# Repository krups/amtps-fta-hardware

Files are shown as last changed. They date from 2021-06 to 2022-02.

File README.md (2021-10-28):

# amtps-fta
Design files for the additive manufacturing thermal of thermal protection systems (AMTPS) flight test article (FTA)

See [documentation/amtps-fta-harware-manual.pdf](documentation/amtps-fta-harware-manual.pdf)

For an overview of the work, see the presentation here [documentation/presentation.pdf](documentation/presentation.pdf)

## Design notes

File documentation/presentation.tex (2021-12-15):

\documentclass[UKenglish]{beamer}

\usetheme{UiB}

\usepackage[utf8]{inputenx} % For æ, ø, å
\usepackage{csquotes}       % Quotation marks
\usepackage{microtype}      % Improved typography
\usepackage{amssymb}        % Mathematical symbols
\usepackage{mathtools}      % Mathematical symbols
\usepackage[absolute, overlay]{textpos} % Arbitrary placement
\setlength{\TPHorizModule}{\paperwidth} % Textpos units
\setlength{\TPVertModule}{\paperheight} % Textpos units
\usepackage{tikz}
\usepackage{pgf}
\usepackage{subcaption}
\usetikzlibrary{overlay-beamer-styles}  % Overlay effects for TikZ
\usepackage[ruled,vlined]{algorithm2e}
\captionsetup[figure]{labelformat=empty}% redefines the caption setup of the figures environment in the beamer class.

\author{Matt Ruffner}
\title{AMPTS FTA Avionics Design}
%\subtitle{Parzen Windowing}

\newcommand{\ddrev}{E}

\begin{document}

\section{Overview}
% Use
%
%     \begin{frame}[allowframebreaks]{Title}
%
% if the TOC does not fit one frame.
\begin{frame}{Table of contents}
    \tableofcontents[currentsection]
\end{frame}

%%%%%%%%%%%%%%%%%%%%%%%%%%%%%%%%%%%%%%%%%%%%%
%%%%%%%%%%%%%%%%%%%%%%%%%%%%%%%%%%%%%%%%%%%%%
%%%%%%%%%%%%%%%%%%%%%%%%%%%%%%%%%%%%%%%%%%%%%
\section{Requirements}
\label{sec:requirements}
\hidelogo
\begin{frame}[allowframebreaks]{Requirements}

	Based on revision (\ddrev) of the flight test requirements document.
	
	\begin{enumerate}
		\item Instrumentation and telemetry
		\begin{enumerate}
			\item Shall support betwen 8 and 20 thermocouples of varying type
			\item Shall support up to 6 absolute pressure sensors
			\item Shall support at least 1 intertial measurement unit (IMU)
			\item Should support 1 heat flux sensor
			\item Shall contain a GPS for recovery operations, accurate to with 100m
			\item Capsule shall contain an internal barometric pressure sensor 
			\item Telemetry data shall be collected at a minumum of 10Hz
			\item Telemetry data shall be stored to onboard nonvolatile memory that will survive landing
			\item Location telemetry shall be transmitted through a vehicle-to-ground system (e.g. Iridium satellite, Xbee)
			\item Recovery location should be broadcasted at least once every 5 minutes post-flight
		\end{enumerate}
		\item Activation and flight sequencing
		\begin{enumerate}
			\item Shall be powered through the duration of the flight
			\item Shall support continuous operation between -20 deg C and 80 deg C
			\item Shall support pre-launch activation on the ground; should support low power mode prior to deployment
			\item Shall detect and/or sense when deployment has occurred via interfacing with the launch vehicle
			\item Shall transmit in-flight telemetry with position information
			\item In-flight telemetry should contain capsule velocity 
			\item Shall trigger parachute deployment at a specified time
		\end{enumerate}
		\item Physical properties
		\item Avionics hardware shall weigh under or around 0.5kg
		\item Shall cost under \$3,000
	\end{enumerate}
\end{frame}

%%%%%%%%%%%%%%%%%%%%%%%%%%%%%%%%%%%%%%%%%%%%%
%%%%%%%%%%%%%%%%%%%%%%%%%%%%%%%%%%%%%%%%%%%%%
%%%%%%%%%%%%%%%%%%%%%%%%%%%%%%%%%%%%%%%%%%%%%
\section{Overview}
\begin{frame}{Overview}
	
	\begin{figure}
		\centering
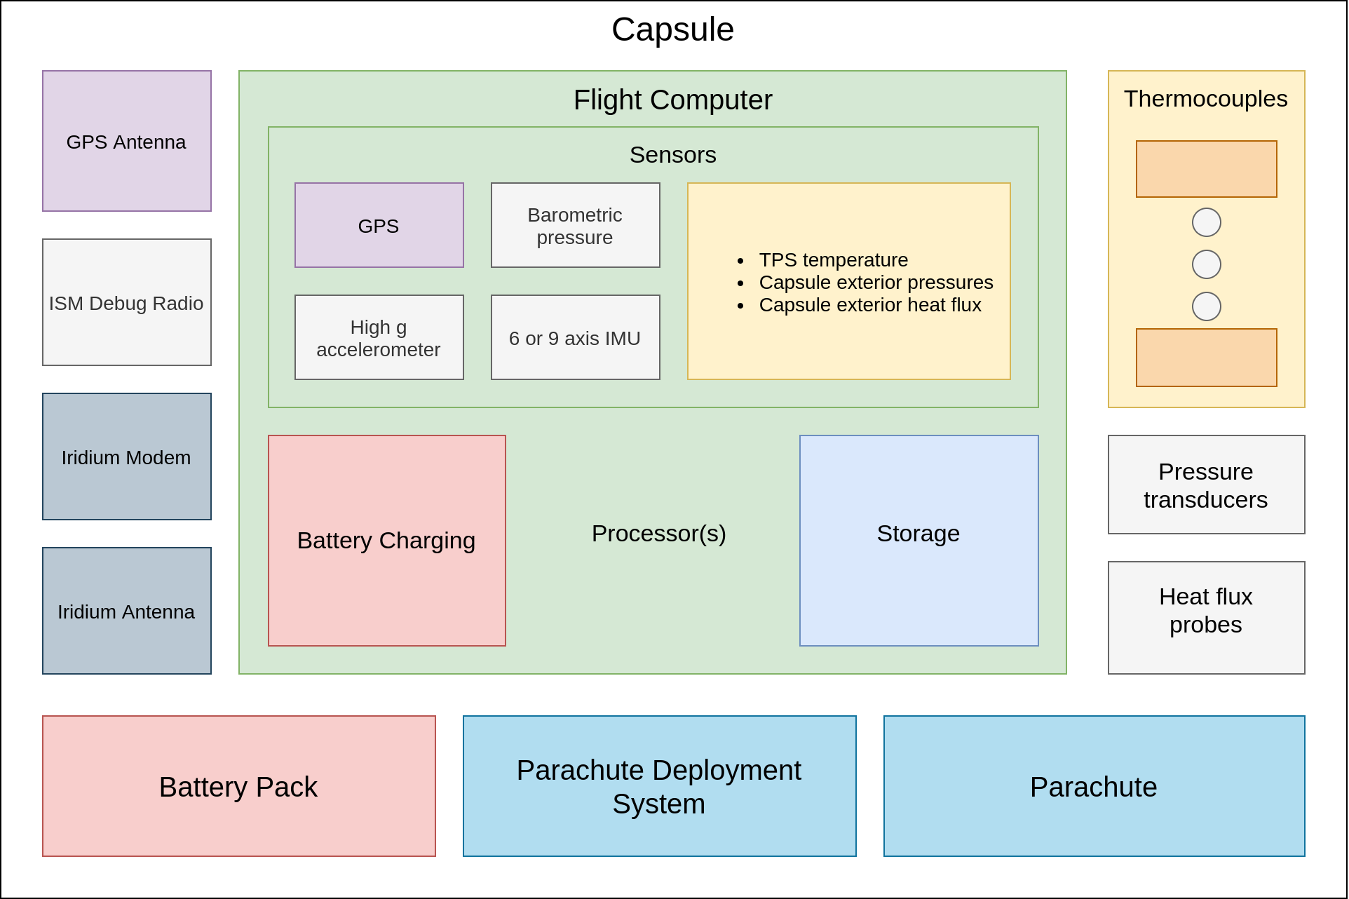
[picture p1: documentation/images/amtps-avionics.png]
		
		%\caption{Capsule component overview, showing the various functional blocks.}
		%\label{fig:capsule-overview}
	\end{figure}

\end{frame}

%%%%%%%%%%%%%%%%%%%%%%%%%%%%%%%%%%%%%%%%%%%%%
%%%%%%%%%%%%%%%%%%%%%%%%%%%%%%%%%%%%%%%%%%%%%
%%%%%%%%%%%%%%%%%%%%%%%%%%%%%%%%%%%%%%%%%%%%%
\section{Temperature and Pressure Measurement}
\begin{frame}{Temperature and Pressure Measurement)}
	
	\begin{figure}[h!]
		\centering
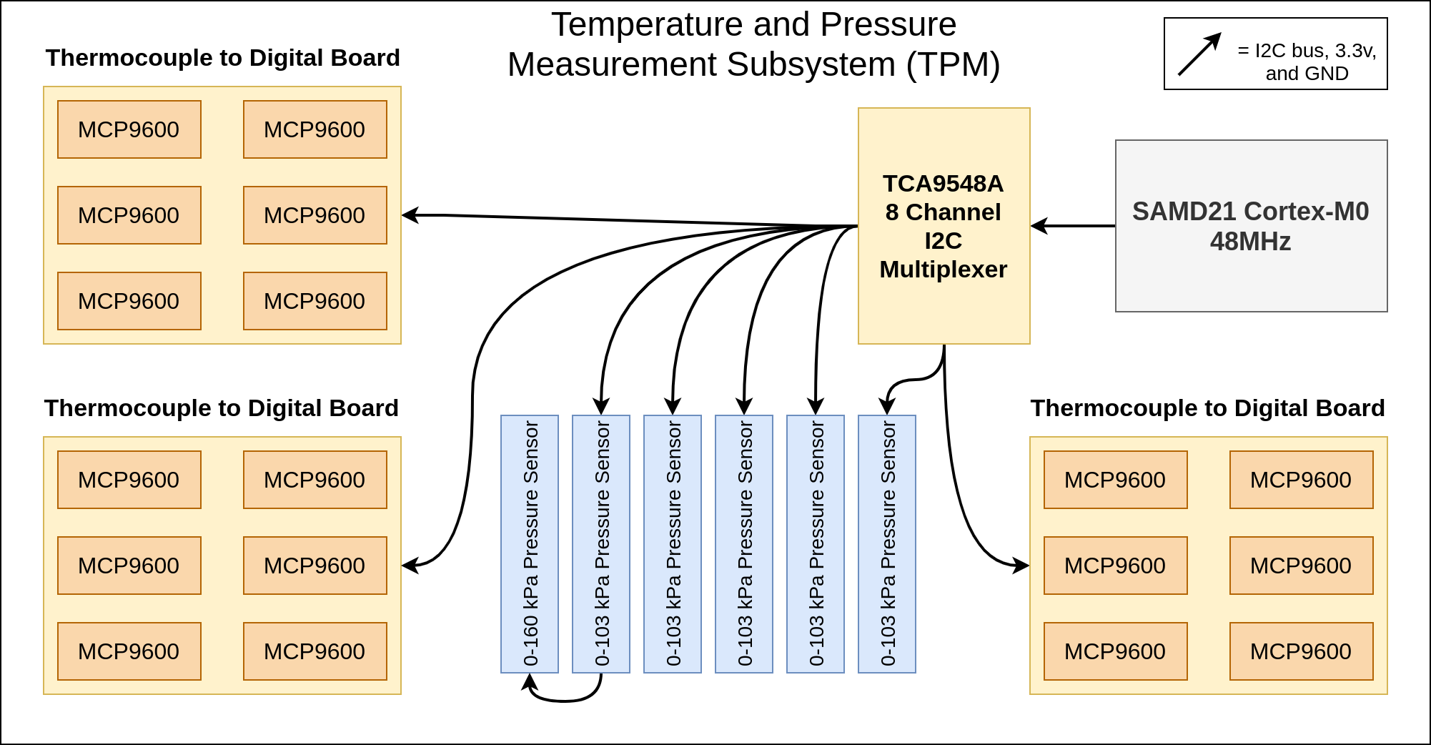
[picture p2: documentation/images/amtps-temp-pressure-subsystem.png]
		
		%\caption{Functional decomposition of the TPMS.}
		%\label{fig:tpms-overview}
	\end{figure}
	
\end{frame}

%%%%%%%%%%%%%%%%%%%%%%%%%%%%%%%%%%%%%%%%%%%%%
%%%%%%%%%%%%%%%%%%%%%%%%%%%%%%%%%%%%%%%%%%%%%
%%%%%%%%%%%%%%%%%%%%%%%%%%%%%%%%%%%%%%%%%%%%%
\section{Command and Data Handling}
\begin{frame}{Command and Data Handling}
	
	\begin{figure}[h!]
		\centering
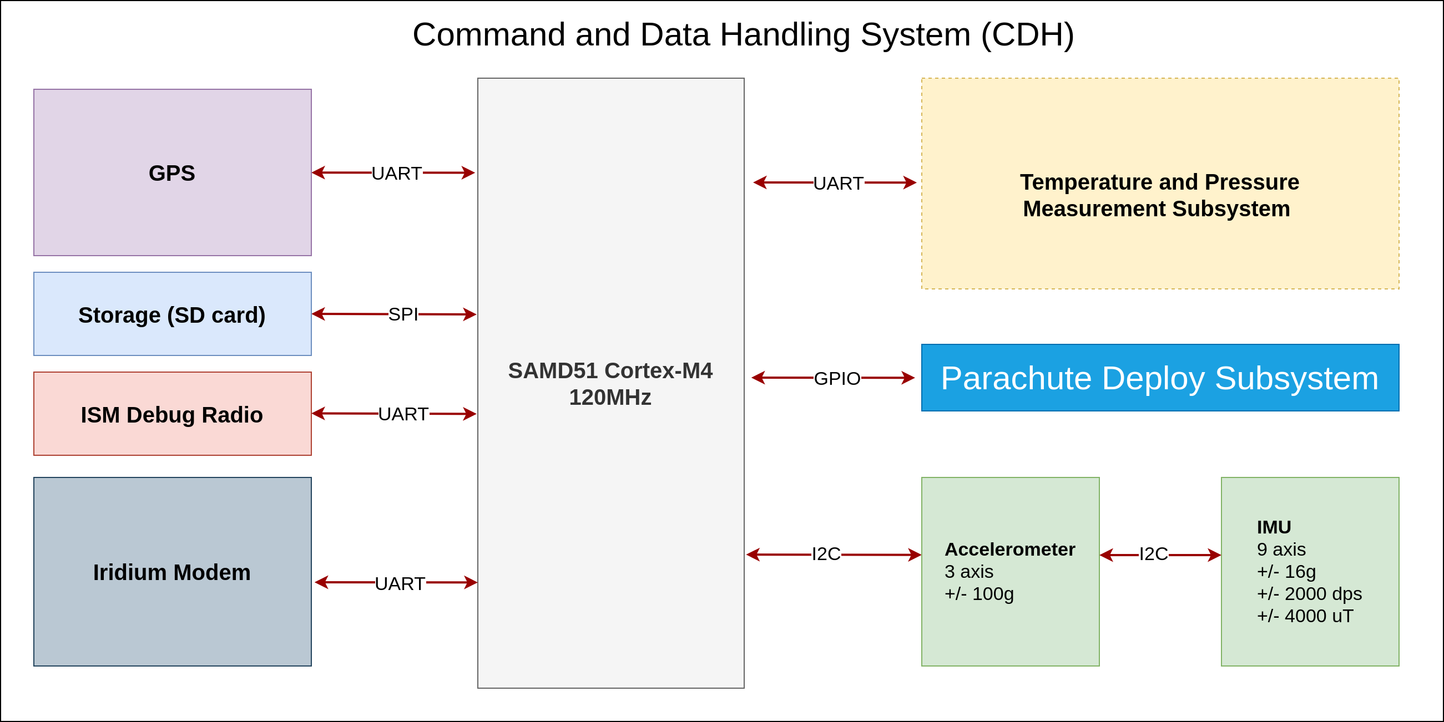
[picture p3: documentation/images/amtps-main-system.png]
		
		%\caption{Main functional components of the capsule and the communication buses between them.}
		%\label{fig:main-overview}
	\end{figure}
	
\end{frame}

%%%%%%%%%%%%%%%%%%%%%%%%%%%%%%%%%%%%%%%%%%%%%
%%%%%%%%%%%%%%%%%%%%%%%%%%%%%%%%%%%%%%%%%%%%%
%%%%%%%%%%%%%%%%%%%%%%%%%%%%%%%%%%%%%%%%%%%%%
\section{Parachute Control}
\begin{frame}{Parachute Control}

	\begin{figure}[h!]
		\centering
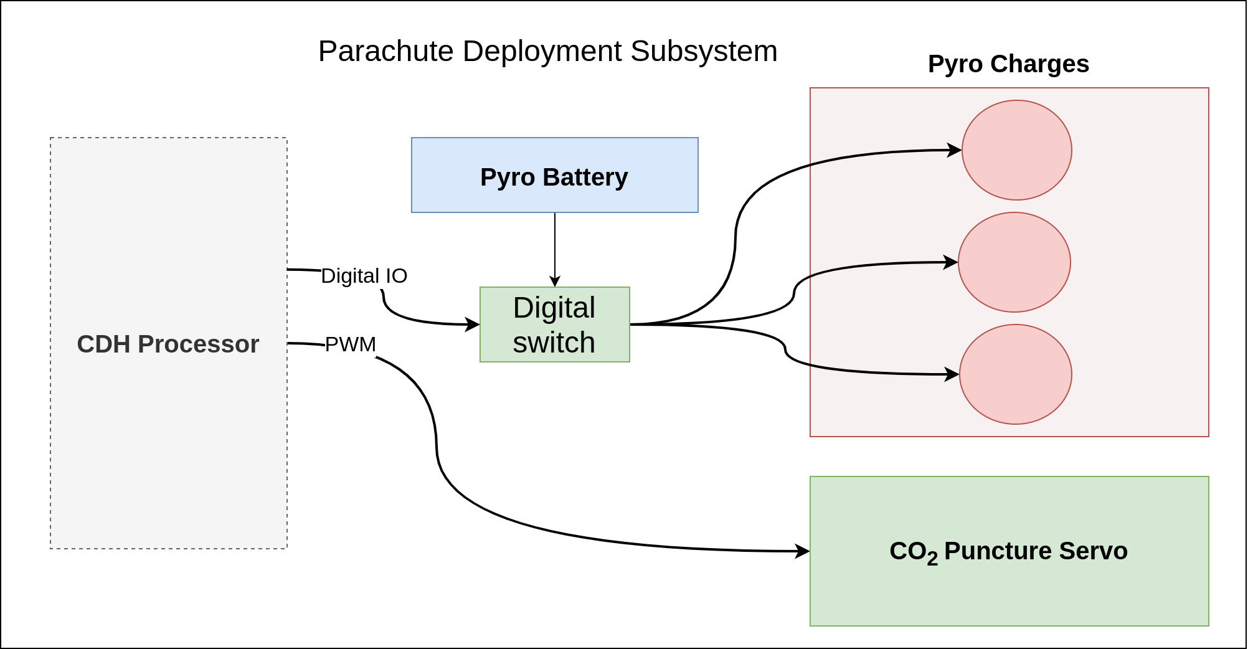
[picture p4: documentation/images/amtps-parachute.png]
		
		%\caption{Main functional components of the capsule and the communication buses between them.}
		%\label{fig:main-overview}
	\end{figure}
	
\end{frame}

%%%%%%%%%%%%%%%%%%%%%%%%%%%%%%%%%%%%%%%%%%%%%
%%%%%%%%%%%%%%%%%%%%%%%%%%%%%%%%%%%%%%%%%%%%%
%%%%%%%%%%%%%%%%%%%%%%%%%%%%%%%%%%%%%%%%%%%%%
\section{Prototype Hardware}
\begin{frame}[allowframebreaks]{Prototype Hardware}
	
	\begin{itemize}
		\item TC to digital expansion
	\end{itemize}
	\begin{figure}[h!]
		\begin{subfigure}{0.4\textwidth}
		\centering
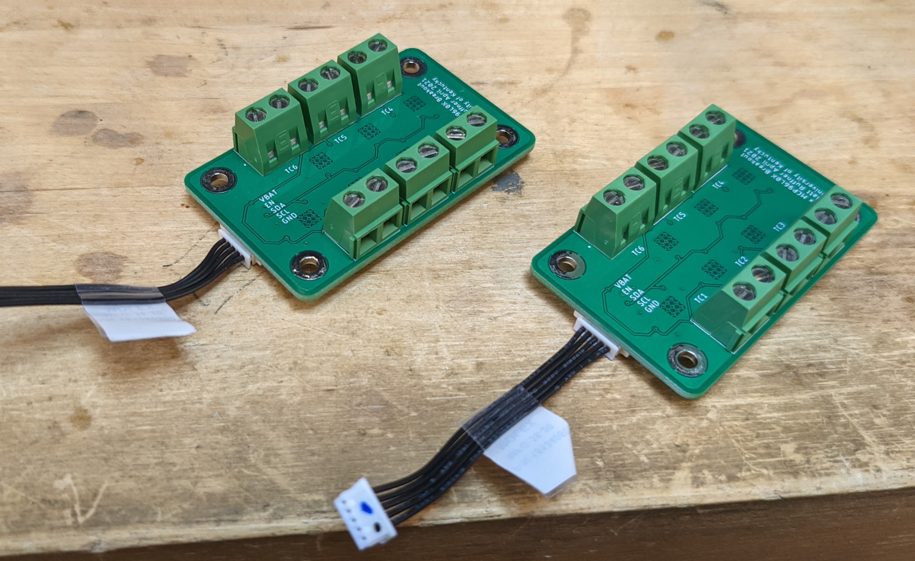
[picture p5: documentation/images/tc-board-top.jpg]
		
		\caption{Six channel MCP9600 breakout (top).}
		%\label{fig:tpms-overview}
		\end{subfigure}
		\qquad
		\begin{subfigure}{0.4\textwidth}
			\centering
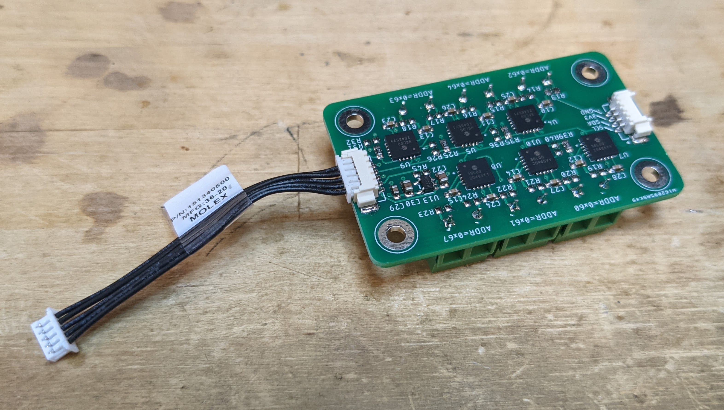
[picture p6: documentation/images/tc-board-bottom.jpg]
			
			\caption{Six channel MCP9600 breakout (bottom).}
			%\label{fig:tpms-overview}
		\end{subfigure}
		%\label{fig:tpms-overview}
	\end{figure}
	
	\begin{itemize}
		\item Semtech SX1276-based 915 MHz ISM band LoRa modem for capsule-to-ground telemetry
		\item 1S2P LiPo for power
		\item Physical switch at capsule/vehicle interface for activation.
	\end{itemize}
	
	\begin{figure}[h!]
		\centering
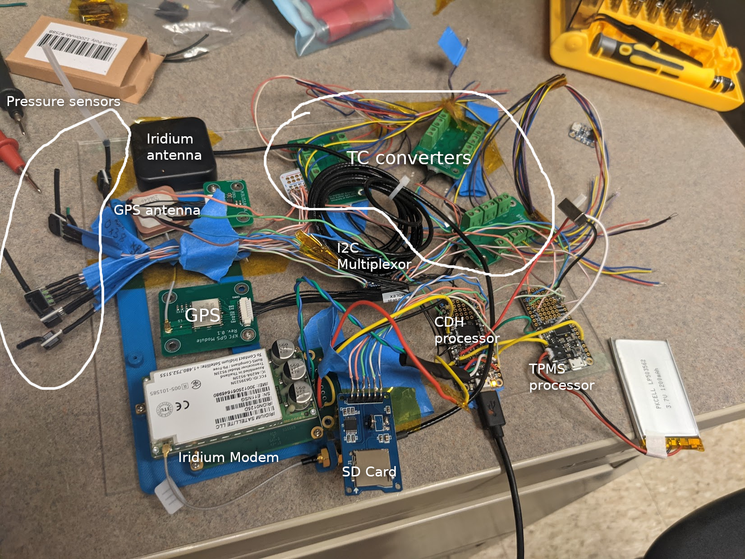
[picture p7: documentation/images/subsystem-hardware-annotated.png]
		
		\caption{Full system.}
		%\label{fig:tpms-overview}
	\end{figure}

\end{frame}

\section{Final Design Considerations}
\begin{frame}[allowframebreaks]{Final Design Considerations}
	
	\begin{itemize}
		\item \textbf{Supply chain constraints} - bare SAMD21/51 processors are hard to find on Digikey/Mouser etc. but pre-made development boards from Adafruit are still available.
	\end{itemize}	

	\begin{figure}[h!]
		\begin{subfigure}{0.4\textwidth}
			\centering
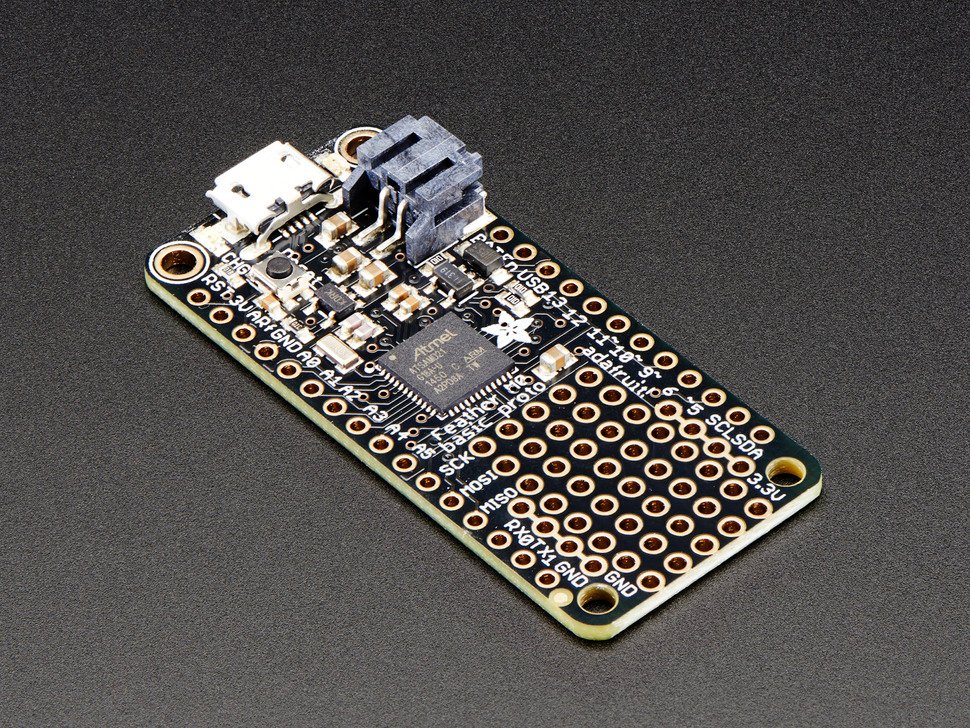
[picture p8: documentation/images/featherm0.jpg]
			
			\caption{Adafruit SAMD21 48MHz Cortex-M0 carrier \tiny{\url{https://www.adafruit.com/product/2772}}}
		\end{subfigure}
		\qquad
		\begin{subfigure}{0.4\textwidth}
			\centering
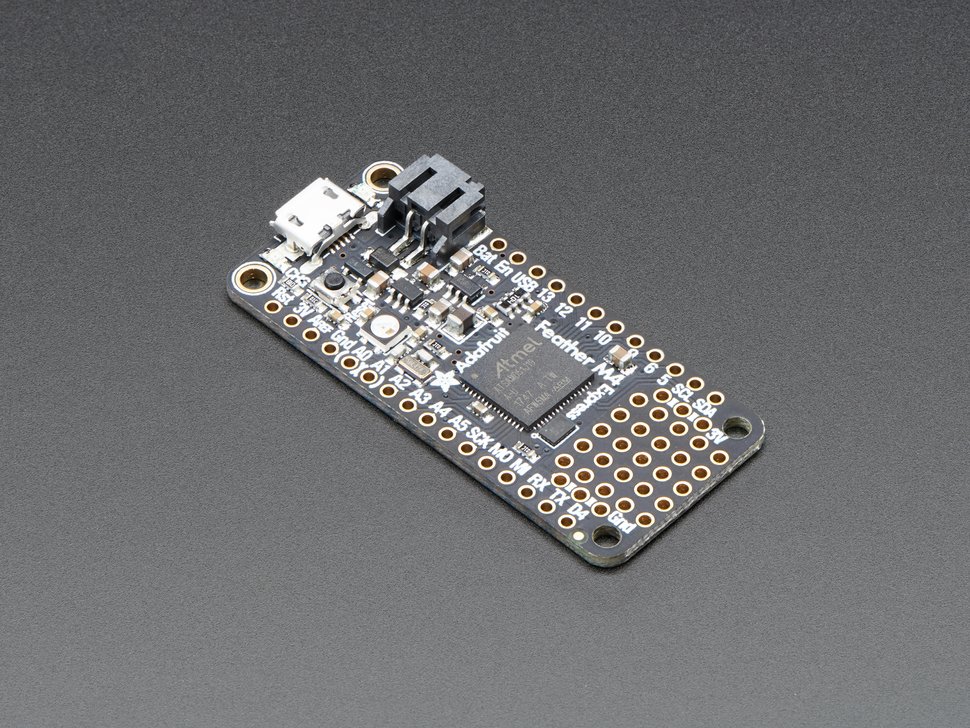
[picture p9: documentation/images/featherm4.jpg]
			
			\caption{Adafruit SAMD51 120MHz Cortex-M4 carrier \tiny{\url{https://www.adafruit.com/product/3857}}}
		\end{subfigure}
		%\label{fig:tpms-overview}
	\end{figure}

	\begin{itemize}
		\item \textbf{Plenty of processor overhead} - recording 12 channels of IMU and accelerometer data to an SD card at 100Hz requires strict timing and interrupt handling
		\item Current planned revision is to separate IMU and high-g accelerometer interfacing to its own Cortex-M0 processor.
	\end{itemize}

	\begin{figure}
		\centering
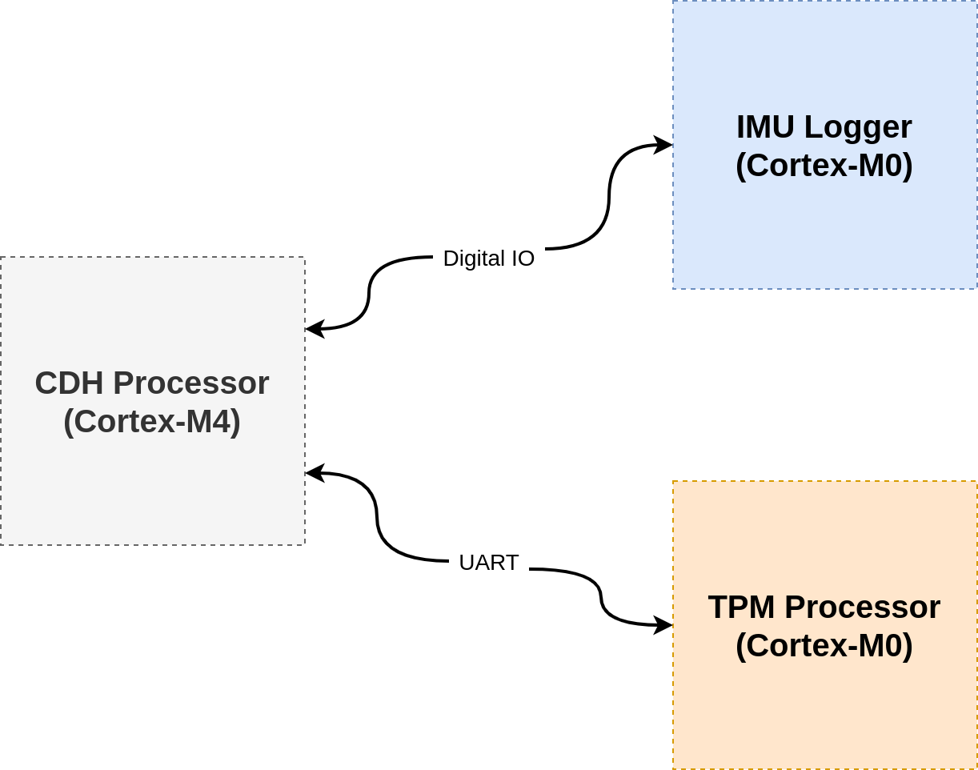
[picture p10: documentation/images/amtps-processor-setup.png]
		
		\caption{Processor separation of responsibilities.}		
	\end{figure}

\end{frame}

\section{Software Design}
\begin{frame}{Software Overview}
	
	\begin{itemize}
		\item Adafruit Feather line of boards is Arduino compatible
		\item SAMD21/51 series of processors has easily reconfigurable SERCOMs to support multiple hardware serial ports 
		\item FreeRTOS tasks, queues, and semaphores allow for simple and reliable transfer of data and atomic hardware access
		\item Open source libraries available for all sensors
		\item All hardware design files and firmware, as well as ground assist tools for plotting recorded data are version controlled on private Github repositories:
		\begin{itemize}
			\item \url{https://github.com/krups/amtps-fta-hardware}
			\item \url{https://github.com/krups/amtps-fta-software}
		\end{itemize}	
	\end{itemize}
	
\end{frame}

\section{PCB Designs}
\begin{frame}[allowframebreaks]{Rev 2 board designs}
	
	\begin{figure}[h!]
		\centering
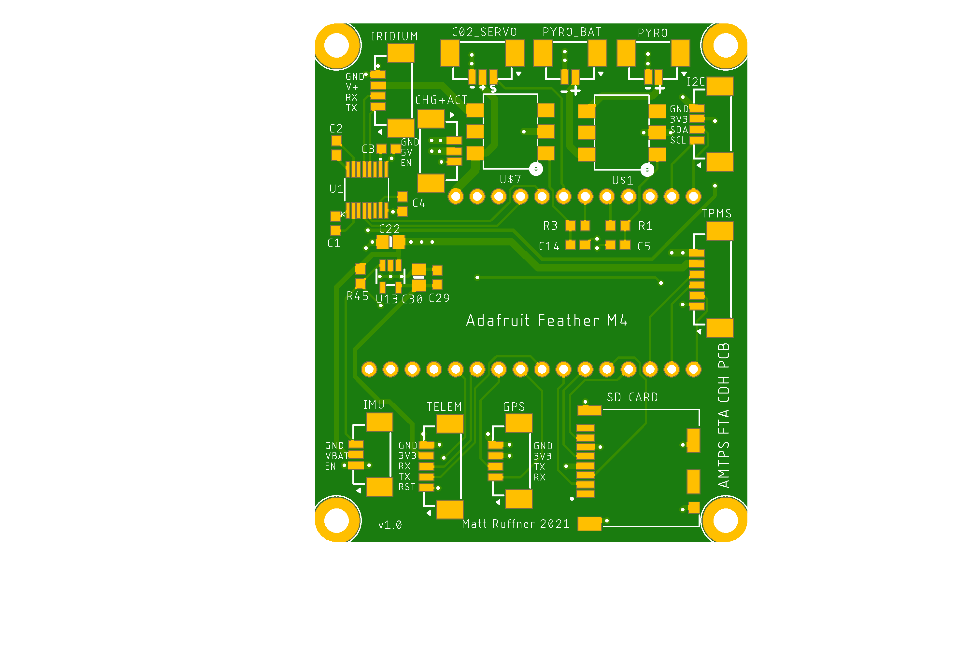
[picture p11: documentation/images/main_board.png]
		
		\caption{CDH processor carrier PCB.}
		%\label{fig:tpms-overview}
	\end{figure}

	\begin{figure}[h!]
		\centering
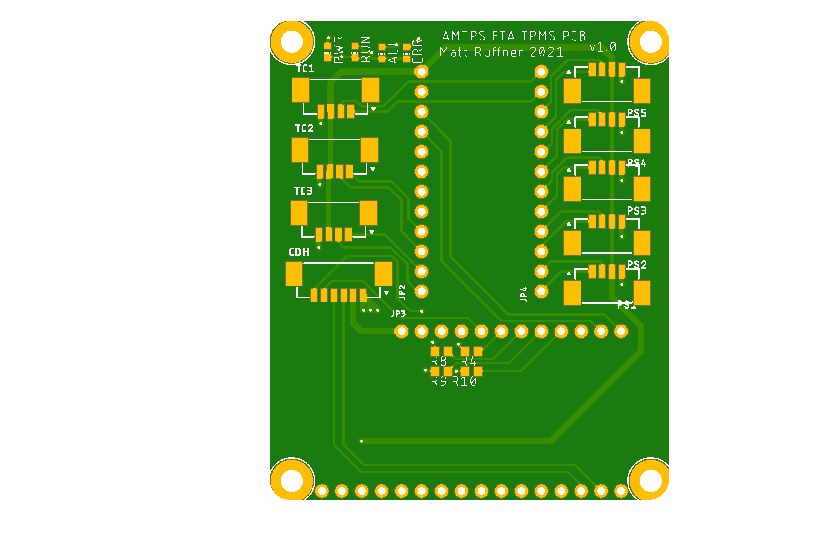
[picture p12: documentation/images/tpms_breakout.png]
		
		\caption{TMP processor carrier PCB.}
		%\label{fig:tpms-overview}
	\end{figure}

	\begin{figure}[h!]
		\centering
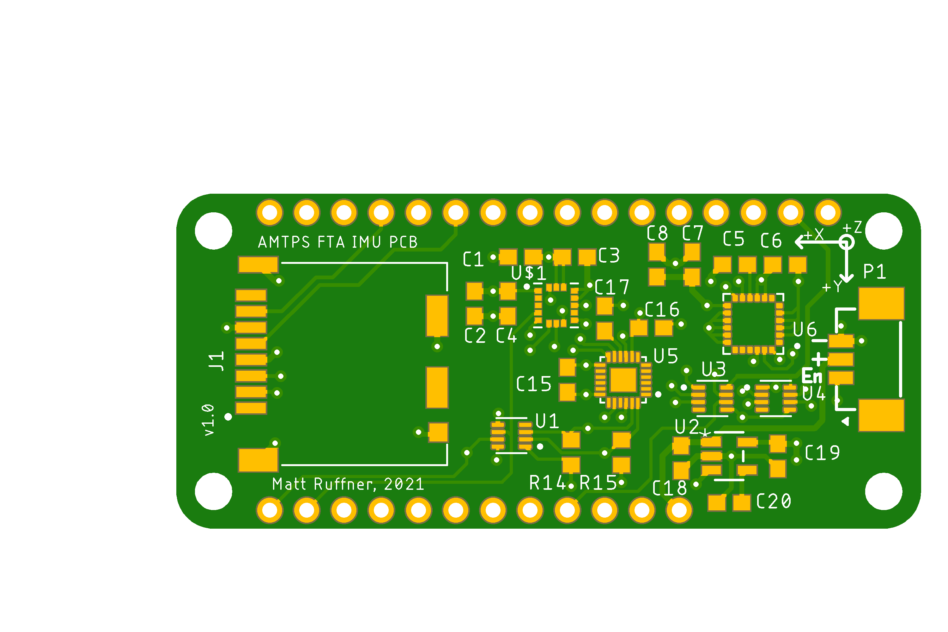
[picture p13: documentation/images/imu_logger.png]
		
		\caption{IMU logger processor carrier PCB.}
		%\label{fig:tpms-overview}
	\end{figure}

\end{frame}

\section{Schematics}

\begin{frame}[allowframebreaks]{Feather M0/M4 Schematics}
\begin{figure}[H]
	\centering
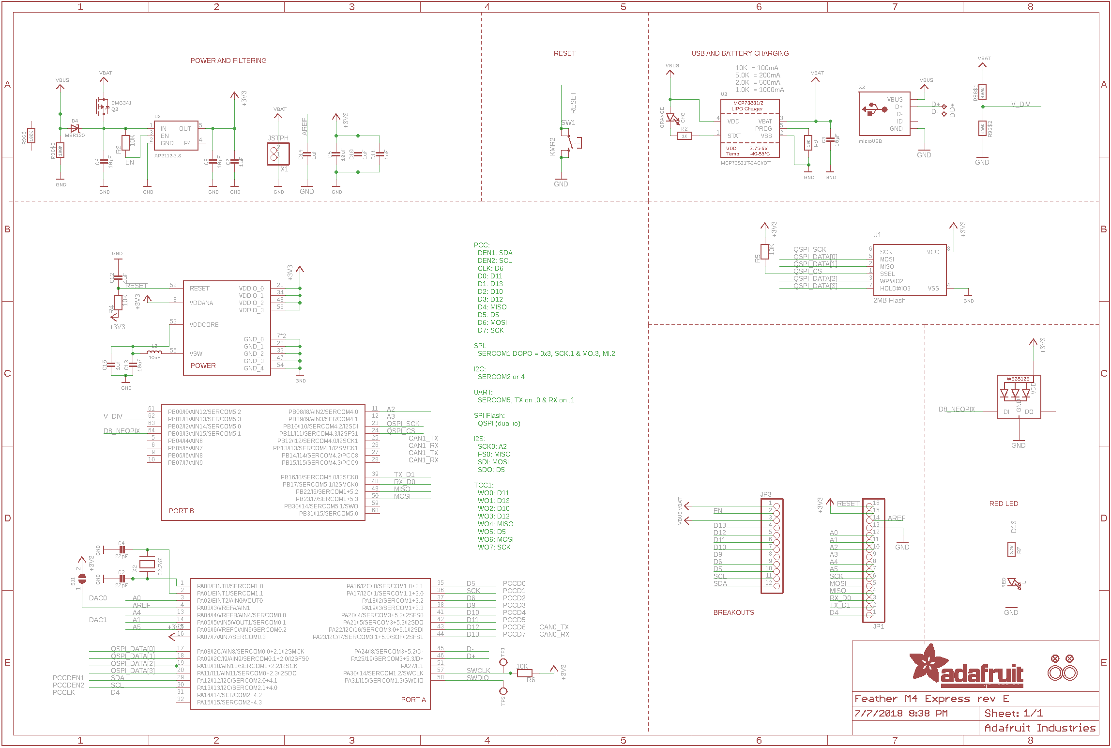
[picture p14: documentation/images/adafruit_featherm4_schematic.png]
	
	%\caption{Feather M4 Express schematic, used in the main CDH board.}
	\label{fig:schematic-featherm4}
\end{figure}
\begin{figure}[H]
	\centering
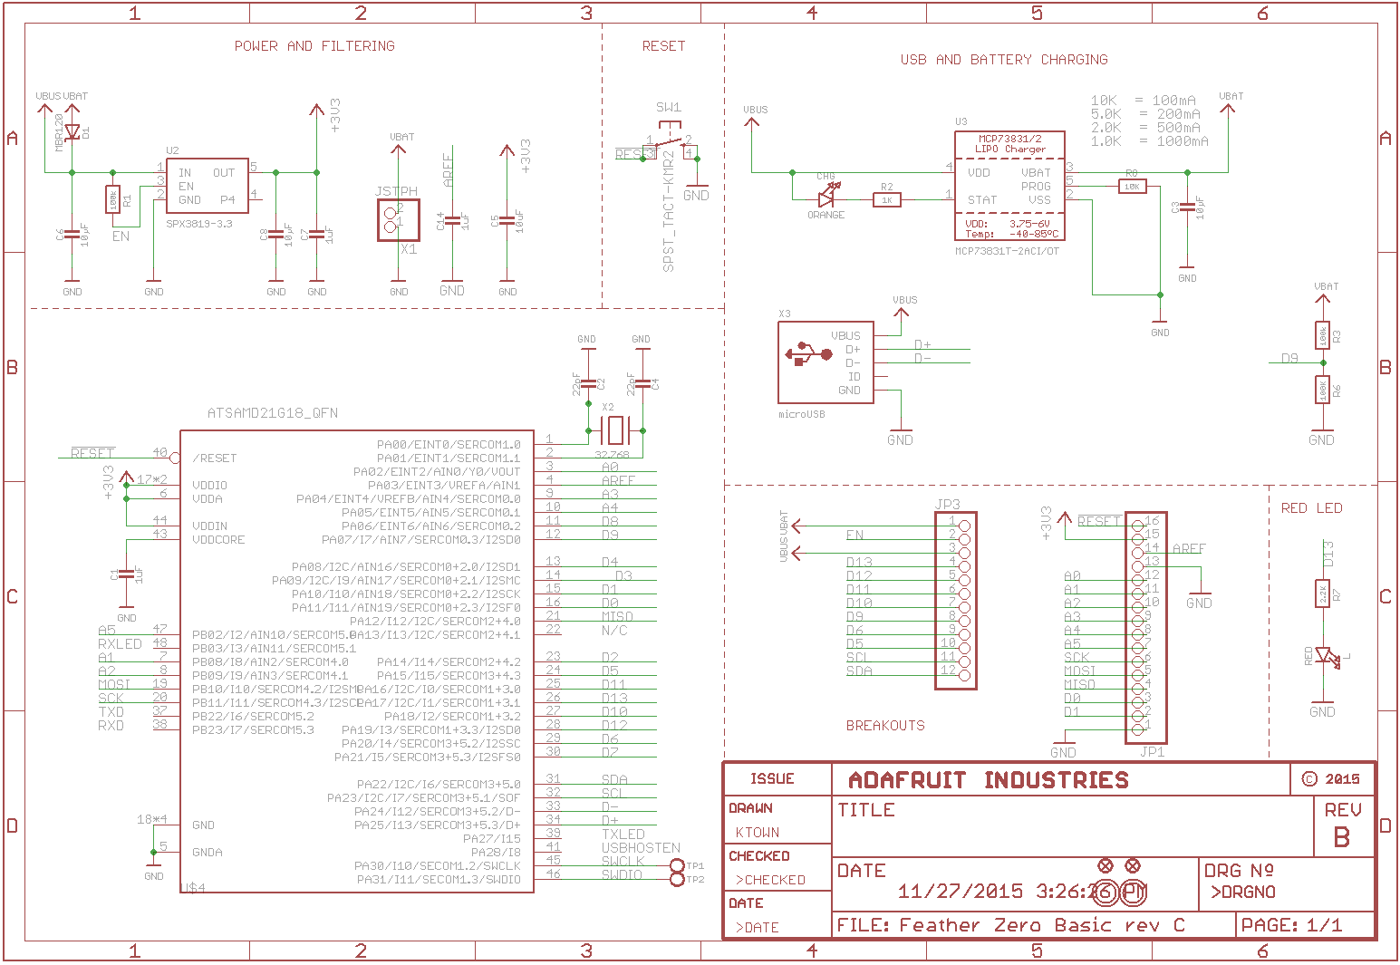
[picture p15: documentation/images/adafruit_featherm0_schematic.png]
	
	%\caption{Feather M0 schematic, used in the IMU logger and TPM boards.}
	\label{fig:schematic-featherm0}
\end{figure}
\end{frame}

\begin{frame}[allowframebreaks]{TC to Digital Schematics}
%Figures \ref{fig:schematic-tc-breakout-p1} and \ref{fig:schematic-tc-breakout-p2} show the schematics of the 6 channel TC to digital converter breakout board.
\begin{figure}[H]
	\centering
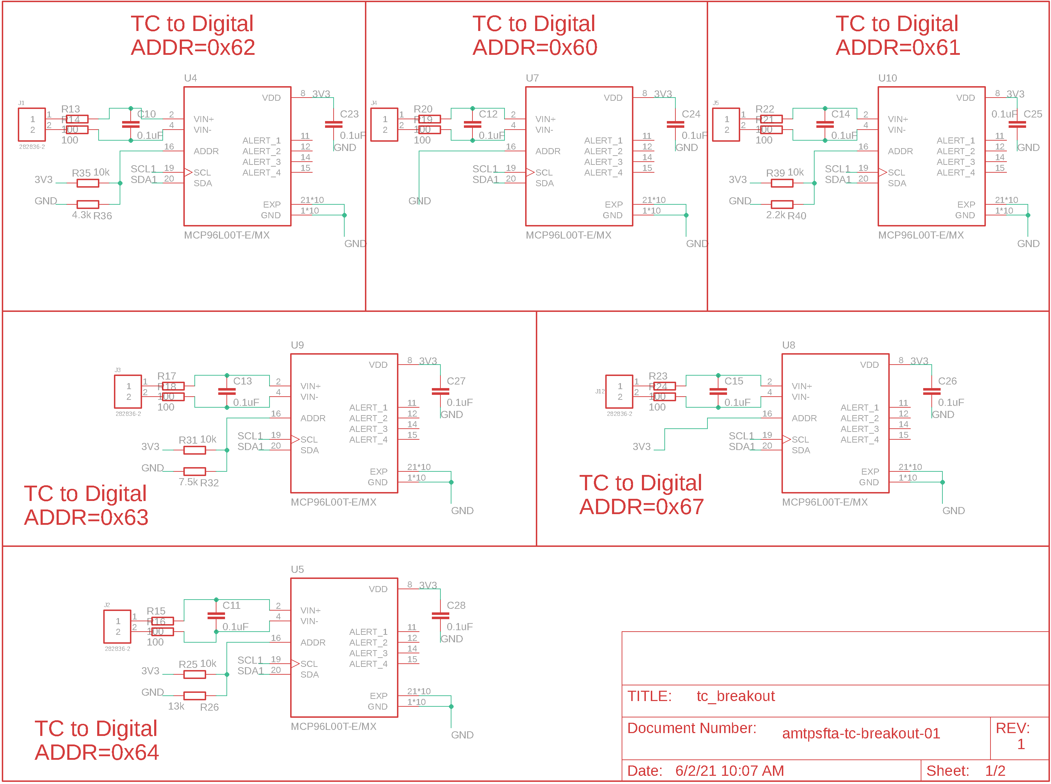
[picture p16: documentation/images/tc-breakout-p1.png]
	
	%\caption{TC to digital schematics, page 1/2}
	\label{fig:schematic-tc-breakout-p1}
\end{figure}

\begin{figure}[H]
	\centering
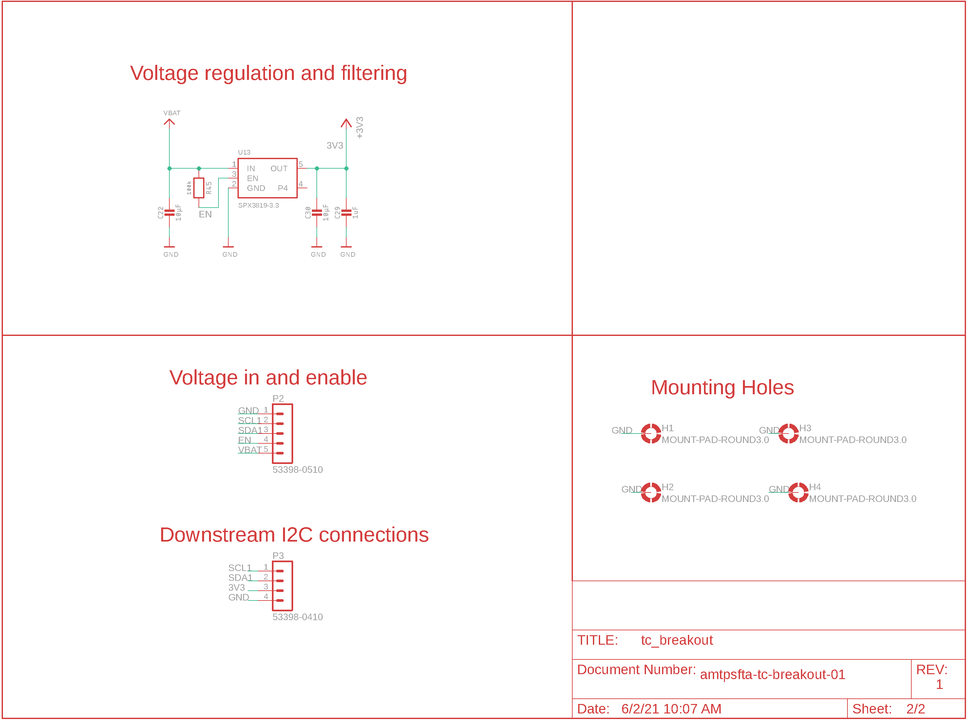
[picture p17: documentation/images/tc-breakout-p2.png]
	
	%\caption{TC to digital schematics, page 2/2}
	\label{fig:schematic-tc-breakout-p2}
\end{figure}
\end{frame}

\begin{frame}[allowframebreaks]{Main CDH Schematics}
%Figures \ref{fig:schematic-cdh-p1} and \ref{fig:schematic-cdh-p2} show the schematics of the main CDH PCB.
\begin{figure}[H]
	\centering
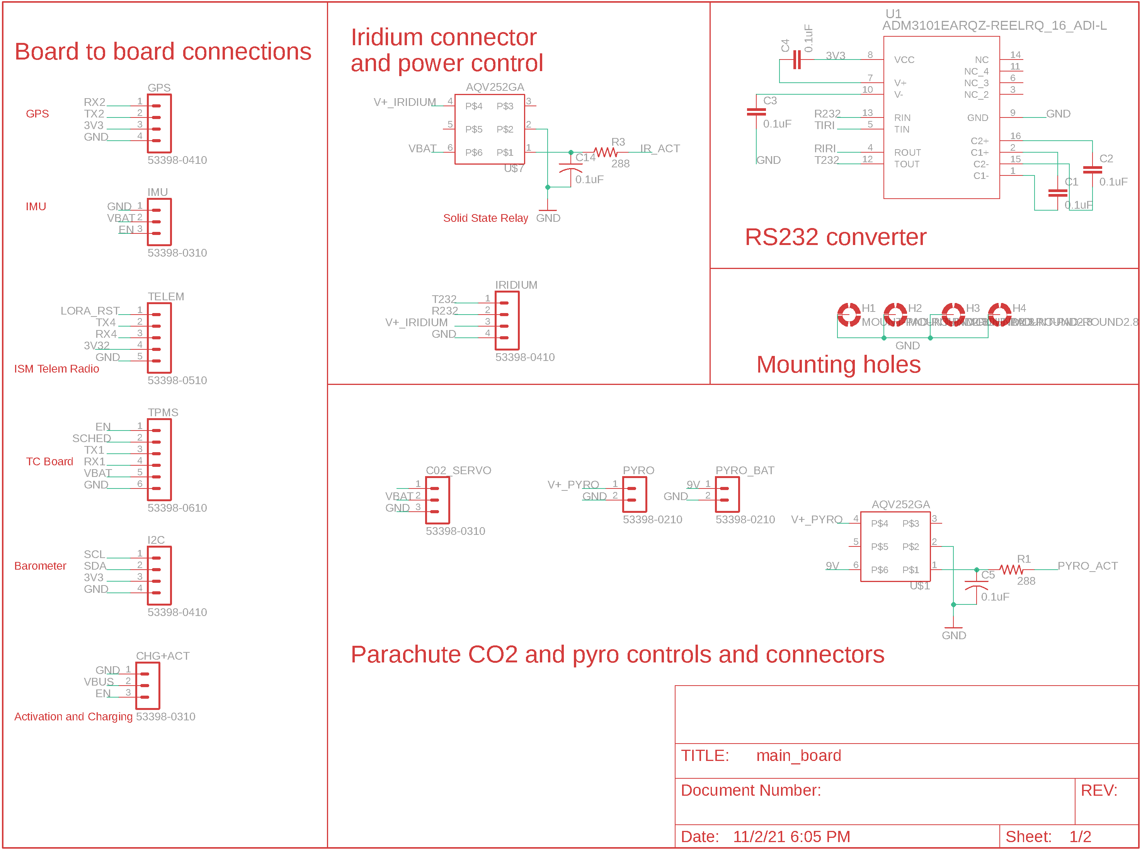
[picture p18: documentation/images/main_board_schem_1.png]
	
	%\caption{Main CDH schematics, page 1/2}
	\label{fig:schematic-cdh-p1}
\end{figure}
\begin{figure}[H]
	\centering
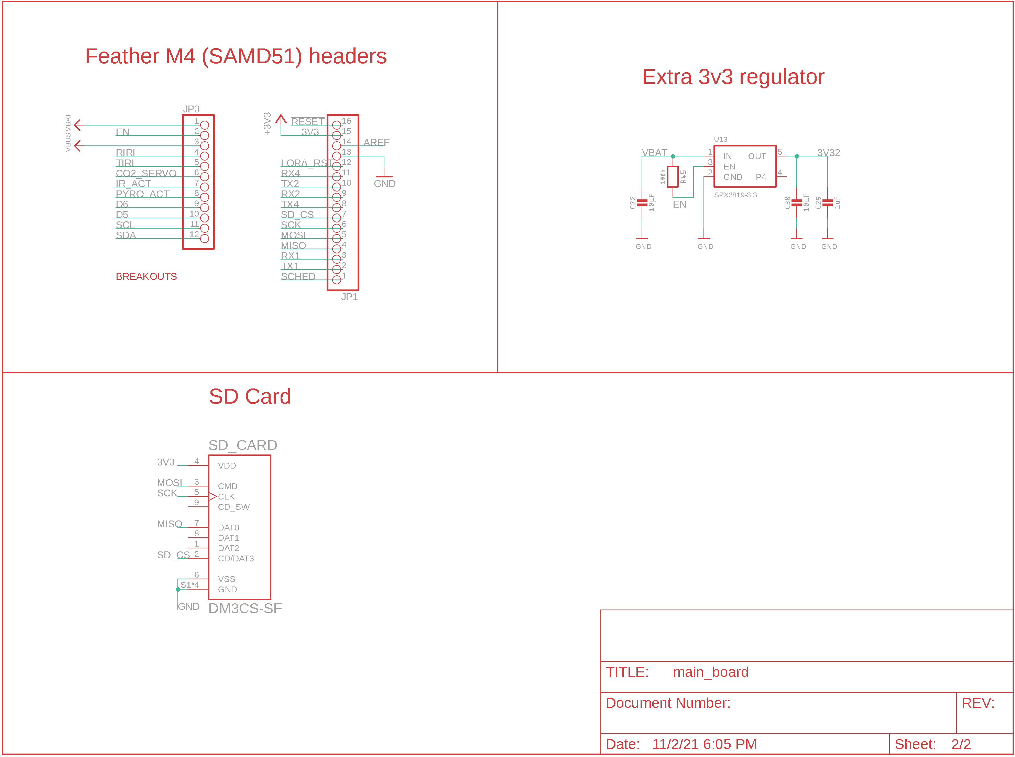
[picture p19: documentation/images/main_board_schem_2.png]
	
	%\caption{Main CDH schematics, page 2/2}
	\label{fig:schematic-cdh-p2}
\end{figure}
\end{frame}

\begin{frame}[allowframebreaks]{TPM Schematics}
%Figures \ref{fig:schematic-tpm-p1} and \ref{fig:schematic-tpm-p2} show the schematics of the TPM subsystem PCB.
\begin{figure}[H]
	\centering
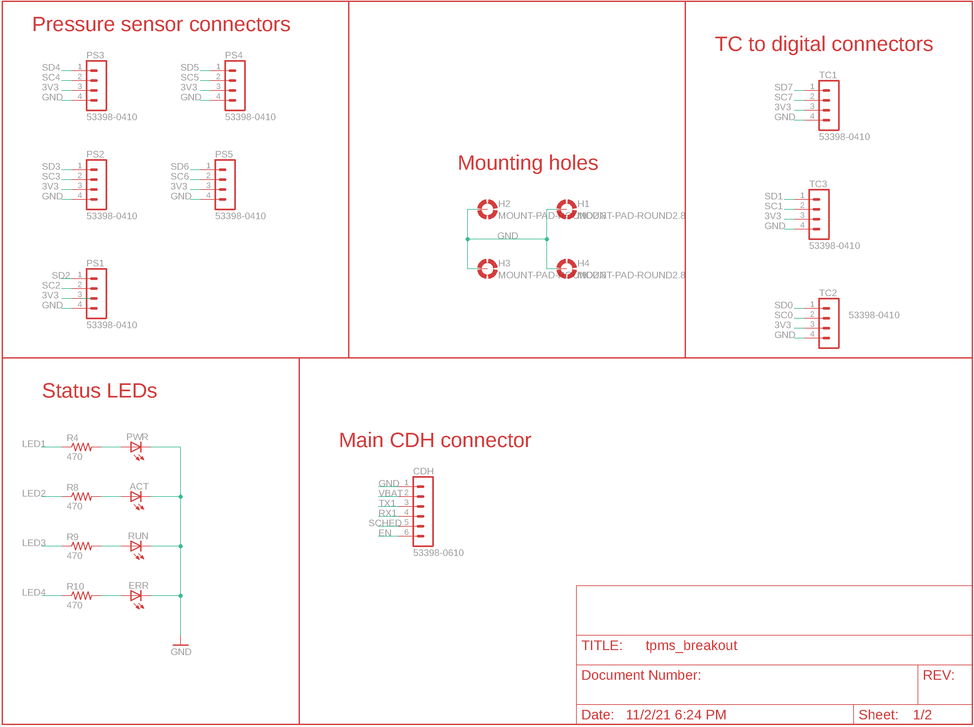
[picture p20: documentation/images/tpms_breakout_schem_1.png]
	
	%\caption{TPM schematics, page 1/2}
	\label{fig:schematic-tpm-p1}
\end{figure}
\begin{figure}[H]
	\centering
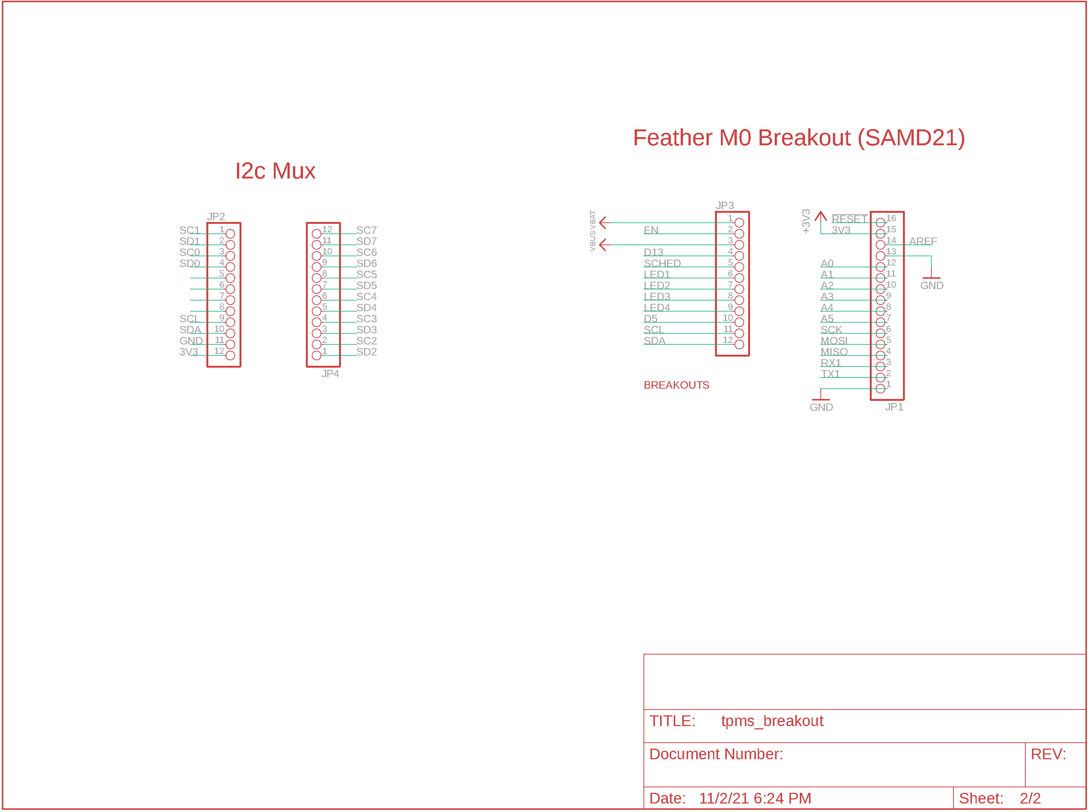
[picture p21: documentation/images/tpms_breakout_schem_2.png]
	
	%\caption{TPM schematics, page 2/2}
	\label{fig:schematic-tpm-p2}
\end{figure}
\end{frame}

\begin{frame}[allowframebreaks]{IMU Logger Schematics}
%Figures \ref{fig:schematic-imu-p1}, \ref{fig:schematic-imu-p2}, and \ref{fig:schematic-imu-p3} show the schematics of the IMU logger PCB.
\begin{figure}[H]
	\centering
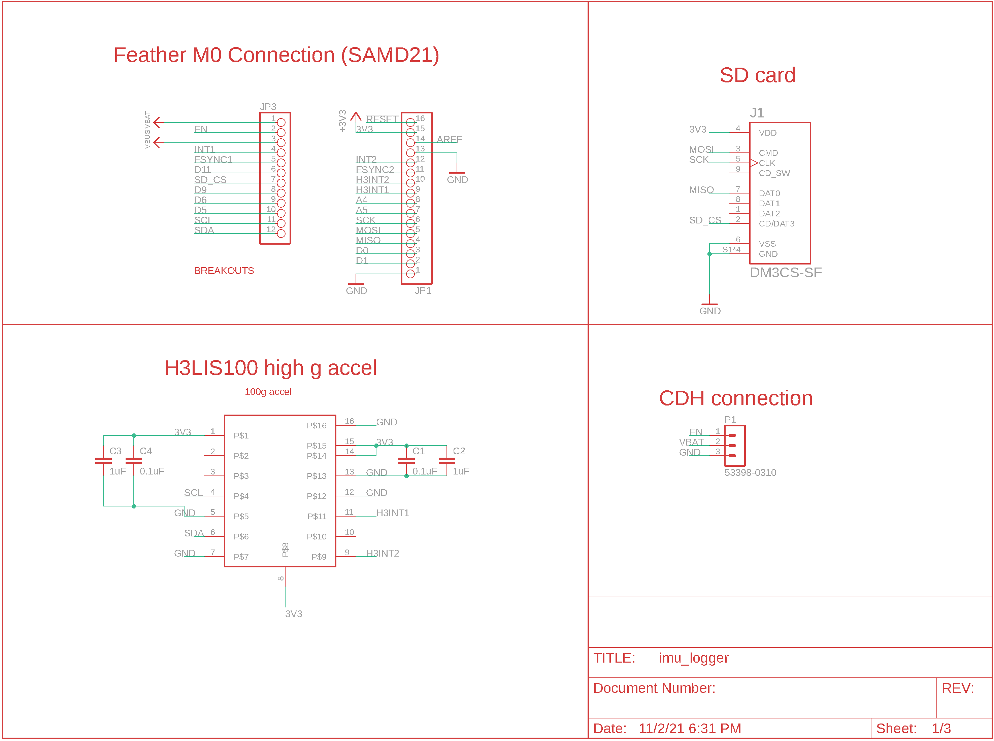
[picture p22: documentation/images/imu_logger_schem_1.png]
	
	%\caption{IMU logger schematics, page 1/3}
	\label{fig:schematic-imu-p1}
\end{figure}
\begin{figure}[H]
	\centering
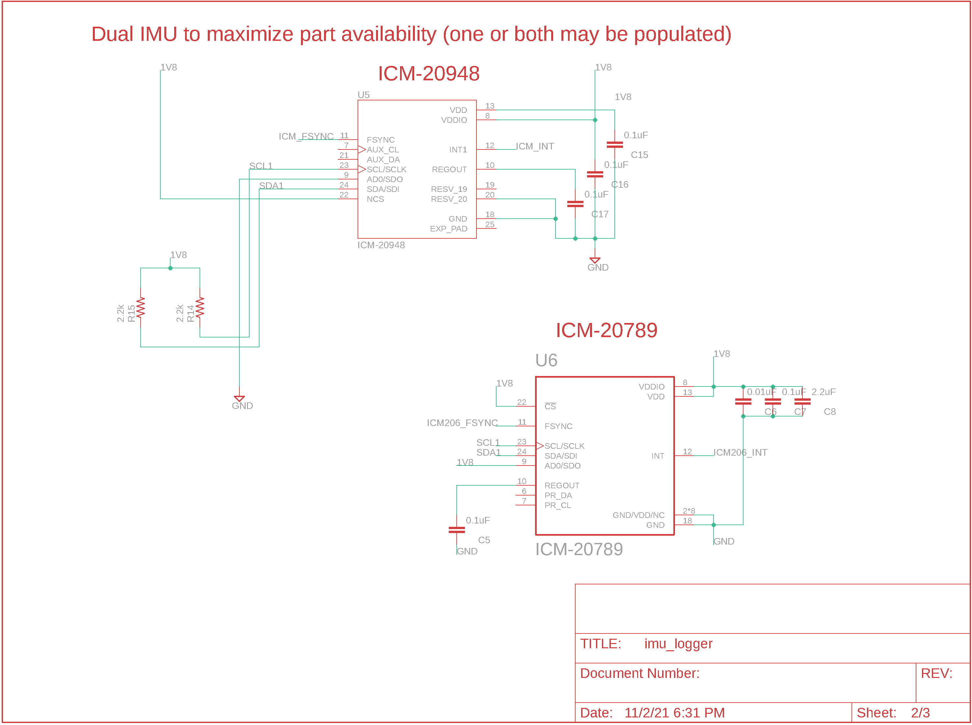
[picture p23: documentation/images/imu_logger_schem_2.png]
	
	%\caption{IMU logger schematics, page 2/3}
	\label{fig:schematic-imu-p2}
\end{figure}
\begin{figure}[H]
	\centering
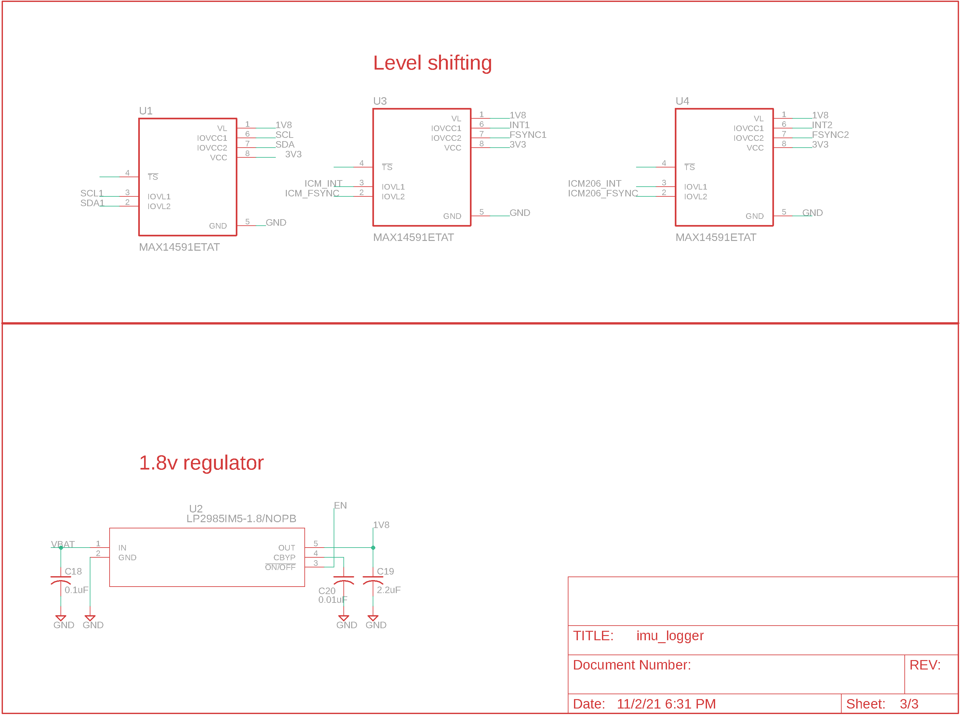
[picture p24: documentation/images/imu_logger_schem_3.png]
	
	%\caption{Page 3/3}
	\label{fig:schematic-imu-p3}
\end{figure}
\end{frame}

\end{document}

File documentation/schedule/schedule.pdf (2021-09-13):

Task | June | July | August | September | October | November | December

Outline mission profile and develop software for activation, data acquisition, mission timing, and parachute deployment

Assemble and test sensor evaluation boards and validate data acquisition hardware setup

Evaluate Iridium as a vehicle-to-ground telemetry system and verify there is no interference with GPS reciever

Determine most effective power distribution and charging system considering all system componets and durability requirements

Redesign temperature and pressure measurement subsystem to be more compact and easier for integration

Experiment with syntactic foam encasement of avionics

Experiment with durable storage and ways of transferring once avionics are encased in syntactic foam

Discussions about electrical interface with launch vehicle

Order revised boards, power electronics, and any needed components

Assemble revised hardware and build the full set of capsule hardware for mission simulation testing

Subsystem testing and test hardware integration

Test hardware complete, ready to build flight hardware + buffer

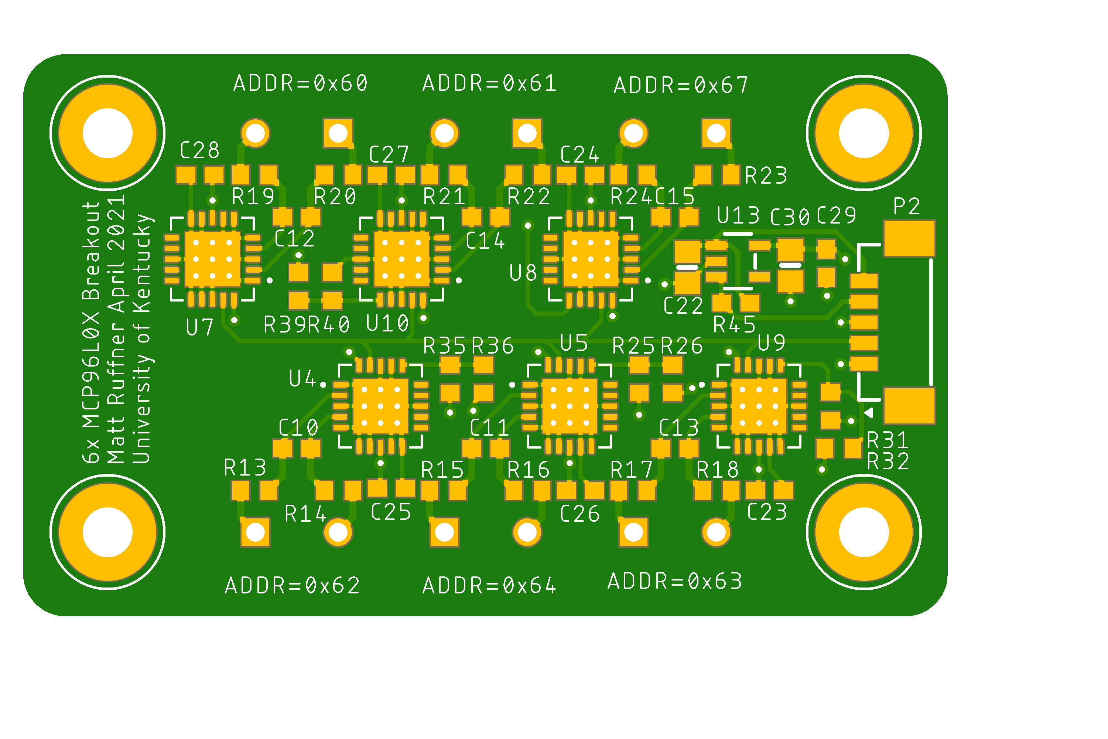
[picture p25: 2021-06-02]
pcb/tc_breakout/images/tc_breakout_top.png

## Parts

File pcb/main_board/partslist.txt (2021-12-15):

Partlist

Exported from main_board.sch at 12/15/21 12:45 AM

EAGLE Version 9.6.2 Copyright (c) 1988-2020 Autodesk, Inc.

Assembly variant: 

Part      Value                    Device                    Package                      Library             Sheet

C02_SERVO 53398-0310               53398-0310                53398-0310                   con-molex-picoblade 1
C5        0.1uF                    C-USC0603                 C0603                        adafruit            1
C6        0.1uF                    C-EUC0603                 C0603                        rcl                 1
C7        0.1uF                    C-EUC0603                 C0603                        rcl                 1
C8        0.1uF                    C-EUC0603                 C0603                        rcl                 1
C9        0.1uF                    C-EUC0603                 C0603                        rcl                 1
C14       0.1uF                    C-USC0603                 C0603                        adafruit            1
C22       10µF                     CAP_CERAMIC0805-NOOUTLINE 0805-NO                      microbuilder        2
C29       1uF                      CAP_CERAMIC0603_NO        0603-NO                      microbuilder        2
C30       10µF                     CAP_CERAMIC0805-NOOUTLINE 0805-NO                      microbuilder        2
CHG+ACT   53398-0310               53398-0310                53398-0310                   con-molex-picoblade 1
GPS       53398-0410               53398-0410                53398-0410                   con-molex-picoblade 1
H1        MOUNT-PAD-ROUND2.8       MOUNT-PAD-ROUND2.8        2,8-PAD                      holes               1
H2        MOUNT-PAD-ROUND2.8       MOUNT-PAD-ROUND2.8        2,8-PAD                      holes               1
H3        MOUNT-PAD-ROUND2.8       MOUNT-PAD-ROUND2.8        2,8-PAD                      holes               1
H4        MOUNT-PAD-ROUND2.8       MOUNT-PAD-ROUND2.8        2,8-PAD                      holes               1
I2C       53398-0410               53398-0410                53398-0410                   con-molex-picoblade 1
IMU       53398-0310               53398-0310                53398-0310                   con-molex-picoblade 1
IRIDIUM   53398-0410               53398-0410                53398-0410                   con-molex-picoblade 1
J1        MEM2067-02-180-00-A_REVB MEM2067-02-180-00-A_REVB  GCT_MEM2067-02-180-00-A_REVB MEM20267            2
JMP1      0R-JUMPA                 0R-JUMPA                  A0R-JMP                      jump-0r-smd         1
JP1                                HEADER-1X16ROUND          1X16_ROUND                   microbuilder        2
JP3                                HEADER-1X12               1X12_ROUND                   microbuilder        2
PYRO      53398-0210               53398-0210                53398-0210                   con-molex-picoblade 1
PYRO_BAT  53398-0210               53398-0210                53398-0210                   con-molex-picoblade 1
R1        288                      R-US_R0603                R0603                        adafruit            1
R2        288                      R-US_R0603                R0603                        adafruit            1
R3        288                      R-US_R0603                R0603                        adafruit            1
R4        288                      R-US_R0603                R0603                        adafruit            1
R45       100k                     RESISTOR_0603_NOOUT       0603-NO                      microbuilder        2
SJ1                                SJ                        SJ                           jumper              1
TELEM     53398-0510               53398-0510                53398-0510                   con-molex-picoblade 1
TPMS      53398-0610               53398-0610                53398-0610                   con-molex-picoblade 1
U$1       AQV252GA                 AQV252GA                  DIP6                         TI_radio            1
U$2       UM3232EEAE               UM3232EEAE                RQ_16_ADI                    ADM310              1
U$7       AQV252GA                 AQV252GA                  DIP6                         TI_radio            1
U2        SSM6J414TU               SSM6J414TU                UF6_TOS                      ssm6j414tu          1
U3        SSM6J414TU               SSM6J414TU                UF6_TOS                      ssm6j414tu          1
U13       SPX3819-3.3              VREG_SOT23-5              SOT23-5                      microbuilder        2

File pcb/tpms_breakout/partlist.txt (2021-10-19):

Partlist

Exported from tpms_breakout.sch at 10/19/21 1:53 PM

EAGLE Version 9.6.2 Copyright (c) 1988-2020 Autodesk, Inc.

Assembly variant: 

Part     Value              Device             Package      Library             Sheet

ACT                         LEDCHIP-LED0603    CHIP-LED0603 adafruit            1
CDH      53398-0610         53398-0610         53398-0610   con-molex-picoblade 1
ERR                         LEDCHIP-LED0603    CHIP-LED0603 adafruit            1
H1       MOUNT-PAD-ROUND2.8 MOUNT-PAD-ROUND2.8 2,8-PAD      holes               1
H2       MOUNT-PAD-ROUND2.8 MOUNT-PAD-ROUND2.8 2,8-PAD      holes               1
H3       MOUNT-PAD-ROUND2.8 MOUNT-PAD-ROUND2.8 2,8-PAD      holes               1
H4       MOUNT-PAD-ROUND2.8 MOUNT-PAD-ROUND2.8 2,8-PAD      holes               1
JP1                         HEADER-1X16ROUND   1X16_ROUND   microbuilder        2
JP2                         HEADER-1X12        1X12_ROUND   microbuilder        2
JP3                         HEADER-1X12        1X12_ROUND   microbuilder        2
JP4                         HEADER-1X12        1X12_ROUND   microbuilder        2
PS1      53398-0410         53398-0410         53398-0410   con-molex-picoblade 1
PS2      53398-0410         53398-0410         53398-0410   con-molex-picoblade 1
PS3      53398-0410         53398-0410         53398-0410   con-molex-picoblade 1
PS4      53398-0410         53398-0410         53398-0410   con-molex-picoblade 1
PS5      53398-0410         53398-0410         53398-0410   con-molex-picoblade 1
PWR                         LEDCHIP-LED0603    CHIP-LED0603 adafruit            1
R4       470                R-US_R0603         R0603        rcl                 1
R8       470                R-US_R0603         R0603        rcl                 1
R9       470                R-US_R0603         R0603        rcl                 1
R10      470                R-US_R0603         R0603        rcl                 1
RUN                         LEDCHIP-LED0603    CHIP-LED0603 adafruit            1
TC1      53398-0410         53398-0410         53398-0410   con-molex-picoblade 1
TC2      53398-0410         53398-0410         53398-0410   con-molex-picoblade 1
TC3      53398-0410         53398-0410         53398-0410   con-molex-picoblade 1

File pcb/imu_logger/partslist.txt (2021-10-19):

Partlist

Exported from imu_logger.sch at 10/19/21 1:54 PM

EAGLE Version 9.6.2 Copyright (c) 1988-2020 Autodesk, Inc.

Assembly variant: 

Part     Value              Device             Package                Library             Sheet

C1       0.1uF              C-EUC0603          C0603                  rcl                 1
C2       1uF                C-EUC0603          C0603                  rcl                 1
C3       1uF                C-EUC0603          C0603                  rcl                 1
C4       0.1uF              C-EUC0603          C0603                  rcl                 1
C5       0.1uF              C-EUC0603          C0603                  rcl                 2
C6       0.01uF             C-EUC0603          C0603                  rcl                 2
C7       0.1uF              C-EUC0603          C0603                  rcl                 2
C8       2.2uF              C-EUC0603          C0603                  rcl                 2
C15      0.1uF              C-EUC0603          C0603                  rcl                 2
C16      0.1uF              C-EUC0603          C0603                  rcl                 2
C17      0.1uF              C-EUC0603          C0603                  rcl                 2
C18      0.1uF              C-USC0603          C0603                  rcl                 3
C19      2.2uF              C-USC0603          C0603                  rcl                 3
C20      0.01uF             C-USC0603          C0603                  rcl                 3
J1       DM3CS-SF           DM3CS-SF           HRS_DM3CS-SF           DM3CS-SF            1
JP1                         HEADER-1X16ROUND   1X16_ROUND             microbuilder        1
JP3                         HEADER-1X12        1X12_ROUND             microbuilder        1
P1       53398-0310         53398-0310         53398-0310             con-molex-picoblade 1
R14      2.2k               R-US_R0603         R0603                  rcl                 2
R15      2.2k               R-US_R0603         R0603                  rcl                 2
U$1      H3LIS100DL         H3LIS100DL         XDCR_LIS3DHTR          LIS3DHTR            1
U1       MAX14591ETAT       MAX14591ETAT       SON50P200X200X80-8N    MAX14591ETAT        3
U2       LP2985IM5-1.8/NOPB LP2985IM5-1.8/NOPB MF05A                  gsynth              3
U3       MAX14591ETAT       MAX14591ETAT       SON50P200X200X80-8N    MAX14591ETAT        3
U4       MAX14591ETAT       MAX14591ETAT       SON50P200X200X80-8N    MAX14591ETAT        3
U5       ICM-20948          ICM-20948          QFN40P300X300X105-25N  ICM-20948           2
U6       ICM-20789          ICM-20789          PQFN50P400X400X146-24N ICM-20789           2

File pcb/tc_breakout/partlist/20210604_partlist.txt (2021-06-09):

Partlist

Exported from tc_breakout.sch at 6/4/21 11:25 AM

EAGLE Version 9.6.2 Copyright (c) 1988-2020 Autodesk, Inc.

Assembly variant: 

Part     Value              Device                    Package                              Library             Sheet

 C10      0.1uF              C-EUC0603                 C0603                                rcl                 1
 C11      0.1uF              C-EUC0603                 C0603                                rcl                 1
 C12      0.1uF              C-EUC0603                 C0603                                rcl                 1
 C13      0.1uF              C-EUC0603                 C0603                                rcl                 1
 C14      0.1uF              C-EUC0603                 C0603                                rcl                 1
 C15      0.1uF              C-EUC0603                 C0603                                rcl                 1
 C22      10µF               CAP_CERAMIC0805-NOOUTLINE 0805-NO                              microbuilder        2
 C23      0.1uF              C-EUC0603                 C0603                                rcl                 1
 C24      0.1uF              C-EUC0603                 C0603                                rcl                 1
 C25      0.1uF              C-EUC0603                 C0603                                rcl                 1
 C26      0.1uF              C-EUC0603                 C0603                                rcl                 1
 C27      0.1uF              C-EUC0603                 C0603                                rcl                 1
 C28      0.1uF              C-EUC0603                 C0603                                rcl                 1
C29      1uF                CAP_CERAMIC0603_NO        0603-NO                              microbuilder        2
C30      10µF               CAP_CERAMIC0805-NOOUTLINE 0805-NO                              microbuilder        2
H1       MOUNT-PAD-ROUND3.0 MOUNT-PAD-ROUND3.0        3,0-PAD                              holes               2
H2       MOUNT-PAD-ROUND3.0 MOUNT-PAD-ROUND3.0        3,0-PAD                              holes               2
H3       MOUNT-PAD-ROUND3.0 MOUNT-PAD-ROUND3.0        3,0-PAD                              holes               2
H4       MOUNT-PAD-ROUND3.0 MOUNT-PAD-ROUND3.0        3,0-PAD                              holes               2
J1       282836-2           282836-2                  CONN_282836-2                        282836-2            1
J2       282836-2           282836-2                  CONN_282836-2                        282836-2            1
J3       282836-2           282836-2                  CONN_282836-2                        282836-2            1
J4       282836-2           282836-2                  CONN_282836-2                        282836-2            1
J5       282836-2           282836-2                  CONN_282836-2                        282836-2            1
J12      282836-2           282836-2                  CONN_282836-2                        282836-2            1
P2       53398-0510         53398-0510                53398-0510                           con-molex-picoblade 2
P3       53398-0410         53398-0410                53398-0410                           con-molex-picoblade 2
  R13      100                R-EU_R0603                R0603                                rcl                 1
  R14      100                R-EU_R0603                R0603                                rcl                 1
  R15      100                R-EU_R0603                R0603                                rcl                 1
  R16      100                R-EU_R0603                R0603                                rcl                 1
 R17      100                R-EU_R0603                R0603                                rcl                 1
 R18      100                R-EU_R0603                R0603                                rcl                 1
 R19      100                R-EU_R0603                R0603                                rcl                 1
 R20      100                R-EU_R0603                R0603                                rcl                 1
 R21      100                R-EU_R0603                R0603                                rcl                 1
 R22      100                R-EU_R0603                R0603                                rcl                 1
 R23      100                R-EU_R0603                R0603                                rcl                 1
 R24      100                R-EU_R0603                R0603                                rcl                 1
  R25      10k                R-EU_R0603                R0603                                rcl                 1
  R26      13k                R-EU_R0603                R0603                                rcl                 1
  R31      10k                R-EU_R0603                R0603                                rcl                 1
  R32      7.5k               R-EU_R0603                R0603                                rcl                 1
  R35      10k                R-EU_R0603                R0603                                rcl                 1
  R36      4.3k               R-EU_R0603                R0603                                rcl                 1
  R39      10k                R-EU_R0603                R0603                                rcl                 1
  R40      2.2k               R-EU_R0603                R0603                                rcl                 1
  R45      100k               RESISTOR_0603_NOOUT       0603-NO                              microbuilder        2
U4       MCP96L00T-E/MX     MCP96L00T-E/MX            QFN65P500X500X100-21N_MCP96L00T-E/MX MCP96L00T-E_MX      1
U5       MCP96L00T-E/MX     MCP96L00T-E/MX            QFN65P500X500X100-21N_MCP96L00T-E/MX MCP96L00T-E_MX      1
U7       MCP96L00T-E/MX     MCP96L00T-E/MX            QFN65P500X500X100-21N_MCP96L00T-E/MX MCP96L00T-E_MX      1
U8       MCP96L00T-E/MX     MCP96L00T-E/MX            QFN65P500X500X100-21N_MCP96L00T-E/MX MCP96L00T-E_MX      1
U9       MCP96L00T-E/MX     MCP96L00T-E/MX            QFN65P500X500X100-21N_MCP96L00T-E/MX MCP96L00T-E_MX      1
U10      MCP96L00T-E/MX     MCP96L00T-E/MX            QFN65P500X500X100-21N_MCP96L00T-E/MX MCP96L00T-E_MX      1
U13      SPX3819-3.3        VREG_SOT23-5              SOT23-5                              microbuilder        2

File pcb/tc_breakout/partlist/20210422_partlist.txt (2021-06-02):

Partlist

Exported from tc_breakout.brd at 4/22/21 8:15 AM

EAGLE Version 9.6.2 Copyright (c) 1988-2020 Autodesk, Inc.

Assembly variant: 

Part     Value              Package                              Library             Position (mil)        Orientation

C10      0.1uF              C0603                                rcl                 (650 400)             R0
C11      0.1uF              C0603                                rcl                 (1100 400)            R0
C12      0.1uF              C0603                                rcl                 (650 950)             R180
C13      0.1uF              C0603                                rcl                 (1550 400)            R0
C14      0.1uF              C0603                                rcl                 (1100 950)            R180
C15      0.1uF              C0603                                rcl                 (1550 950)            R180
C22      10µF               0805-NO                              microbuilder        (1580 830)            R270
C23      0.1uF              C0603                                rcl                 (1775 300)            R0
C24      0.1uF              C0603                                rcl                 (1325 1050)           R180
C25      0.1uF              C0603                                rcl                 (875 305)             R0
C26      0.1uF              C0603                                rcl                 (1325 300)            R0
C27      0.1uF              C0603                                rcl                 (875 1050)            R180
C28      0.1uF              C0603                                rcl                 (420 1050)            R180
C29      1uF                0603-NO                              microbuilder        (1910 840)            R270
C30      10µF               0805-NO                              microbuilder        (1825 835)            R270
H1       MOUNT-PAD-ROUND3.0 3,0-PAD                              holes               (200 200)             R0
H2       MOUNT-PAD-ROUND3.0 3,0-PAD                              holes               (2000 200)            R0
H3       MOUNT-PAD-ROUND3.0 3,0-PAD                              holes               (200 1150)            R0
H4       MOUNT-PAD-ROUND3.0 3,0-PAD                              holes               (2000 1150)           R0
J1       282836-2           CONN_282836-2                        282836-2            (650 200)             MR180
J2       282836-2           CONN_282836-2                        282836-2            (1100 200)            MR180
J3       282836-2           CONN_282836-2                        282836-2            (1550 200)            MR180
J4       282836-2           CONN_282836-2                        282836-2            (650 1150)            MR0
J5       282836-2           CONN_282836-2                        282836-2            (1100 1150)           MR0
J12      282836-2           CONN_282836-2                        282836-2            (1550 1150)           MR0
P2       53398-0510         53398-0510                           con-molex-picoblade (2000 700)            R270
R13      100                R0603                                rcl                 (550 300)             R0
R14      100                R0603                                rcl                 (750 300)             R180
R15      100                R0603                                rcl                 (1000 300)            R0
R16      100                R0603                                rcl                 (1200 300)            R180
R17      100                R0603                                rcl                 (1450 300)            R0
R18      100                R0603                                rcl                 (1650 300)            R180
R19      100                R0603                                rcl                 (550 1050)            R0
R20      100                R0603                                rcl                 (750 1050)            R180
R21      100                R0603                                rcl                 (1000 1050)           R0
R22      100                R0603                                rcl                 (1200 1050)           R180
R23      100                R0603                                rcl                 (1650 1050)           R180
R24      100                R0603                                rcl                 (1450 1050)           R0
R25      10k                R0603                                rcl                 (1465 565)            R90
R26      7.87k              R0603                                rcl                 (1545 565)            R90
R31      10k                R0603                                rcl                 (1920 500)            R90
R32      4.3k               R0603                                rcl                 (1940 400)            R0
R35      10k                R0603                                rcl                 (1015 565)            R90
R36      4.3k               R0603                                rcl                 (1095 565)            R90
R39      10k                R0603                                rcl                 (655 785)             R270
R40      2.2k               R0603                                rcl                 (735 785)             R270
R45      100k               0603-NO                              microbuilder        (1695 745)            R180
U4       MCP96L00T-E/MX     QFN65P500X500X100-21N_MCP96L00T-E/MX MCP96L00T-E_MX      (850 500)             R0
U5       MCP96L00T-E/MX     QFN65P500X500X100-21N_MCP96L00T-E/MX MCP96L00T-E_MX      (1300 500)            R0
U7       MCP96L00T-E/MX     QFN65P500X500X100-21N_MCP96L00T-E/MX MCP96L00T-E_MX      (450 850)             R180
U8       MCP96L00T-E/MX     QFN65P500X500X100-21N_MCP96L00T-E/MX MCP96L00T-E_MX      (1350 850)            R180
U9       MCP96L00T-E/MX     QFN65P500X500X100-21N_MCP96L00T-E/MX MCP96L00T-E_MX      (1750 500)            R0
U10      MCP96L00T-E/MX     QFN65P500X500X100-21N_MCP96L00T-E/MX MCP96L00T-E_MX      (900 850)             R180
U13      SPX3819-3.3        SOT23-5                              microbuilder        (1700 845)            R270

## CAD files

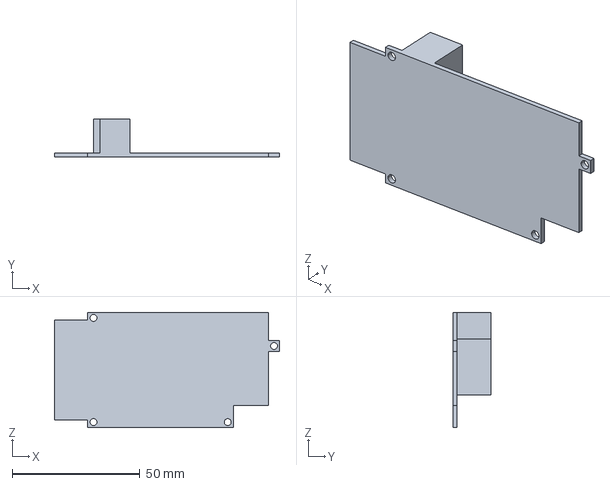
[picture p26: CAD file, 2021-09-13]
pcb/board_models/iridium_modem.stp
87.9 x 14.8 x 45.0 mm

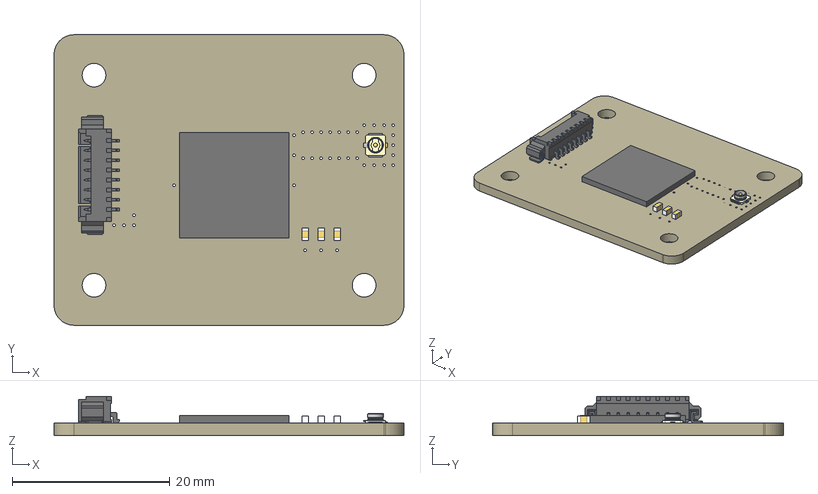
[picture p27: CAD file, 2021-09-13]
pcb/board_models/gps_board v3.step
44.4 x 36.9 x 4.97 mm
3,0-PAD x 4
RXM-GPS-FM
C0603 x 3
CONN_R-SMT-1(10)
Board

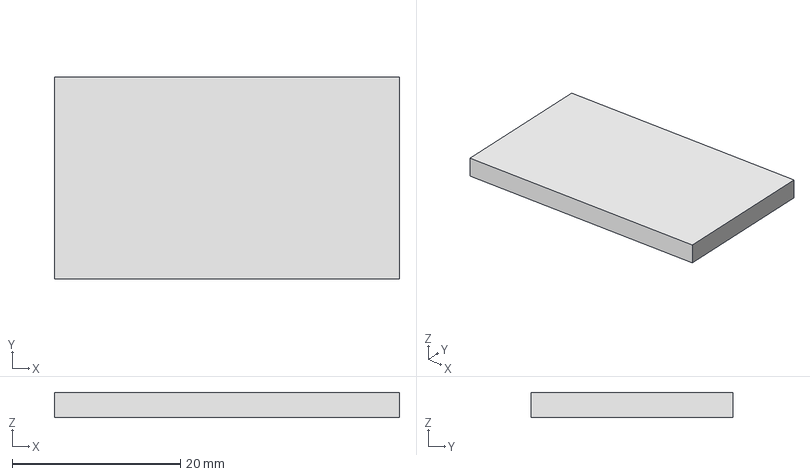
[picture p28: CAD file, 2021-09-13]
pcb/board_models/SD adapter.stp
41.0 x 24.0 x 3.00 mm

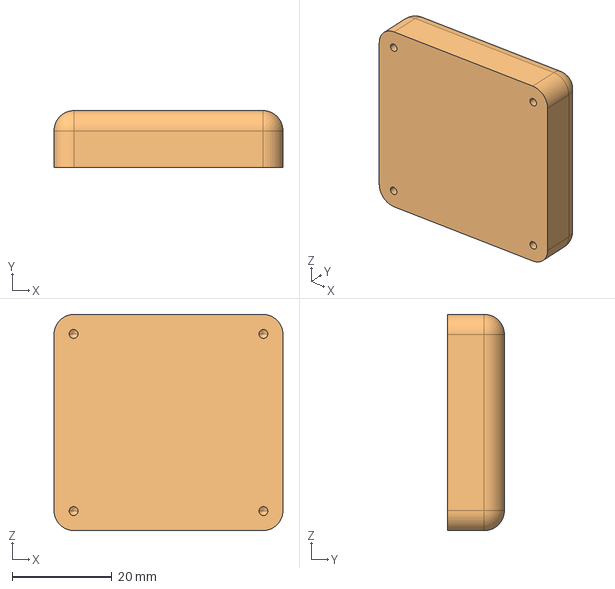
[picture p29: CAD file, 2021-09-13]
pcb/board_models/iridium_antenna.stp
46.0 x 11.4 x 43.4 mm

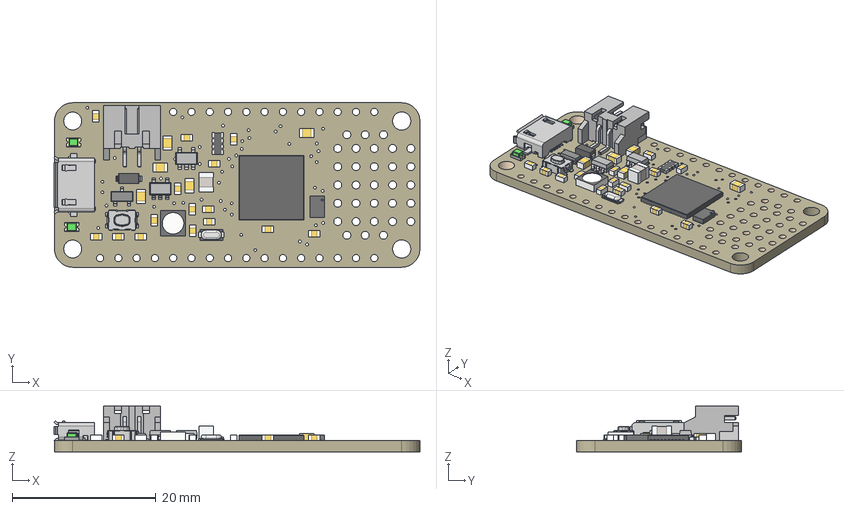
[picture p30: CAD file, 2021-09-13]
pcb/board_models/Processor 2.step
50.9 x 22.9 x 6.37 mm
Board
10uF x 5
1uF x 15
ORANGE x 2
KMR2
microUSB
MCP73831T-2ACI/OT x 2
JSTPH
WS2812B3535
2MB Flash
MBR120
DMG341
100K
ATSAMD51J
10uH

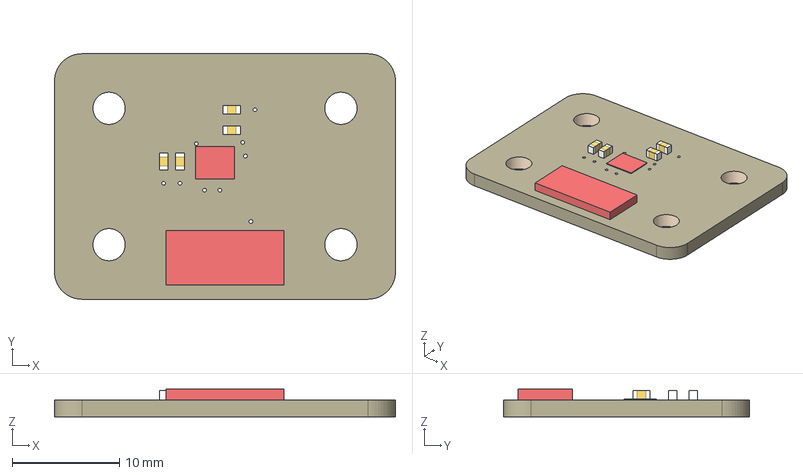
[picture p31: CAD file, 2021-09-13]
pcb/board_models/lis100 v1.step
31.8 x 22.9 x 2.57 mm
Board
H3LIS100DL
MOUNT-PAD-ROUND3.0 x 4
1uF x 4

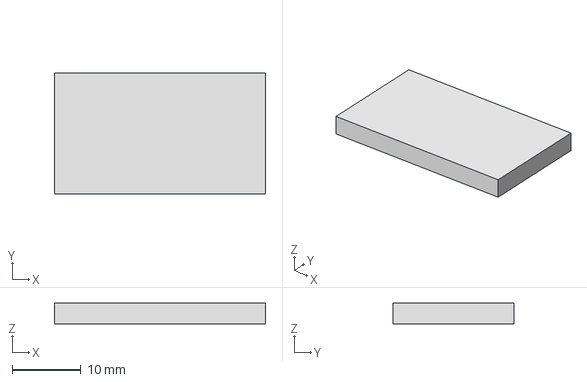
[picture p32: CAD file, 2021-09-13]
pcb/board_models/i2c multiplexor.stp
30.6 x 17.6 x 3.00 mm

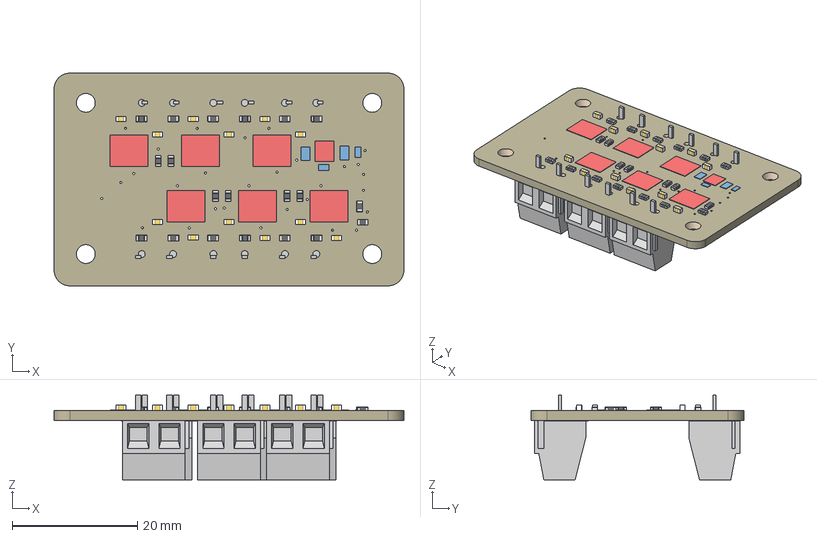
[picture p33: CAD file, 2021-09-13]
pcb/board_models/tc_breakout v2.step
55.9 x 34.0 x 13.5 mm
Board
0.1uF x 12
10µF x 2
100k x 2
2.2k x 20
MCP96L00T-E/MX x 6
SPX3819-3.3
MOUNT-PAD-ROUND3.0 x 4

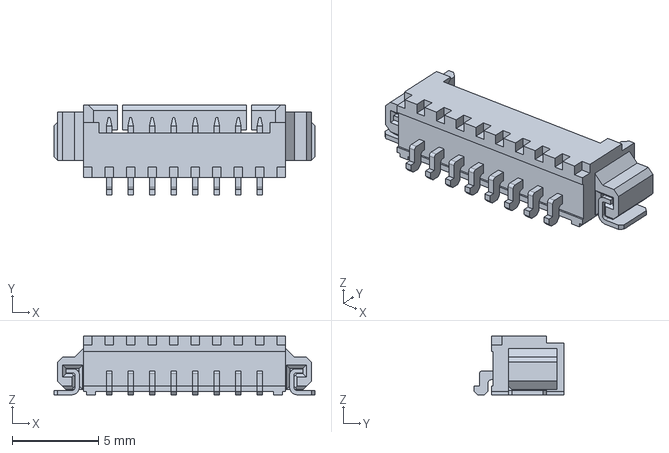
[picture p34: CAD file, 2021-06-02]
pcb/component_cad/532610871.stp
15.2 x 5.20 x 3.40 mm

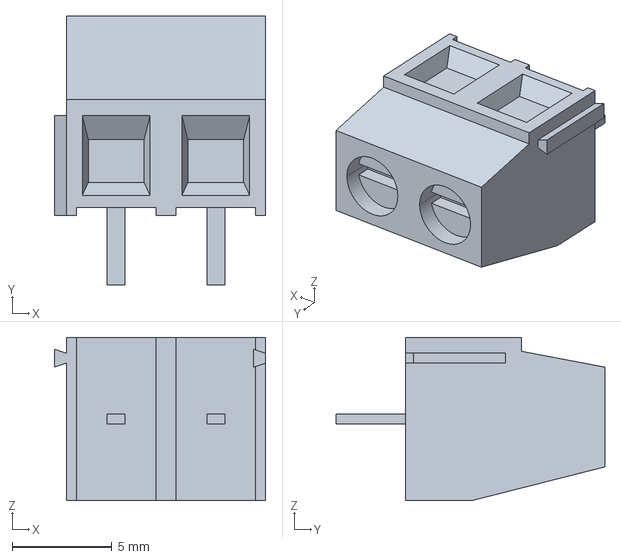
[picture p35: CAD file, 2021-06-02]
pcb/component_cad/282836-2.stp
10.6 x 13.5 x 8.20 mm

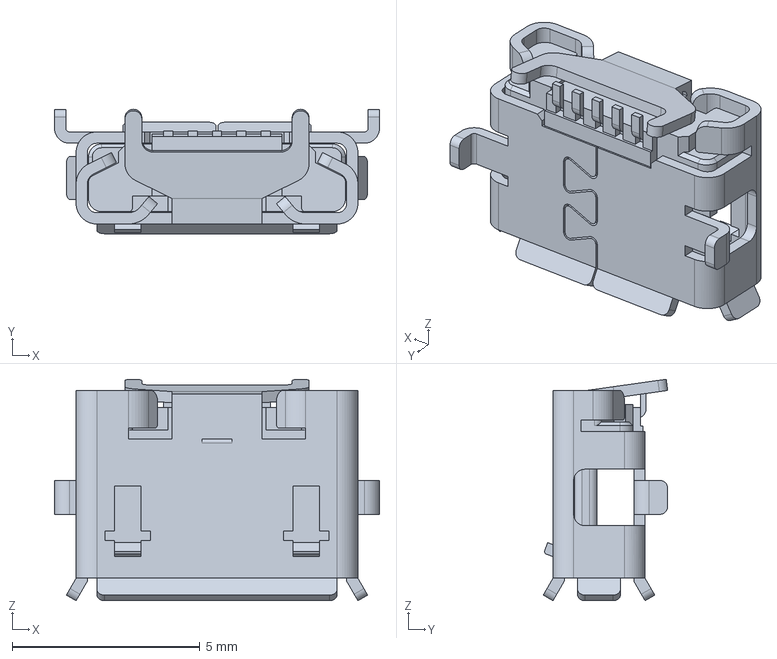
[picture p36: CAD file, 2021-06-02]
pcb/component_cad/475890001.stp
8.65 x 3.31 x 5.89 mm

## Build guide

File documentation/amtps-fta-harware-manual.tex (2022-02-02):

\documentclass{article}
\usepackage[utf8]{inputenc}

\title{AMPTS FTA Avionics Design}
\author{Matt Ruffner}
\date{\today\\v1.3}

\usepackage{url}
\usepackage{array}
\usepackage{float}
\usepackage{natbib}
\usepackage{titlesec}
\usepackage{capt-of}
\usepackage{graphicx}
\usepackage{listings}
\usepackage{fullpage}
\usepackage{hyperref}
\usepackage{geometry}
\usepackage{pdflscape}
\hypersetup{
    colorlinks=true,
    linkcolor=blue,
    filecolor=magenta,      
    urlcolor=cyan,
}

\newcolumntype{L}{>{\centering\arraybackslash}m{2cm}}

\newcommand{\ddrev}{E}

\begin{document}

\maketitle
\begin{center}
	%\includegraphics[width=4cm]{images/ukcoe.png}
	%\includegraphics[width=4cm]{images/upaero-logo.png}
	%\includegraphics[width=2cm]{images/nasa-logo.png}
	%\includegraphics[width=4cm]{images/ornl.pdf}	
\end{center}
\tableofcontents \newpage
\listoffigures 
\listoftables \newpage

%%%%%%%%%%%%%%%%%%%%%%%%%%%%%%%%%%%%%%%%%%%%%%%%%%%%%%%%%%%%%%%%%%%%%%%%%%%%%%%%%%%%%%%%%
%%%%%%%%%%%%%%%%%%%%%%%%%%%%%%%%%%%%%%%%%%%%%%%%%%%%%%%%%%%%%%%%%%%%%%%%%%%%%%%%%%%%%%%%%
%%%%%%%%%%%%%%%%%%%%%%%%%%%%%%%%%%%%%%%%%%%%%%%%%%%%%%%%%%%%%%%%%%%%%%%%%%%%%%%%%%%%%%%%%
%%%%%%%%%%%%%%%%%%%%%%%%%%%%%%%%%%%%%%%%%%%%%%%%%%%%%%%%%%%%%%%%%%%%%%%%%%%%%%%%%%%%%%%%%
\section{Introduction}
This document outlines the initial design of electrical hardware that will support the flight test article (FTA) being developed for the NASA Flight Opportunities \textit{Additive Manufacturing of Thermal Protection Systems} (AMTPS) project. This project is a collaboration between several NASA facilities including JSC and Langley as well as other research institutions namely the University of Kentucky and Oak Ridge National Laboratories. Figure \ref{fig:capsule-overview} shows a general overview of the various components that are  expected to be a part of the flight test article (referred to as 'the capsule') based on current requirements.

Capsule hardware must be capable of robust data acquisition in order to characterize the thermal, pressure, and overall heating environment of supersonic reentry. In addition to collecting multiple data channels, the hardware must be capable of transmitting its location as it touches back down to Earth. The multichannel data acquisition system must also save flight data for further analysis after it touches back down. Timing the deployment of a parachute before touchdown is also a requirement of the hardware in order to lessen the force of impact.

This document is organized as follows: Section \ref{sec:requirements} discusses needed capabilities in the form of technical and logistical requirements set by the NASA project design document (rev. \ddrev ). Section \ref{sec:ss-design} displays the electronic hardware designs for subsystems of the capsule. This includes data acquisition, logging, and vehicle-to-ground communication for recovery operations. Secion \ref{sec:software} discusses software functionality and test plans, while Section \ref{sec:testplans} discusses testing for the rest of the hardware and capsule as a whole. Section \ref{sec:logistics} contains in-work project considerations as well as an approximate schedule. Appendix \ref{appa} contains schematics for PCBs that have been prototyped.  

\begin{figure}[h!]
	\centering
	
	\caption{Capsule component overview, showing the various functional blocks.}
	\label{fig:capsule-overview}
\end{figure}

%%%%%%%%%%%%%%%%%%%%%%%%%%%%%%%%%%%%%%%%%%%%%%%%%%%%%%%%%%%%%%%%%%%%%%%%%%%%%
%%%%%%%%%%%%%%%%%%%%%%%%%%%%%%%%%%%%%%%%%%%%%%%%%%%%%%%%%%%%%%%%%%%%%%%%%%%%%
%%%%%%%%%%%%%%%%%%%%%%%%%%%%%%%%  APPENDIX
%%%%%%%%%%%%%%%%%%%%%%%%%%%%%%%%%%%%%%%%%%%%%%%%%%%%%%%%%%%%%%%%%%%%%%%%%%%%%
%%%%%%%%%%%%%%%%%%%%%%%%%%%%%%%%%%%%%%%%%%%%%%%%%%%%%%%%%%%%%%%%%%%%%%%%%%%%%
\section{Requirements}
\label{sec:requirements}
Based off of the most recent revision (\ddrev) of the flight test requirements document.

\begin{enumerate}
\item Instrumentation and telemetry
  \begin{enumerate}
	  \item Shall support betwen 8 and 20 thermocouples of varying type
	  \item Shall support up to 6 absolute pressure sensors
	  \item Shall support at least 1 intertial measurement unit (IMU)
	  \item Should support 1 heat flux sensor
	  \item Shall contain a GPS for recovery operations, accurate to with 100m
	  \item Capsule shall contain an internal barometric pressure sensor 
	  \item Telemetry data shall be collected at a minumum of 10Hz
	  \item Telemetry data shall be stored to onboard nonvolatile memory that will survive landing
	  \item Location telemetry shall be transmitted through a vehicle-to-ground system (e.g. Iridium satellite, Xbee)
	  \item Recovery location should be broadcasted at least once every 5 minutes post-flight
  \end{enumerate}
\item Activation and flight sequencing
  \begin{enumerate}
	  \item Shall be powered through the duration of the flight
	  \item Shall support continuous operation between -20 deg C and 80 deg C
	  \item Shall support pre-launch activation on the ground; should support low power mode prior to deployment
	  \item Shall detect and/or sense when deployment has occurred via interfacing with the launch vehicle
	  \item Shall transmit in-flight telemetry with position information
	  \item In-flight telemetry should contain capsule velocity 
	  \item Shall trigger parachute deployment at a specified time
  \end{enumerate}
\item Physical properties
\item Avionics hardware shall weigh under or around 0.5kg
\item Shall cost under \$3,000
\end{enumerate}

%%%%%%%%%%%%%%%%%%%%%%%%%%%%%%%%%%%%%%%%%%%%%%%%%%%%%%%%%%%%%%%%%%%%%%%%%%%%%
%%%%%%%%%%%%%%%%%%%%%%%%%%%%%%%%%%%%%%%%%%%%%%%%%%%%%%%%%%%%%%%%%%%%%%%%%%%%%
%%%%%%%%%%%%%%%%%%%%%%%%%%%%%%%%  DESIGN
%%%%%%%%%%%%%%%%%%%%%%%%%%%%%%%%%%%%%%%%%%%%%%%%%%%%%%%%%%%%%%%%%%%%%%%%%%%%%
%%%%%%%%%%%%%%%%%%%%%%%%%%%%%%%%%%%%%%%%%%%%%%%%%%%%%%%%%%%%%%%%%%%%%%%%%%%%%
\section{Subsystem Design}
\label{sec:ss-design}

\subsection{Main command and data handling}

Using off the shelf processors for convenience, and also to avoid bottlenecks in prototyping due to unpredictable chip shortages. Currently, two development boards from Adafruit are being used to prototyping and are listed below in Table \ref{tab:processors}\footnote{TPM: Temperature and Pressure Measurement}\footnote{CDH: Command and Data Handling}. The diagram in Figure \ref{fig:main-overview} provides a general overview of the organization of electronic hardware within the capsule. 

\begin{figure}[h!]
	\centering
	
	\caption{Main functional components of the capsule and the communication buses between them.}
	\label{fig:main-overview}
\end{figure}

\begin{table}[h!]	
	\caption{List of processors used and their capabilities.}
	\begin{tabular}{l | c c m{5cm}}
		Part & Description & Role & Product Link \\
		\hline
		(2) Feather M0 Basic Proto & Cortex-M0 @ 48 MHz & TPM and IMU processor & \url{https://www.adafruit.com/product/2772}\\
		Feather M4 Express & Cortex-M4 @ 120Mhz & CDH Processor & \url{https://www.adafruit.com/product/3857} 
	\end{tabular}
	\label{tab:processors}
\end{table}

Shown in Fig. \ref{fig:cdh-prototype} is the assembled prototype of the main board.
\begin{figure}[h!]
	\centering
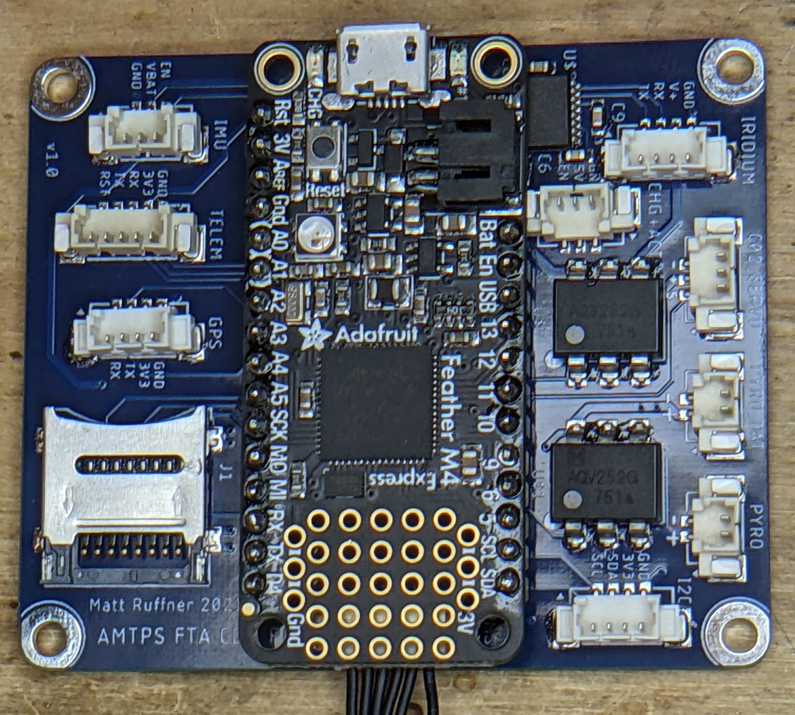
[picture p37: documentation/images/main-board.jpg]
	
	\caption{Assembled CDH main board.}
	\label{fig:cdh-prototype}
\end{figure}

%%%%%%%%%%%%%%%%%%%%%%%%%%%%%%%%%%%%%%%%%%%%%%%%%%%%%%%%%%%%%%%%%%%%%%%%%%%%%
%%%%%%%%%%%%%%%%%%%%%%%%%%%%%%%%%%%%%%%%%%%%%%%%%%%%%%%%%%%%%%%%%%%%%%%%%%%%%
\subsection{Temperature and Pressure Measurement}
The temperature and pressure measurement (TPM) Subsystem (TPMS) supports collection of several datapoints needed for recreating the heating environment of reentry. The diagram in Figure \ref{fig:tpms-overview} shows an overview of the temperature and pressure monitoring subsystem. Images of the TC to digital breakout and TPMS interface boards are shown in Figs. \ref{fig:tpms-proto} and \ref{fig:tc-board-bottom}.

In order to support the large number of TCs required in the capsule, a breakout board supporting 6 of the MCP9600T-E/MX series TC to digital converter was designed. This TC converter chip was selected due to its support for a wide variety of TC types (K, J, T, N, S, E, B and R)\footnote{\url{https://www.digikey.com/en/products/detail/microchip-technology/MCP96L00T-E-MX/9606988}}, as well as its chainable I$^2$C interface, allowing more sensing elements to connected with less wiring (similar SPI based conversion chips have a chip select line per chip that would restrict the number of pins available for other capsule functionality).

For pressure meausrement, Honeywell sensing solutions temperature compensated absolute digital pressure sensors were selected and are shown in Table \ref{tab:pressure-sensors}. These single port absolute pressure sensors are available with a variety of sensitivities, allowing a different sensor to be exchanged later on in the design process if it is determined that the current predicted pressure environment is no longer accurate.

\begin{table}[h!]
	\caption{List of pressure sensors and their capabilities}
	\begin{tabular}{c | c m{9cm}}
		Part & Measurement Range & Product Link \\
		\hline
		SSCSRNN015PA3A3 & 0-103.42 kPa & \url{https://www.digikey.com/en/products/detail/honeywell-sensing-and-productivity-solutions/SSCSRNN015PA3A3/2416212}\\
		SSCSRNN1-6BA7A3 & 0-160 kPa & \url{https://www.digikey.com/en/products/detail/honeywell-sensing-and-productivity-solutions/SSCSRNN1-6BA7A3/2416214} 
	\end{tabular}
\label{tab:pressure-sensors}
\end{table}

\begin{figure}[H]
	\centering
	
	\caption{Functional decomposition of the TPMS.}
	\label{fig:tpms-overview}
\end{figure}

Shown in Fig. \ref{fig:tpms-proto} is the assembled prototype of the TPMS breakout board that interfaces to the CDH board and the TC breakouts.
\begin{figure}[H]
	\centering
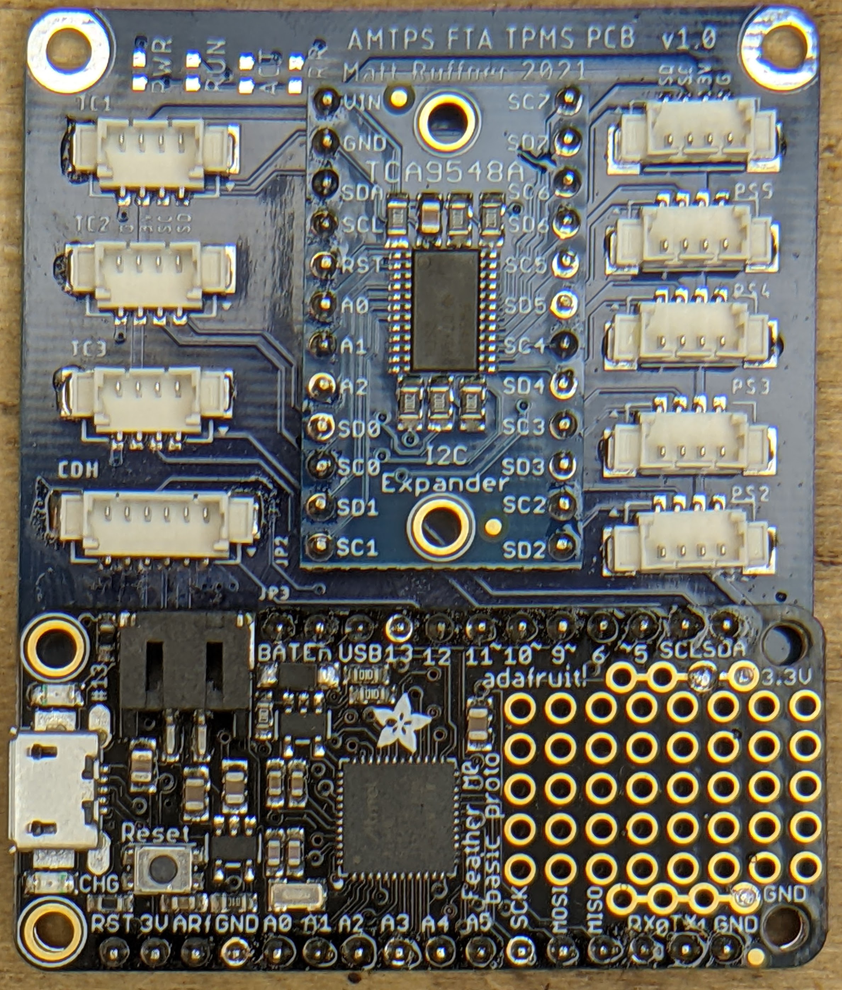
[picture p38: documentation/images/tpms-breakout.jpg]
	
	\caption{Assembled TPMS breakout board.}
	\label{fig:tpms-proto}
\end{figure}

Shown in Fig. \ref{fig:tc-board-bottom} is the TC to digital breakout board, two of which will be used for a total of 12 TC channels.
\begin{figure}[H]
	\centering
	
	\caption{Bottom of V1 Evaluation board for MCP9600 TC to digital converter}
	\label{fig:tc-board-bottom}
\end{figure}

\subsection{Inertial Measurement}
A breakout board for the H3LIS100DL~\footnote{\url{https://www.digikey.com/en/products/detail/stmicroelectronics/H3LIS100DL/7313278}} +/- 100g accelerometer has been designed to help in the evaluation of this IC as an effective way to measure acceleration loads on the capsule. In addition to a +/- 100g 3-axis accelerometer, a lower dynamic range 9 axis acceleromter+gyroscope chip will also be included (ICM-20949).

\begin{figure}[H]
	\centering
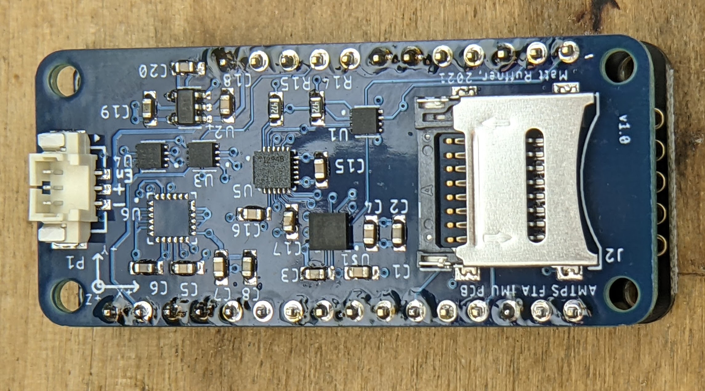
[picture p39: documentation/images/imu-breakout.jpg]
	
	\caption{Assembled IMU logger with ICM-20948 9-axis IMU and H3LIS100 3-axis 100g accelerometer.}
	\label{fig:imu-breakout}
\end{figure}

%%%%%%%%%%%%%%%%%%%%%%%%%%%%%%%%%%%%%%%%%%%%%%%%%%%%%%%%%%%%%%%%%%%%%%%%%%%%%
%%%%%%%%%%%%%%%%%%%%%%%%%%%%%%%%%%%%%%%%%%%%%%%%%%%%%%%%%%%%%%%%%%%%%%%%%%%%%
\subsection{Telemetry}

Iridium modem to send GPS coordinates for recovery operations. University of Kentucky has purchased an Iridium modem for use in this project and has an account providing message credits. Additional vehicle-to-ground telemetry would be reassuring as the Iridium network can be unreliable for short periods of time. It is unclear whether this would be achievable with a COTS radio link (such as XBee or LORA) that would not require FCC certification. This requires coordination with launch site for tracking with a directional antenna and other hardware setup. The appeal of the Iridium is we get an email with the GPS coordinates of the capsule and we can tell the recovery crew the location of the capsule from anywhere. 

%%%%%%%%%%%%%%%%%%%%%%%%%%%%%%%%%%%%%%%%%%%%%%%%%%%%%%%%%%%%%%%%%%%%%%%%%%%%%
%%%%%%%%%%%%%%%%%%%%%%%%%%%%%%%%%%%%%%%%%%%%%%%%%%%%%%%%%%%%%%%%%%%%%%%%%%%%%
\subsection{Parachute Deployment}
There will be a main and drogue chute. Initial drogue chute deployment will be propelled by a CO$_2$ cartridge puncture system which has a servo actuated trigger. Servo control signal pins are allotted on the main CDH processor and configured in software to trigger when necessary. Release of the drogue chute will be facilitated by pyrotechnic cutters which will be triggered sometime after drogue chute deployment.

The software to trigger the drogue based on barometric pressure is functional. There is a necessary calibration step where, once at white sands, the pressure at ground level would be programmed into the capsule via the wireless debug interface.

Current plans to decide correct deployment time are to use capsule internal barometric pressure, possibly in combination with one of the external pressure sensors.

%%%%%%%%%%%%%%%%%%%%%%%%%%%%%%%%%%%%%%%%%%%%%%%%%%%%%%%%%%%%%%%%%%%%%%%%%%%%%
%%%%%%%%%%%%%%%%%%%%%%%%%%%%%%%%%%%%%%%%%%%%%%%%%%%%%%%%%%%%%%%%%%%%%%%%%%%%%
\subsection{Storage}
On board non-volatile storage is required to log in-flight telemetry data for post processing. Due to the high vibrational loads expected during launch, an SD card might be unreliable (spring loaded contacts could separate from card). The limited availability of solid state flash has made this option infeasible. Instead, files can be retrieved from the IMU and main CDH board via serial connection to the computer. This way, the SD card can be permanently affixed to the board, and access to files can be achieved by connecting a cable to the avionics after recovery.

\subsection{Javad GPS}
Currently we are testing with a GPS that has COCOM limits in place. A Javad GPS module is being acquired which will have these limits removed and be able to provide GPS tracking data at high altitudes and velocities. The interface to the Javad card is the same as that of the testing GPS (power supply and two serial UART interface). For this reason, work to integrate this newer Javad card is expected to be minimal since mounting positions for it have already been designed into the capsule CAD.

%%%%%%%%%%%%%%%%%%%%%%%%%%%%%%%%%%%%%%%%%%%%%%%%%%%%%%%%%%%%%%%%%%%%%%%%%%%%%
%%%%%%%%%%%%%%%%%%%%%%%%%%%%%%%%%%%%%%%%%%%%%%%%%%%%%%%%%%%%%%%%%%%%%%%%%%%%%
\subsection{Power}
To power the capsule avionics, a lithium polymer battery will be used. Since the flight will be very short (~10 minutes), a single 3000mAh LiPo cell is estimated to be sufficient. There is room to adjust this as the current consumption tests progress. A battery protection IC will be used for added safety from shorts and battery over-depletion.

%%%%%%%%%%%%%%%%%%%%%%%%%%%%%%%%%%%%%%%%%%%%%%%%%%%%%%%%%%%%%%%%%%%%%%%%%%%%%
%%%%%%%%%%%%%%%%%%%%%%%%%%%%%%%%%%%%%%%%%%%%%%%%%%%%%%%%%%%%%%%%%%%%%%%%%%%%%
\subsection{Durability}
Syntactic foam may be used. Consisting of glass microballoons with epoxy resin, it can encase electronics to protect from very high acceleration loads during ascent. Currently working with NASA JSC to get glass microballoons to UK for testing. 

%%%%%%%%%%%%%%%%%%%%%%%%%%%%%%%%%%%%%%%%%%%%%%%%%%%%%%%%%%%%%%%%%%%%%%%%%%%%%
%%%%%%%%%%%%%%%%%%%%%%%%%%%%%%%%%%%%%%%%%%%%%%%%%%%%%%%%%%%%%%%%%%%%%%%%%%%%%
\section{Software}
\label{sec:software}

Capsule operation sequence is planned as follows:

\subsection{Functionality}

\begin{enumerate}
	\item Low power state prior to launch (activation pins with nosecone)
	\item Activate main operation loop upon separation from launch vehicle
	\item Begin logging all telemetry to internal storage and periodically transmitting Iridium packets with position and velocity information for recovery operations
	\item At a specified capsule internal barometric pressure, trigger the CO$_2$ release servo to release the drogue and main parachute.
\end{enumerate}

Currently, verified functionalities include logging of accelerometer, pressure, thermocouple, and GPS data to internal storage (GPS has been verified with a testing GPS unit which uses a similar wiring connection and output data format).

The software to test sending of Iridium modem packets is 90\% done and wont be able to be fully tested until the Javad GPS unit is integrated, since the Iridium packets are intended to have GPS coordinates and capsule velocity. IMU logging has also been verified, with both the +/-100g 3 axis sensor and +/-16g and +/-2000 deg/s gyroscope reading back good data from the recovery serial interface.

A separate document on software design is probably in order...

\subsection{Versioning}

Software for the capsule is under version control at \url{http://github.com/krups/amtps-fta-software}. Hardware design files and the source to this document are under version control at \url{http://github.com/krups/amtps-fta-hardware}. These are a private repository; if anyone would like access, please send an email to matthew.ruffner@uky.edu with their Github username and they will be considered for access.

Additionally, there will be checks in place to make sure the correct, flight-ready version of the code gets programmed onto the CDH, TMPS and IMU processor boards.

\subsection{Testing}
As the prototype build progresses and the software matures, functionality testing will be preformed to ensure all sensors are being logged as needed and that critical software triggers, such as using the barometer for parachute deployment, are functional.

Other tests planned include software data acquisition tests to verify IMU, high g accelerometer and TC measurements are consistently acquired and logged.

Thermocouple polarity and numbering will be verified by channel by heating to a fixed temperature with a known TC type and checking against logged measurement.

Pressure sensor configuration will be tested by varying the pressure on each pressure sensor and verifying the logged pressure reading corresponds to the changed sensor.

See Appendix \ref{appendix-testing} for a test matrix.

%%%%%%%%%%%%%%%%%%%%%%%%%%%%%%%%%%%%%%%%%%%%%%%%%%%%%%%%%%%%%%%%%%%%%%%%%%%%%
%%%%%%%%%%%%%%%%%%%%%%%%%%%%%%%%%%%%%%%%%%%%%%%%%%%%%%%%%%%%%%%%%%%%%%%%%%%%%
\section{Testing Plans}
\label{sec:testplans}

Test hardware has been assembled and is currently being used for software development. CAD models of capsule avionics have been integrated into the capsule mechanical CAD (with the exception of wiring) to verify physical fit. A mounting plate for all of the PCBs is under design and construction.

\subsection{Recovery}
Using a truck going at speed, a parachute test is planned, which will verify that the CO$_2$ cartridge release is functional and that the pyro charges are capable of releasing the drogue chute when needed. The results from this initial test will be used to calibrate the parachute ejecting routing timing to ensure drogue deployment at proper altitude and that the drogue is cut away after the correct amount of time.

The wireless interface to the capsule will be used in combination with a small groundstation to control the capsule and trigger the cartridge release (simulating a barometric pressure threshold crossing).

\subsection{Battery Life}
Battery life tests will make sure current draw with no circuits active is zero, and also verify the functionality of the activation switches in starting the system up. Additionally, current consumption when operating a standard mission (GPS on, Iridium transmitting, all sensors recording) will be measured in order to get an idea of how long the capsule will stay powered on after separation. 

%%%%%%%%%%%%%%%%%%%%%%%%%%%%%%%%%%%%%%%%%%%%%%%%%%%%%%%%%%%%%%%%%%%%%%%%%%%%%
%%%%%%%%%%%%%%%%%%%%%%%%%%%%%%%%%%%%%%%%%%%%%%%%%%%%%%%%%%%%%%%%%%%%%%%%%%%%%
\section{Project Logistics}
\label{sec:logistics}

\subsection{Cost}
According the the most recent revision of the project outline, NASA has alotted \$3,000 towards the avionics design. Currently the University of Kentucky has not used any of these funds in the prototyping of capsule hardware.

\subsection{Schedule}
Figure \ref{fig:schedule} shows an approximate schedule for assembly and evaluation of test hardware moving into 2022, past the PDR in February. Please see Appendix \ref{app-schedule} for the Gantt chart.

The following list provides a system level breakdown of the items in the Gannt chart

%%%%%%%%%%%%%%%%%%%%%%%%%%%%%%%%%%%%%%%%%%%%%%%%%%%%%%%%%%%%%%%%%%%%%%%%%%%%%
%%%%%%%%%%%%%%%%%%%%%%%%%%%%%%%%%%%%%%%%%%%%%%%%%%%%%%%%%%%%%%%%%%%%%%%%%%%%%
%%%%%%%%%%%%%%%%%%%%%%%%%%%%%%%%  APPENDIX
%%%%%%%%%%%%%%%%%%%%%%%%%%%%%%%%%%%%%%%%%%%%%%%%%%%%%%%%%%%%%%%%%%%%%%%%%%%%%
%%%%%%%%%%%%%%%%%%%%%%%%%%%%%%%%%%%%%%%%%%%%%%%%%%%%%%%%%%%%%%%%%%%%%%%%%%%%%
\appendix

\section{Schematics}
\label{appa}

\subsection{Pre-made processor breakout boards}
For the TPM board, CDH board, and IMU logger board, existing processor breakouts will be used due to shortages of bare chips.
\begin{figure}[H]
	\centering
	
	\caption{Feather M4 Express schematic, used in the main CDH board.}
	\label{fig:schematic-featherm4}
\end{figure}
\begin{figure}[H]
	\centering
	
	\caption{Feather M0 schematic, used in the IMU logger and TPM boards.}
	\label{fig:schematic-featherm0}
\end{figure}

\newpage
\subsection{TC to Digital Schematics}
Figures \ref{fig:schematic-tc-breakout-p1} and \ref{fig:schematic-tc-breakout-p2} show the schematics of the 6 channel TC to digital converter breakout board.
\begin{figure}[H]
	\centering
	
	\caption{TC to digital schematics, page 1/2}
	\label{fig:schematic-tc-breakout-p1}
\end{figure}

\begin{figure}[H]
	\centering
	
	\caption{TC to digital schematics, page 2/2}
	\label{fig:schematic-tc-breakout-p2}
\end{figure}

\newpage
\subsection{Main CDH Schematics}
Figures \ref{fig:schematic-cdh-p1} and \ref{fig:schematic-cdh-p2} show the schematics of the main CDH PCB.
\begin{figure}[H]
	\centering
	
	\caption{Main CDH schematics, page 1/2}
	\label{fig:schematic-cdh-p1}
\end{figure}
\begin{figure}[H]
	\centering
	
	\caption{Main CDH schematics, page 2/2}
	\label{fig:schematic-cdh-p2}
\end{figure}

\newpage
\subsection{TPM Schematics}
Figures \ref{fig:schematic-tpm-p1} and \ref{fig:schematic-tpm-p2} show the schematics of the TPM subsystem PCB.
\begin{figure}[H]
	\centering
	
	\caption{TPM schematics, page 1/2}
	\label{fig:schematic-tpm-p1}
\end{figure}
\begin{figure}[H]
	\centering
	
	\caption{TPM schematics, page 2/2}
	\label{fig:schematic-tpm-p2}
\end{figure}

\newpage
\subsection{IMU Logger Schematics}
Figures \ref{fig:schematic-imu-p1}, \ref{fig:schematic-imu-p2}, and \ref{fig:schematic-imu-p3} show the schematics of the IMU logger PCB.
\begin{figure}[H]
	\centering
	
	\caption{IMU logger schematics, page 1/3}
	\label{fig:schematic-imu-p1}
\end{figure}
\begin{figure}[H]
	\centering
	
	\caption{IMU logger schematics, page 2/3}
	\label{fig:schematic-imu-p2}
\end{figure}
\begin{figure}[H]
	\centering
	
	\caption{Page 3/3}
	\label{fig:schematic-imu-p3}
\end{figure}

\newgeometry{margin=2cm} % modify this if you need even more space
\begin{landscape}
\section{Test Matrix}
\label{appendix-testing}
\begin{table}[!bp]
	\centering
		%\begin{minipage}{0.95\textheight}
			\def\arraystretch{1.75}
			\small\centering
			\setlength{\tabcolsep}{1.0mm}
			\scriptsize
			\centering
			\caption{Test matrix for avionics integration verifications}
			\label{my-label}  
			
			\begin{table}[H]
				\scriptsize
				\begin{tabular}{p{3cm} | p{13cm}  L p{5cm}}
					\textbf{Test Name} &\textbf{ Description, verification or procedure}& \textbf{ ECD / Progress} & \textbf{Problems/Notes} \\
					\hline
					IMU accuracy test &  Verify recorded axes orientation for all acceleration and inertial sensors matches documentation and that data received over the recovery data interfaces looks reasonable. &  Done &  \\
					
					Javad GPS testing & Verify that the CDH processor is communicating with the GPS card and that logging of RTK data is happening & TBD & Javad will require a 5v boost circuit from the 4.2v system battery, these are already acquired and ready to use \\
					
					Iridium packet test & Verify that Irdium packets are transmitted starting when GPS signal is acquired and that they contain valid GPS fixes and velocities read from the sensor. & 3/8/22 & Depends on Javad GPS arrival time \\
					
					TPMS accuracy testing & activate the avionics in multiple trials and heat the thermocouples to varying and known temperatures (i.e. with a soldering iron set to different temperatures, verify with external TC). Verify by comparing to log file and make sure TC's are reporting valid and consistent temperatures. Make sure temperatures across trials are consistent. & 3/8/22 & \\
					
					CDH: wireless configuration & ensure that the ISM band radio in the capsule can be used for last minute verification of functionality and configuration & 3/21/22 & Testing will be concurrent with all software development and evaluation \\
					
					Power consumption test & Measure current draw of system for various operational states including all sensors on and logging (including GPS) with Iridium transmitting as well as a full power save mode (possibly to be used after detection of impact) & 3/21/22 & Need a current measuring probe for tektronix oscilloscope \\
					
					Last minute charging & Provision a wired connector through one of the three holes in the backshell so that the device may be charged or just operated on auxiliary power (not using batteries) for final configuration and checks. & 3/14/22 & Depends on power consumption test \\
					
					Run out of power test & Ensure that logfiles stay intact if the device were to drain itself of power after touchdown. Verify that the connector does indeed charge the batteries. & 3/8/22 & A shutdown could be implemented so that if mission time is greater than 20 minutes or the GPS velocity is less than some threshold, the system goes into a low power state. \\
					
					Physical fit test & Ensure all components will fit in alotted space in capsule & Done & \\
					
					Integration test & Using a plastic mock-up of the forebody, verify that the mounting plates/standoffs/bolts etc. allow for the avionics to be properly mounted.  & 2/21/22 \\
					
					CO$_2$ Ejection test & Ensure reliability of release servo interface to CDH processor by repeatedly triggering the servo and observing it works. & 3/1/22 &  Need to ensure running tasks such as SD logging and sensor acquisition do not interfere with the timing of the servo library and allow for repeatable and consistent servo control. A dedicated servo board may be necessary if this is a problem. \\
					
					Pyro cutter test & Using two pyro cutters, like will be used in the mission, pull tension on parachute cords indicative of the tension expected once the drogue is deployed, and fire them using test software. & 3/7/22 & Pyro cutter lead time and cost. Need to make sure this goes right the first time. \\
					
					Paracute truck test & At speed of 30-40 mph, release the parachute from the dummy capsule after integration test and Co$_2$ ejection test to verify that the drogue comes out as planned. Assuming the drogue comes out as planned, allow for manual triggering of the pyro cutters to verify that the drogue is cut loose. & 3/14/2022 & Dependent on pyro cutter test and CO$_2$ test \\

				\end{tabular}
			\end{table}
	%\end{minipage}
\end{table}
\end{landscape}
\restoregeometry

\newgeometry{margin=2cm} % modify this if you need even more space
\begin{landscape}
\section{Project Schedule Gantt 2022}
The schedule shown in Fig. \ref{fig:schedule22} shows the 2022 schedule for the capsule avionics. A general breakdown of work in the Gantt is as follows:

\begin{itemize}
	\item Test hardware: the CDH, TPMS and IMU boards have been assembled and preliminarily tested with bare-bones software to ensure solder connections and schematic designs are functional.
	\item Software development is ongoing.
	\item Test hardware evaluation is also ongoing. This is a big task that involves verifying the wireless debug interface to the capsule, the accuracy of the TC measurements through testing, and the ability of the CDH to reliably trigger the CO$_2$ servo and pyro cutters, as well as Javad GPS integration and Iridium modem testing. Parts of this have been independently verified, for example, sending Iridium packets with GPS information is functional, but that's with a testing GPS and not the same as testing when the Javad GPS is attached for various technical reasons.
	\item This is in progress. John has designs for mounting plates for the hardware. The mounting hardware is being acquired at the time of writing and test integration is in progress on the plastic forebody mockup.
	\item Refinement. This was a backup task in case the test hardware wasn't functional. This allows provisioning for a external servo trigger and power booster for the Javad GPS.
\end{itemize}

\label{app-schedule-22}
\begin{figure}[H]
	\centering
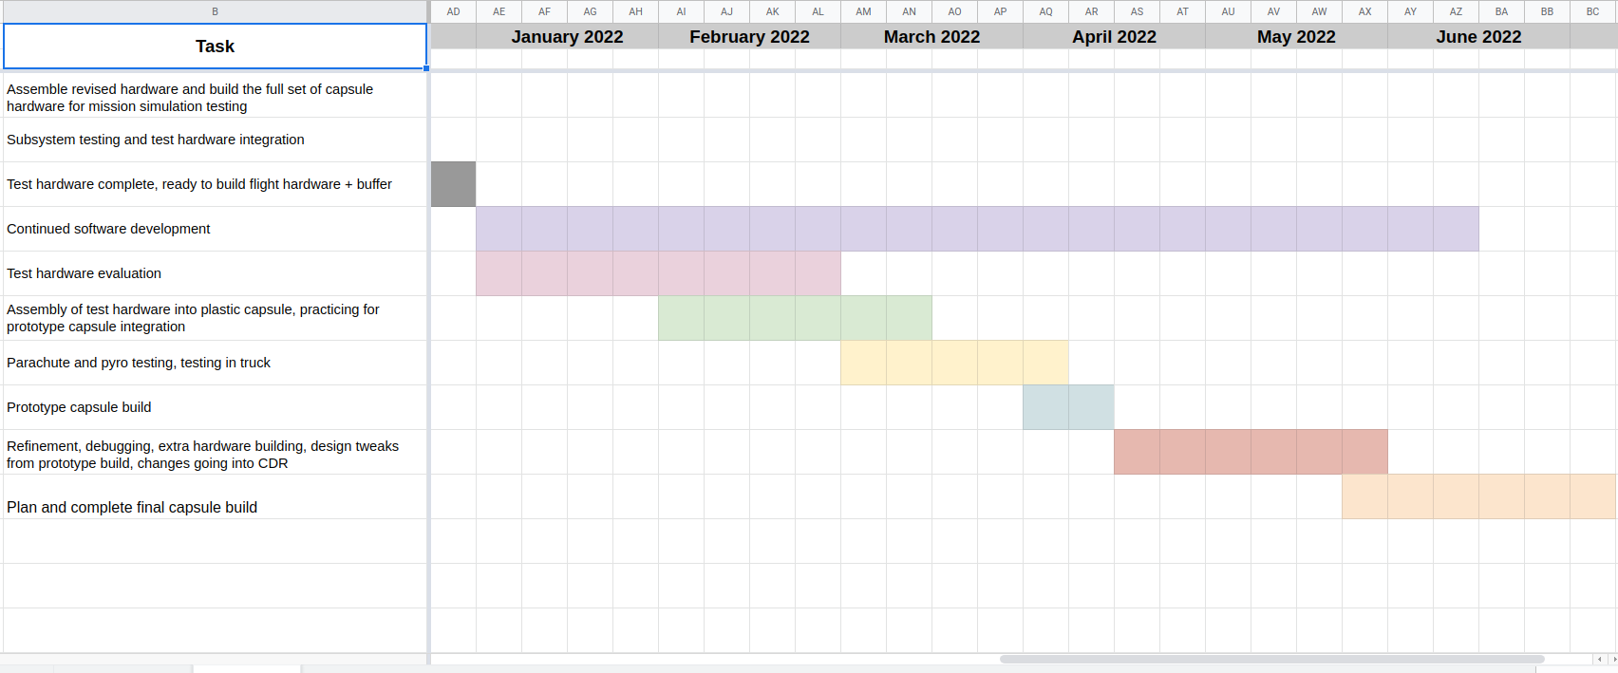
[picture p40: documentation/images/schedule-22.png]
	
	\caption{Approximate schedule for completion of prototype and final build.}
	\label{fig:schedule22}
\end{figure}

\end{landscape}
\restoregeometry

\newgeometry{margin=2cm} % modify this if you need even more space
\begin{landscape}
\section{Project Schedule Gantt 2021}
\label{app-schedule-21}
This schedule in Fig. \ref{fig:schedule} shows that the project schedule for 2021. The avionics design and assembly process went well and was on schedule moving into 2022.
\begin{figure}[H]
	\centering
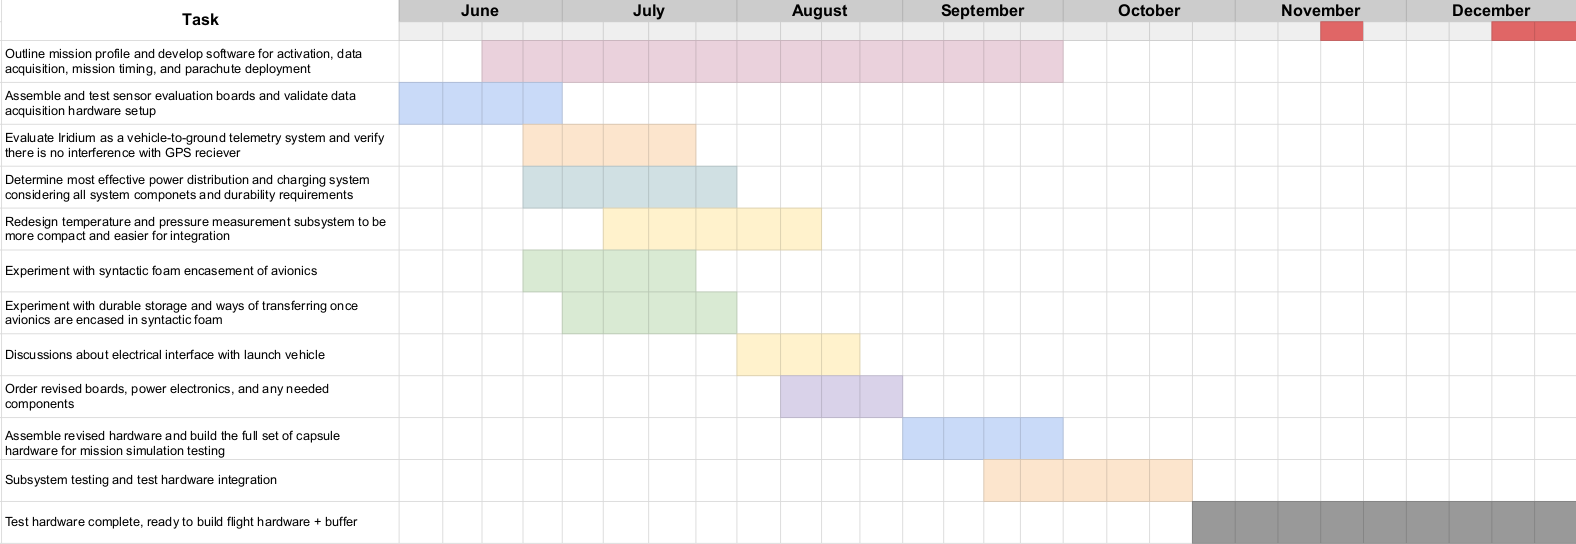
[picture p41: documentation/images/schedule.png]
	
	\caption{Approximate schedule for completion of prototype and final build.}
	\label{fig:schedule}
\end{figure}
\end{landscape}
\restoregeometry

%\bibliographystyle{plain}
%\bibliography{references}
\end{document}

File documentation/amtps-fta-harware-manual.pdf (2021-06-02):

# AMPTS FTA Electronic Hardware Design

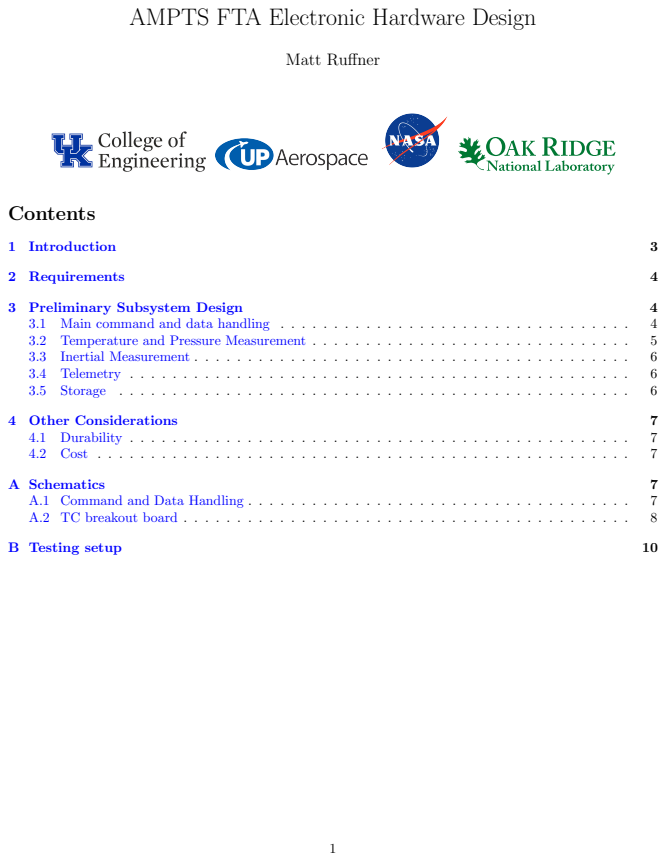
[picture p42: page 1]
Matt Ruffner; Contents; 1 Introduction; 2 Requirements; 3 Preliminary Subsystem Design; 4 Other Considerations; A Schematics; B Testing setup

## List of Figures

1 | Capsule component overview, showing the various functional blocks | | 3
2 | Main functional components of the capsule and the communication buses between them. . . . | 5
3 | Overview of the TPMS | | 6
4 | Bottom of V1 Evaluation board for MCP9600 TC to digital converter | | 10
5 | Top of V1 Evaluation board for MCP9600 TC to digital converter | | 11
6 | High g accelerometer testing PCB | | 11
7 | Testing setup for the pressure sensors | | 12

## List of Tables

1 | List of processors used and their capabilities | | 4
2 | List of pressure sensors and their capabilities | | 5

2

## 1 Introduction

This document outlines the initial design of electrical hardware that will support the flight test article (FTA) being developed for the NASA Flight Opportunities Additive Manufacturing of Thermal Protection Systems (AMTPS) project. This project is a collaboration between several NASA facilities including JSC and Langley as well as other research institutions including the University of Kentucky and Oak Ride National Laboratories. Figure 1 shows a general overview of the various components that are expected to be a part of the flight test article (referred to as ’the capsule’) based on current requirements.
Capsule hardware must be capable of robust data acquisition in order to characterize the thermal, pressure, and overall heating environment of supersonic reentry. In addition to collecting multiple data channels, the hardware must be capable of transmitting its location as it about to touch back down to Earth. The multichannel data acquisition system must also save flight data for analysis after it touches back down. Timing the deployment of a parachute before touchdown is also a requirement of the hardware in order to lessen the force of impact.
This document is organized as follows: Section 2 discusses needed capabilities set by the NASA project design document (rev. E) that are relevant to the avionics hardware. Section 3 displays the preliminary designs and testing hardware for the various subsystems of the capsule. This includes data acquisition, logging, and vehicle-to-ground communication for recovery operations. Appendix A contains schematics for PCBs that have been prototyped. Appendix B contains images of testing hardware that has been developed.

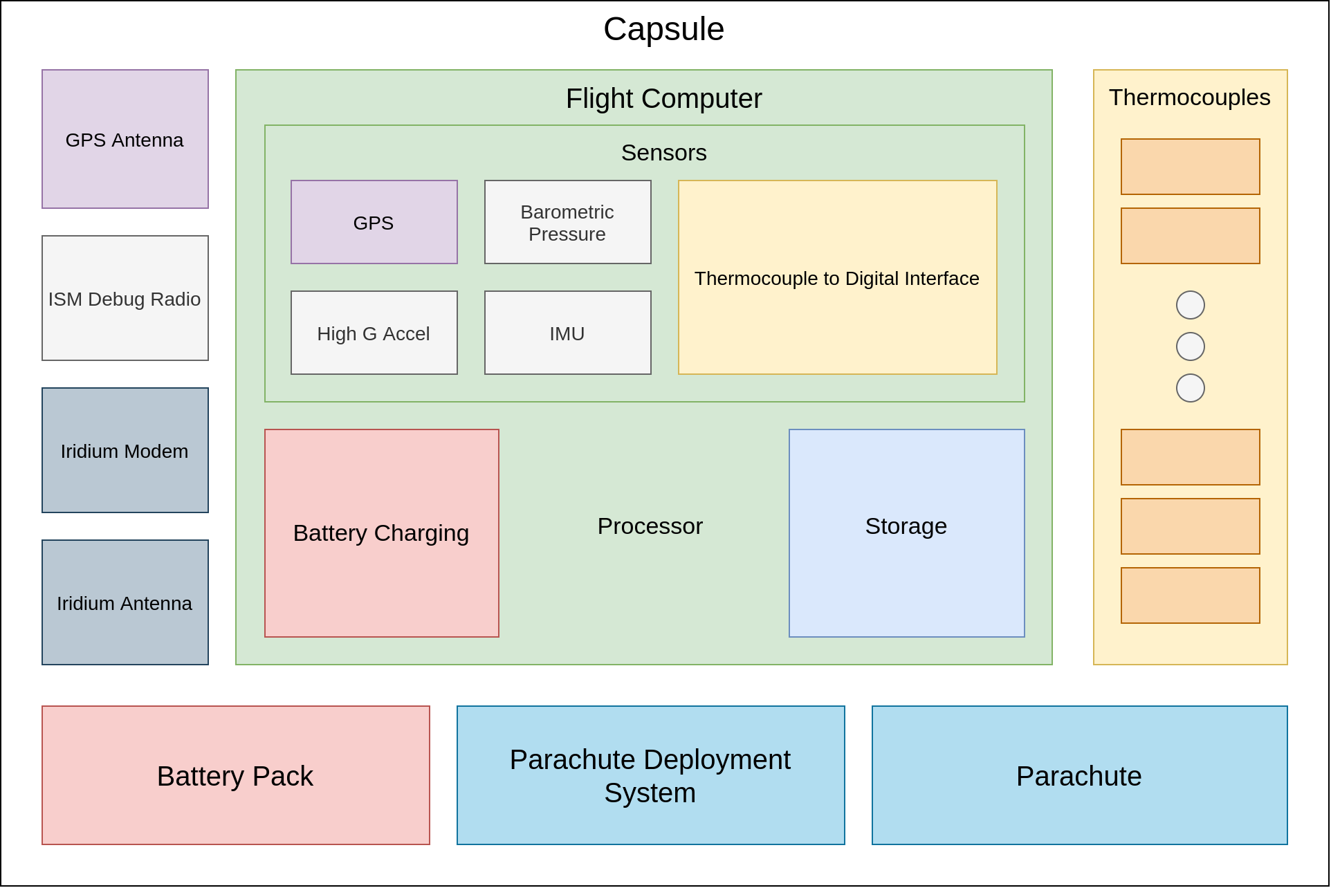
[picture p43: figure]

Figure 1: Capsule component overview, showing the various functional blocks.

3

## 2 Requirements

Based off of the most recent revision (E) of the flight test requirements document.

1. Instrumentation and telemetry
(a) Shall support betwen 8 and 20 thermocouples of varying type
(b) Shall support up to 6 absolute pressure sensors
(c) Shall support at least 1 intertial measurement unit (IMU)
(d) Should support 1 heat flux sensor
(e) Shall contain a GPS for recovery operations
(f) Telemetry data shall be collected at a minumum of 10Hz
(g) Telemetry data shall be stored to onboard nonvolatile memory that will survive landing
(h) Location telemetry shall be transmitted through a vehicle-to-ground system (e.g. Iridium satellite, Xbee)
2. Activation and flight sequencing
(a) Shall be powered through the duration of the flight
(b) Shall support continuous operation between -20 deg C and 80 deg C
(c) Shall support pre-launch activation on the ground; should support low power mode prior to deployment
(d) Shall detect and/or sense when depoyment has occurred via interfacing with the launch vehicle
(e) Shall trigger parachute deployment at a specified time.

## 3 Preliminary Subsystem Design

### 3.1 Main command and data handling

Using off the shelf processors for convenience, and also to avoid bottlenecks in prototyping due to unpredictable chip shortages. Currently, two development boards from Adafruit are being used to prototyping and are listed below in Table 1

12

Table 1: List of processors used and their capabilities.
Part | Description | Role | Product Link
Feather M0 Basic Proto | Cortex-M0 @ 48 MHz | TPM Processor | https://www.adafruit.com/
| | | product/2772 (https://www.adafruit.com/product/2772)
Feather M4 Express | Cortex-M4 @ 120Mhz | CDH Processor | https://www.adafruit.com/
| | | product/3857 (https://www.adafruit.com/product/3857)

The diagram in Figure 2 provides a general overview of the organization of electronic hardware within the capsule.

1TPM: Temperature and Pressure Measurement
2CDH: Command and Data Handling

4

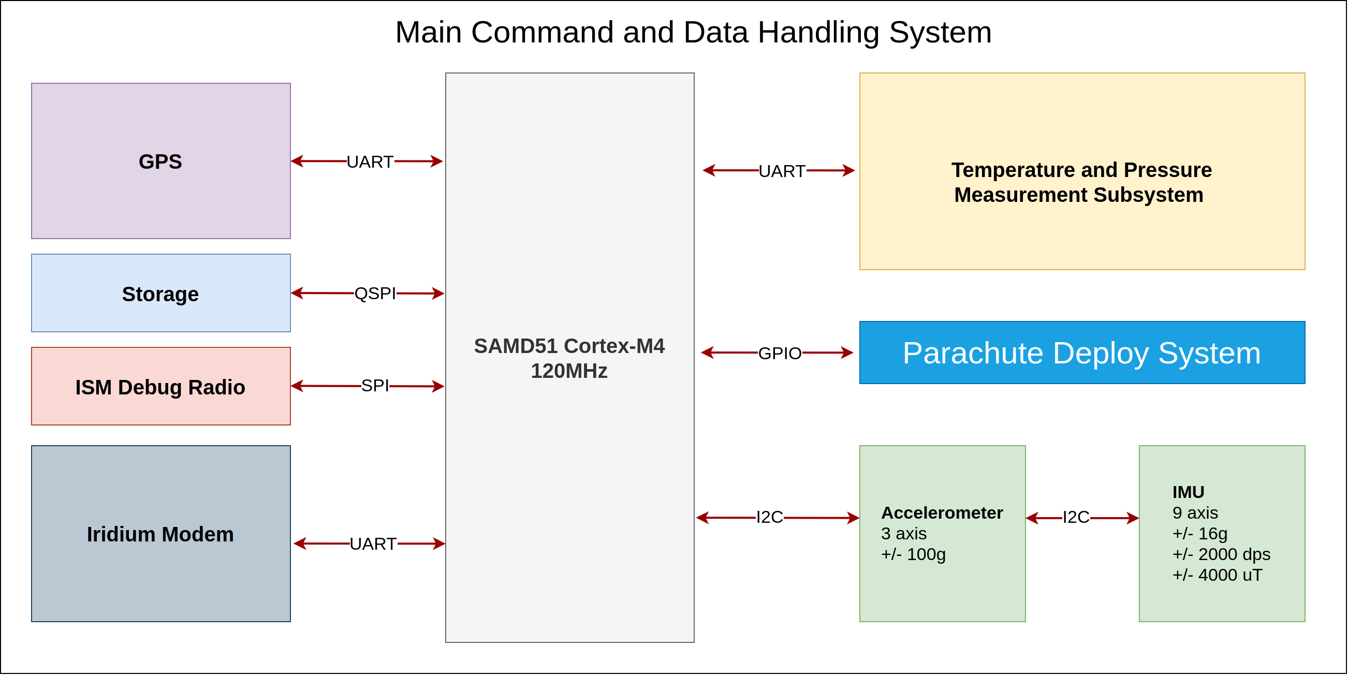
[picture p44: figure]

Figure 2: Main functional components of the capsule and the communication buses between them.

### 3.2 Temperature and Pressure Measurement

The temperature and pressure measurement (TPM) Subsystem (TPMS) supports collection of several datapoints needed for recreating the heating environment of reentry.
In order to support the large number of TCs required in the capsule, a breakout board supporting 6 of the MCP9600T-E/MX series TC to digital converter was designed. This TC converter chip was selected due to its support for a wide variety of TC types (K, J, T, N, S, E, B and R)³

, as well as its chainable I²C interface, allowing more sensing elements to connected with less wiring (similar SPI based conversion chips have a chip select line per chip that would restrict the number of pins available for other capsule functionality).
A breakout board was designed with 6 MCP9600 converter chips to serve as an initial design for a t ewill be done on a breakout
For pressure meausrement, Honeywell sensing solutions temperature compensated absolution digital pressure sensors were selected and are shown in Table 2. These single port absolute pressure sensors are available with a variety of sensitivities, allowing a different sensor to be exchanged later on in the design process if it is determined that the current predicted pressure environment is no longer accurate.
A picture of the preliminary pressure sensor evaluative setup in shown in Appendix B, Figure 7.

Table 2: List of pressure sensors and their capabilities
Part | Measurement Range | Product Link
SSCSRNN015PA3A3 | 0-103.42 kPa | https://www.digikey.com/en/products/detail/ honeywell-sensing-and-productivity-solutions/ SSCSRNN015PA3A3/2416212 (https://www.digikey.com/en/products/detail/honeywell-sensing-and-productivity-solutions/SSCSRNN015PA3A3/2416212)
SSCSRNN1-6BA7A3 | 0-160 kPa | https://www.digikey.com/en/products/detail/ honeywell-sensing-and-productivity-solutions/ SSCSRNN1-6BA7A3/2416214 (https://www.digikey.com/en/products/detail/honeywell-sensing-and-productivity-solutions/SSCSRNN1-6BA7A3/2416214)

Finally, Figure 3 shows an overview of the temperature and pressure monitoring subsystem

3https://www.digikey.com/en/products/detail/microchip-technology/MCP96L00T-E-MX/9606988

| | 5

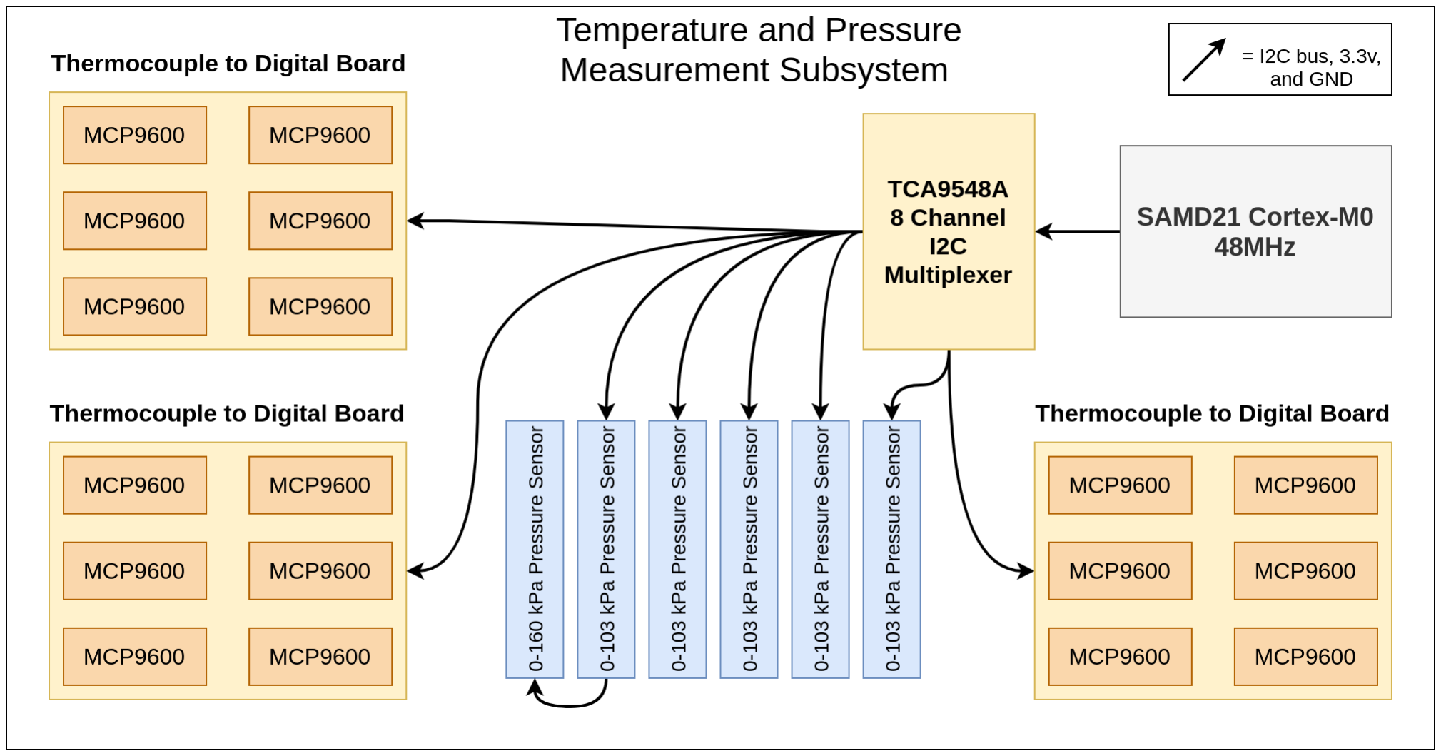
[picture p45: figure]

Figure 3: Overview of the TPMS.

### 3.3 Inertial Measurement

A breakout board for the H3LIS100DL 4 +/- 100g accelerometer has been designed to help in the evaluation of this IC as an effective way to measure acceleration loads on the capsule. The ADXL377 is another potential high-g 3-axis acceleromter 5
, but has analog output and higher cost since it is currently only available in a pre-assembled breakout board.
In addition to a high-g 3-axis accelerometer, a lower dynamic range 6 axis acceleromter+gyroscope chip will also be included in the capsule (such as a ICM-20949 or MPU6050).

### 3.4 Telemetry

Iridium modem to send GPS coordinates for recovery operations. University of Kentucky has an Iridium modem available to use, with an account providing message credits. Discussion on the use of this modem is yet to have happened. Additional vehicle-to-ground telemetry would be reassuring as the Iridium network can be unreliable for short periods of time. It is unclear whether this would be achievable with a COTS radio link (such as XBee or LORA) that would not require FCC certification. This requires coordination with launch site for tracking with a directional antenna and other hardware setup. The appeal of the Iridium is we get an email with the GPS coordinates of the capsule and we can tell the recovery crew the location of the capsule from anywhere.

### 3.5 Storage

On board non-volatile storage is required to log in-flight telemetry data for post processing. Due to the high vibrational loads expected during launch, an SD card might be unreliable (spring loaded contacts could separate from card). For this reason, solid state flash integrated circuits are being explored that can store just as much information as an SD card.

4https://www.digikey.com/en/products/detail/stmicroelectronics/H3LIS100DL/73132785https://www.adafruit.com/product/1413

6

Exporting logged data from the capsule would then be done via cabled connection to a computer after capsule recovery.

## 4 Other Considerations

### 4.1 Durability

Syntactic foam may be used. Consisting of glass microballoons with epoxy resin, it can encase electronics to protect from very high acceleration loads during ascent. Currently working with NASA JSC to get glass microballoons to UK for testing.

### 4.2 Cost

According the the most recent revision of the project outline, NASA has alotted $3,000 towards the avionics design. Currently the University of Kentucky has not used any of these funds in the prototyping of capsule hardware.

## A Schematics

A.1 Command and Data Handling

Schematics for the Cortex-M0/M4 development boards are available from the links provided to the Adafruit product pages.

7

A.2 TC breakout board


8


9

## B Testing setup


Figure 4: Bottom of V1 Evaluation board for MCP9600 TC to digital converter

10

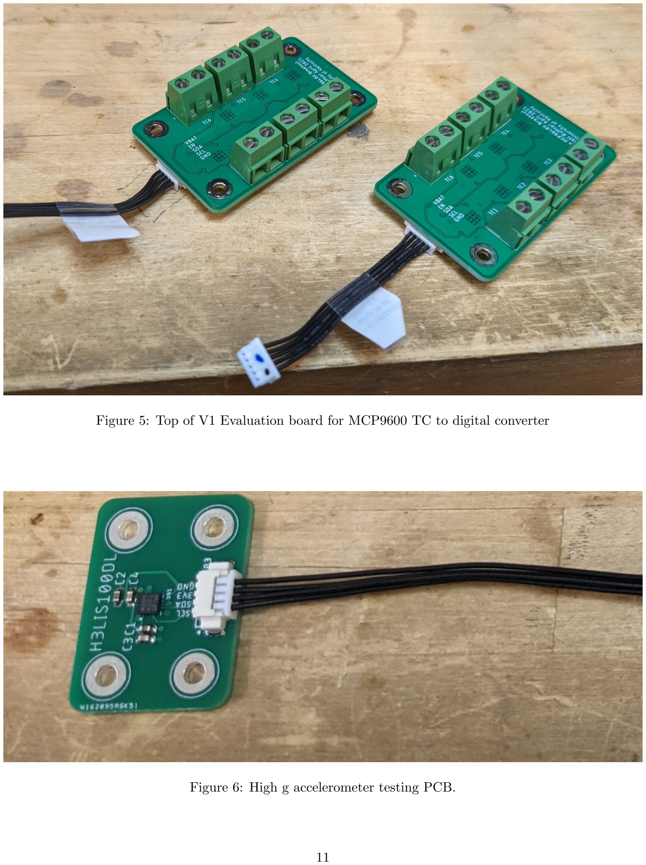
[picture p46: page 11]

Figure 5: Top of V1 Evaluation board for MCP9600 TC to digital converter

Figure 6: High g accelerometer testing PCB.

11

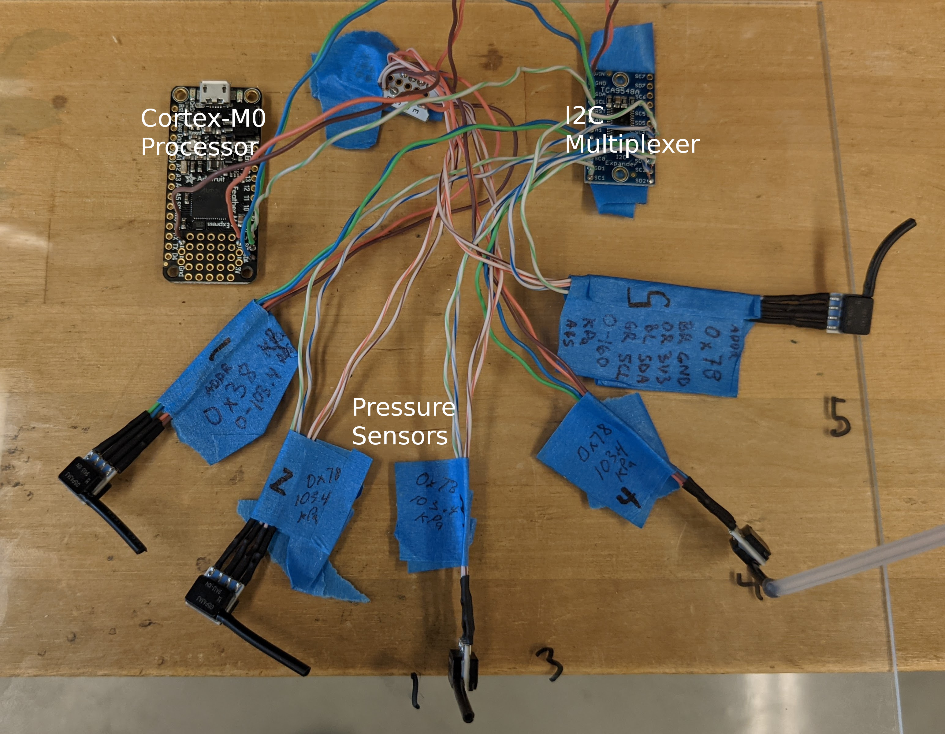
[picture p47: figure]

Figure 7: Testing setup for the pressure sensors.

12

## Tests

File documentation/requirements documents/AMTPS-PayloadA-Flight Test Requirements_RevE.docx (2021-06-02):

Additive Manufacturing of Thermal Protection Systems (AMTPS)

Flight Test Requirements

Rev. E (5/18/2021)

A. Sidor

Version History:

Rev C (2/19/2021): Initial Word format release

Rev D (3/23/2021): Added goal for post-flight reconstruction; added detail on telemetry; updated baseline diameter and mass budget; add cover page

Rev E (5/18/2021): Add OML figure, stagnation point pressure; change number of TPS formulations; add req’ts related to ejection mechanism cradle

# Flight Test Goals

1. Design, fabricate, fly, and recover a small capsule with an additively manufactured (AM) thermal protection system (TPS) on a suborbital sounding rocket flight.
2. The capsule shall be launched onboard a suborbital rocket and be separated/deployed from the rocket exoatmospherically. The capsule shall then descend through the atmosphere, exposing the AMTPS to aerothermodynamic heating.
3. The capsule shall land such that the AMTPS is sufficiently intact to enable meaningful post-flight inspection.
4. Post-flight reconstruction of the trajectory shall be sufficient to establish the environmental conditions experienced by TPS to within TBD uncertainty.

# Requirements

## 1. Geometry

  a. The capsule shall use a 45 degree sphere-cone geometry based on the Mars Microprobe outer mold line (OML) shown in Figure 1. The OML consists of a blunted 45 degree cone with a hemispherical backshell.

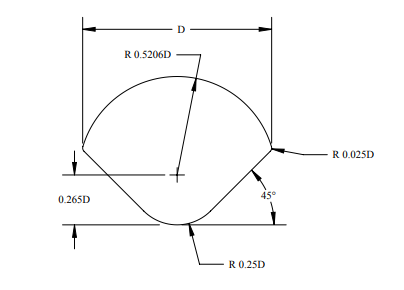
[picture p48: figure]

Figure 1. Nominal outer mold line (OML) geometry

  b. The maximum diameter of the capsule, D, shall be no more than 16 inches with a target diameter of 14 inches.
    i. The nose radius of the capsule shall be no more than 25% of the maximum diameter. Smaller nose radii are acceptable to increase stagnation point heating. However, aerodynamic stability must be maintained (Section 8).

## 2. Masses

  a. The hypersonic ballistic coefficient of the capsule (defined as the mass over the drag area) shall target 300 kg/m² (and no less than 285 kg/m²) to ensure that target entry heat fluxes can be met (Requirement 4.c.)
  b. The total capsule mass is not to exceed 40 kg with a target mass of 30 kg. Targets by subsystem are as follows:
    i. TPS: 3.5 kg
    ii. Structures (minus ballast): 6 kg
    iii. Ballast: Allowed to vary to meet target mass
    iv. Avionics: 0.5 kg
    v. Recovery (parachute and deployment mechanism): 2.5 kg

## 3. Budget

  a. Total cost for the flight test hardware, materials, and testing shall not exceed $60,000, with a target of $45,000. Tentative targets by subsystem are listed below. (Note: these targets may be exceeded by up to 33% and larger exceptions may be possible.)
    i. TPS: $10,000
    ii. Structures: $25,000
    iii. Avionics: $3,000
    iv. Recovery: $3,000
    v. Testing (Mechanical and Vibration): $2,000
    vi. Testing (NDE): $2,000

## 4. Mission Profile

  a. The launch vehicle shall deliver the capsule to a minimum speed of Mach 6 (and desired speed of Mach 10) at entry interface. Entry interface shall be considered to occur at an altitude of 125km above mean sea level.
  b. A separation mechanism shall deploy the capsule exoatmospherically prior to entry interface. The capsule must separate from the rocket without re-contact of the two bodies.
  c. Targeted entry environment parameters are outlined below:
    i. Forebody
      1. Peak heat flux at the capsule stagnation point
        a. Minimum: 20 W/cm2
        b. Target: 100 W/cm2
      2. Peak heat flux along flank of forebody
        a. Minimum: 10 W/cm2
        b. Target: 50 W/cm2
      3. Peak stagnation point pressure
        a. Minimum: 30 kPa
        b. Target: 150 kPa
    ii. Backshell
      1. Peak heat flux along capsule backshell
        a. Maximum: TBD

## 5. Instrumentation and Telemetry

  a. The following instrumentation/sensors shall be included in the capsule design:
    i. Forebody:
      1. Thermocouples: 2 locations / 2 TCs each minimum (3 locations / 4 TCs each desired)
      2. Pressure: TBD minimum (TBD desired)
      3. Heat flux: None required (1 desired)
    ii. Backshell
      1. Thermocouples: 1 location / 2 TCs minimum (2 locations / 4 TCs each desired)
      2. Pressure: None required (1 desired)
      3. Heat flux: None
    iii. Internal
      1. IMU: 1 minimum (2 desired)
      2. Barometric pressure: 1 minimum (1 desired)
      3. Position/altitude (e.g., GPS): 1 minimum (1 desired)
  b. Telemetry shall be collected at the following rates during the entry (if sensor is present). These are peak rates, which may be reduced during non-critical segments of the flight. “Non-critical” shall be determined by the development team.
    i. Forebody:
      1. Thermocouples: 10Hz minimum
      2. Pressure: 10Hz minimum (24Hz desired)
      3. Heat flux: 10Hz minimum
    ii. Backshell:
      1. Thermocouples: 10Hz minimum
      2. Pressure: 10Hz minimum (24Hz desired)
    iii. Internal:
      1. IMU: TBD
      2. Barometric pressure: TBD
      3. Position/altitude: TBD
  c. All data from all sensors shall be stored onboard a physical storage device with sufficient capacity. The storage device must survive intact for post-flight data recovery and analysis.
  d. In-Flight Telemetry:
    i. Telemetry shall be transmitted through at least one vehicle-to-ground system to aid with post-flight recovery and in the event onboard data is not recovered.
    ii. In-flight telemetry rates may be reduced to allow real-time transmission (rates TBD).
    iii. In-flight telemetry shall include the vehicle position, at minimum, to aid with locating the capsule after landing. It is desired that vehicle velocity also be telemetered in-flight.
  e. Post-Flight Telemetry:
    i. The capsule position should continue to be transmitted post-landing to aid in recovery operations.
    ii. Post-flight position telemetry shall be transmitted at a minimum rate of 1 packet every 5 minutes (with a target of 1 packet every minute).
    iii. Post-flight position telemetry shall be accurate to within +/- 100 meters (with a target of +/- 20 meters).

## 6. Thermal / TPS

  a. The TPS shall withstand loads encountered while installed in the launch vehicle payload bay without damage. That includes loads encountered during installation and launch. (Cross-reference Requirement 12.b.ii.)
  b. The TPS shall withstand loads encountered during ejection/deployment.
  c. The TPS shall be designed to withstand the expected entry environment without failure either within the material or at the bondline (see Section 3: Target Environmental Conditions).
  d. The TPS shall ablate and decompose in a controlled and predictable manner with no spallation.
  e. The interior of the capsule and avionics system shall be maintained within an acceptable temperature range during the entirety of the flight: launch, exoatmospheric flight, entry, landing, and recovery. See Requirement 9.a.

## 7. Manufacturing

  a. The TPS shall be manufacturable in the AMTPS robotic cell under development at Oak Ridge National Lab (ORNL).
    i. Size and geometric complexity shall be limited to that achievable within the AMTPS cell.
    ii. The selected TPS material must be compatible with all processing equipment within the AMTPS cell.
    iii. The selected resin and filler components must meet all necessary safety and health requirements for approved usage in all facilities handling the materials, including NASA JSC, NASA ARC, ORNL, and any third-party vendors (e.g., toll compounder).
  b. The TPS shall consist of a graded architecture of at least 2 material formulations (3 formulations desired) spanning the thickness of the heat shield: an insulating material at the inner mold line (IML), possibly one or more transitional formulations, and a robust, charring material at the outer mold line (OML).
  c. Defect size shall be limited such that the mechanical integrity of the TPS is not compromised during any segment of the flight. Size is TBD.
  d. The heat shield shall be inspectable using one or more NDE techniques (ultrasonic, terahertz, CT, etc.). The technique(s) used shall be capable of detecting defects on the size of that required in Requirement 8.c.

## 8. Aerodynamics and Stability

  a. The capsule shall be self-righting to a nose forward direction (into the wind) prior to significant incident aerothermal heating. This point shall be determined such that any aeroheating on the backshell TPS is below that of Requirement 3.b.
  b. The capsule shall be statically stable during all flight regimes (hypersonic, transonic, and subsonic).
  c. The capsule shall be dynamically stable during all flight regimes (hypersonic, transonic, and subsonic).

## 9. Recovery

  a. The capsule shall deploy a parachute prior to landing to reduce touchdown velocity. The recovery system shall be sized such that the touchdown velocity is no more than 20 feet / sec with a targeted maximum of 15 feet / sec.
  b. Deployment shall occur at a point in the trajectory that allows successful inflation of the parachute and sufficient deceleration to meet Requirement 9.a.
  c. The recovery subsystem (including the parachute, parachute cords, fasteners, and all load-supporting components) shall be designed to support the loads encountered during deployment, opening, and descent.

## 10. Avionics and Power

  a. All electronics boards and components shall be designed to operate without interruption between -20 deg C and 80 deg C
  b. The avionics subsystem must be powered through the duration of the flight and recovery (see Requirement 4.b). If possible, hardware and/or sensors should be operated in a low power state (or turned off) when not needed. However, these devices must successfully power up when needed during the flight and/or recovery.
  c. Activation and flight sequencing:
    i. The avionics shall be designed for pre-launch activation on the ground. The avionics may be operated in a low power state prior to exoatmospheric deployment.
    ii. The avionics must detect and/or sense when deployment has occurred. This requirement may be met through interfacing with the launch vehicle (see Requirement 12.b).
    iii. The avionics shall trigger parachute deployment at a time dictated by Requirement 9.b.

## 11. Structures/Loads

  a. The capsule structure and all components attached to it shall withstand the peak axial and radial loads expected during flight. (Loads are TBD)
    i. Launch
    ii. 2nd Stage Burn (if used)
    iii. Deployment from Rocket
    iv. Entry
    v. Parachute Deployment
    vi. Landing
  b. The capsule structure and all components attached to it shall withstand the vibration environments expected during flight. (Vibration environments are TBD)
    i. Launch
    ii. 2nd Stage Burn (if used)

## 12. Launch Vehicle Integration

  a. The capsule shall be designed to fit within the payload section of the UpAerospace Spyder rocket with an internal diameter of 16.75”.
  b. The capsule must integrate with the custom ejection mechanism to be designed by the launch provider.
    i. The capsule shall provide a mechanical interface/linkage to prevent roll within the ejection mechanism prior to deployment.
    ii. The TPS shall be designed to withstand all forces exerted on it by the ejection mechanism cradle. No crushing of the TPS may occur.
  c. The rocket must provide a minimal communications interface accessible to the capsule. This interface shall provide a signal indicating when deployment/ejection occurs.

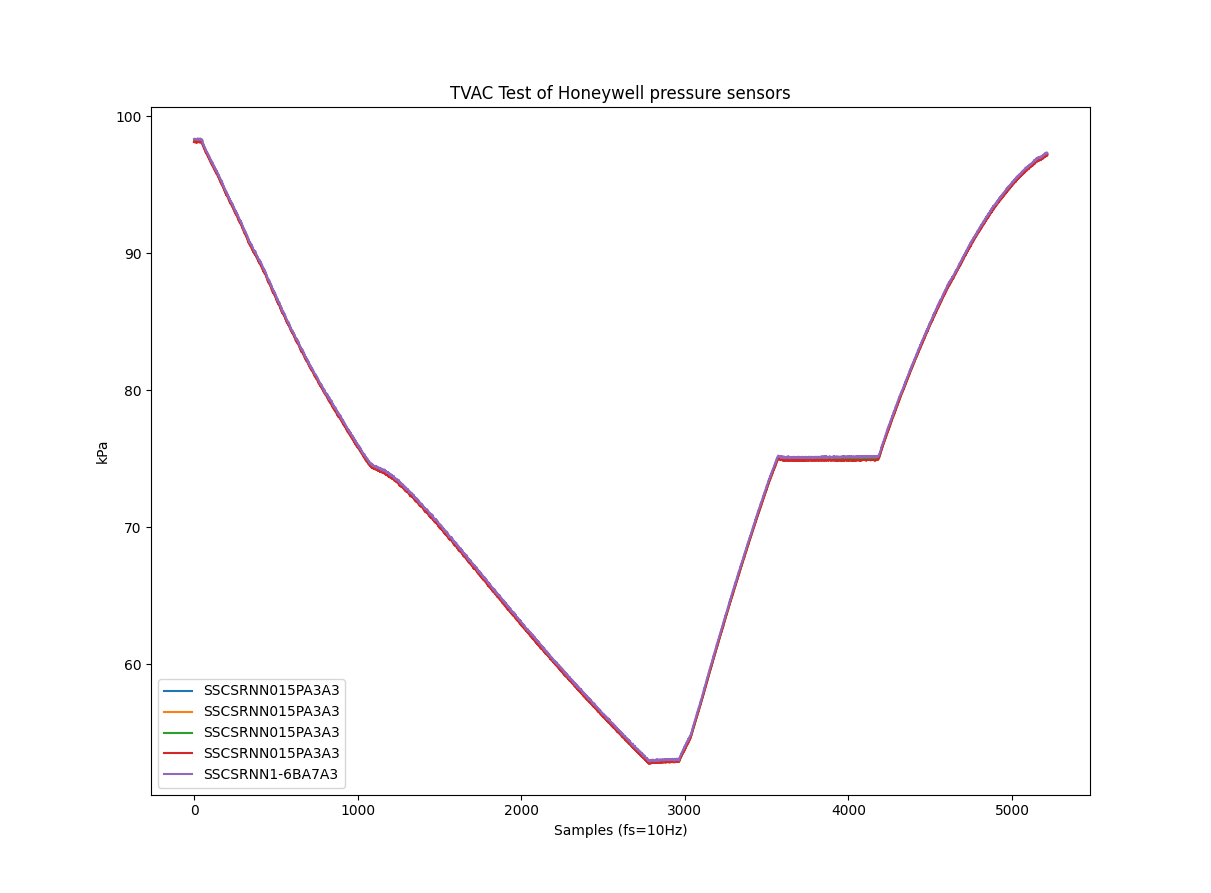
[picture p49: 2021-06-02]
testing/vacuum-pressure-sensor/tvac-20210602-large.png

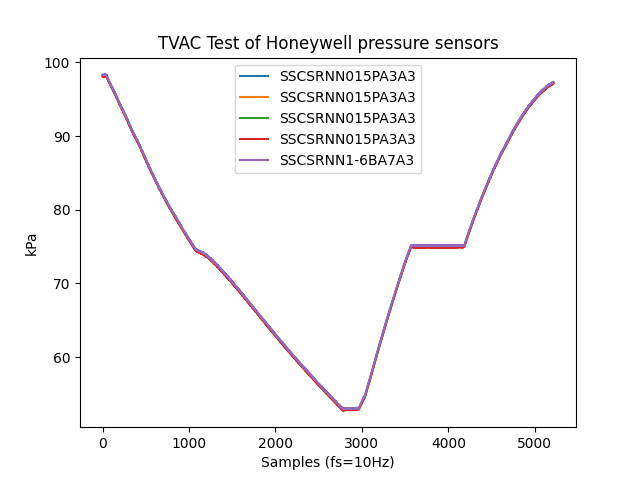
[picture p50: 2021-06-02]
testing/vacuum-pressure-sensor/tvac-20210602.png

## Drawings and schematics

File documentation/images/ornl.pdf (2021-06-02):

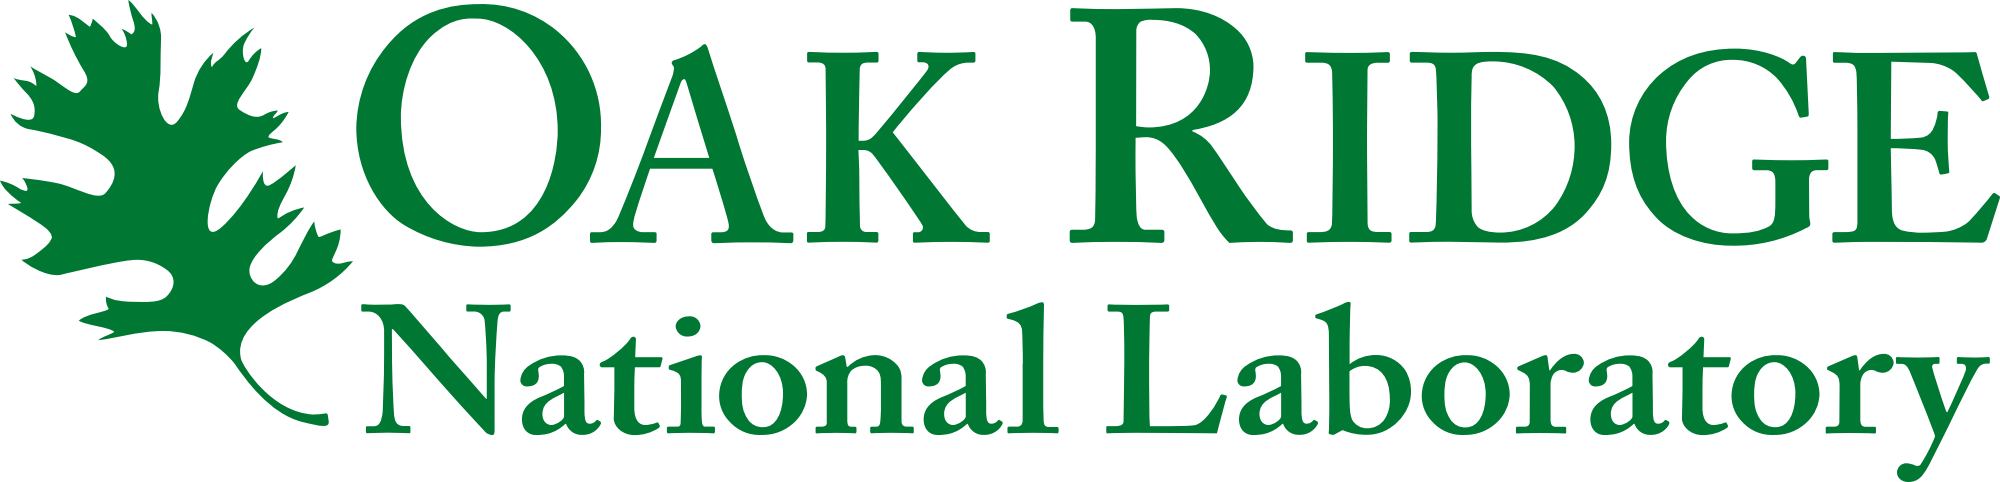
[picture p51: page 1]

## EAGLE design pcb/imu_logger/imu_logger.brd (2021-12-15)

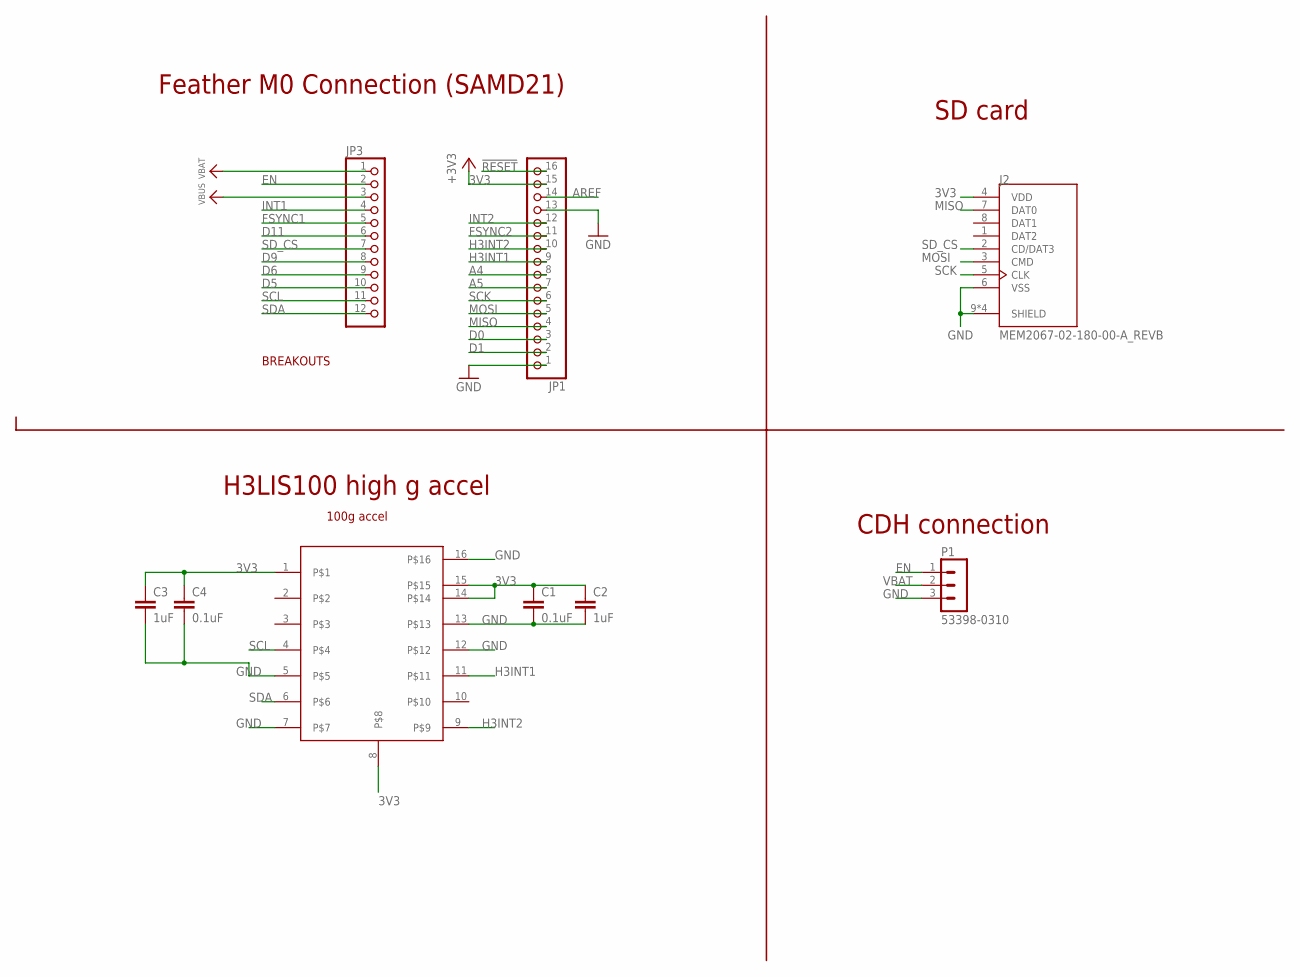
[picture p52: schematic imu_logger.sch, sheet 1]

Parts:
C1, C4: 0.1uF; C0603
C2, C3: 1uF; C0603
J2: MEM2067-02-180-00-A_REVB; GCT_MEM2067-02-180-00-A_REVB
JP1: HEADER-1X16ROUND; 1X16_ROUND
JP3: HEADER-1X12; 1X12_ROUND
P1: 53398-0310
U$1: H3LIS100DL; XDCR_LIS3DHTR

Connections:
3V3: C1.1, C2.1, C3.1, C4.1, J2.4 (VDD), JP1.15, U$1.1, U$1.8, U$1.14, U$1.15; also elsewhere on the board
!RESET: JP1.16
A4: JP1.8
A5: JP1.7
AREF: JP1.14
D0: JP1.3
D1: JP1.2
D5: JP3.10
D6: JP3.9
D9: JP3.8
D11: JP3.6
EN: JP3.2, P1.1; also elsewhere on the board
FSYNC1: JP3.5; also elsewhere on the board
FSYNC2: JP1.11; also elsewhere on the board
GND: C1.2, C2.2, C3.2, C4.2, J2.6 (VSS), J2.9 (SHIELD), J2.10 (SHIELD), J2.11 (SHIELD), J2.12 (SHIELD), JP1.1, JP1.13, P1.3, U$1.5, U$1.7, U$1.12, U$1.13, U$1.16; also elsewhere on the board
H3INT1: JP1.9, U$1.11
H3INT2: JP1.10, U$1.9
INT1: JP3.4; also elsewhere on the board
INT2: JP1.12; also elsewhere on the board
MISO: J2.7 (DAT0), JP1.4
MOSI: J2.3 (CMD), JP1.5
SCK: J2.5 (CLK), JP1.6
SCL: JP3.11, U$1.4; also elsewhere on the board
SDA: JP3.12, U$1.6; also elsewhere on the board
SD_CS: J2.2 (CD/DAT3), JP3.7
VBAT: JP3.1, P1.2; also elsewhere on the board
VBUS: JP3.3

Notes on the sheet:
BREAKOUTS
100g accel
CDH connection
SD card
Feather M0 Connection (SAMD21)
H3LIS100 high g accel

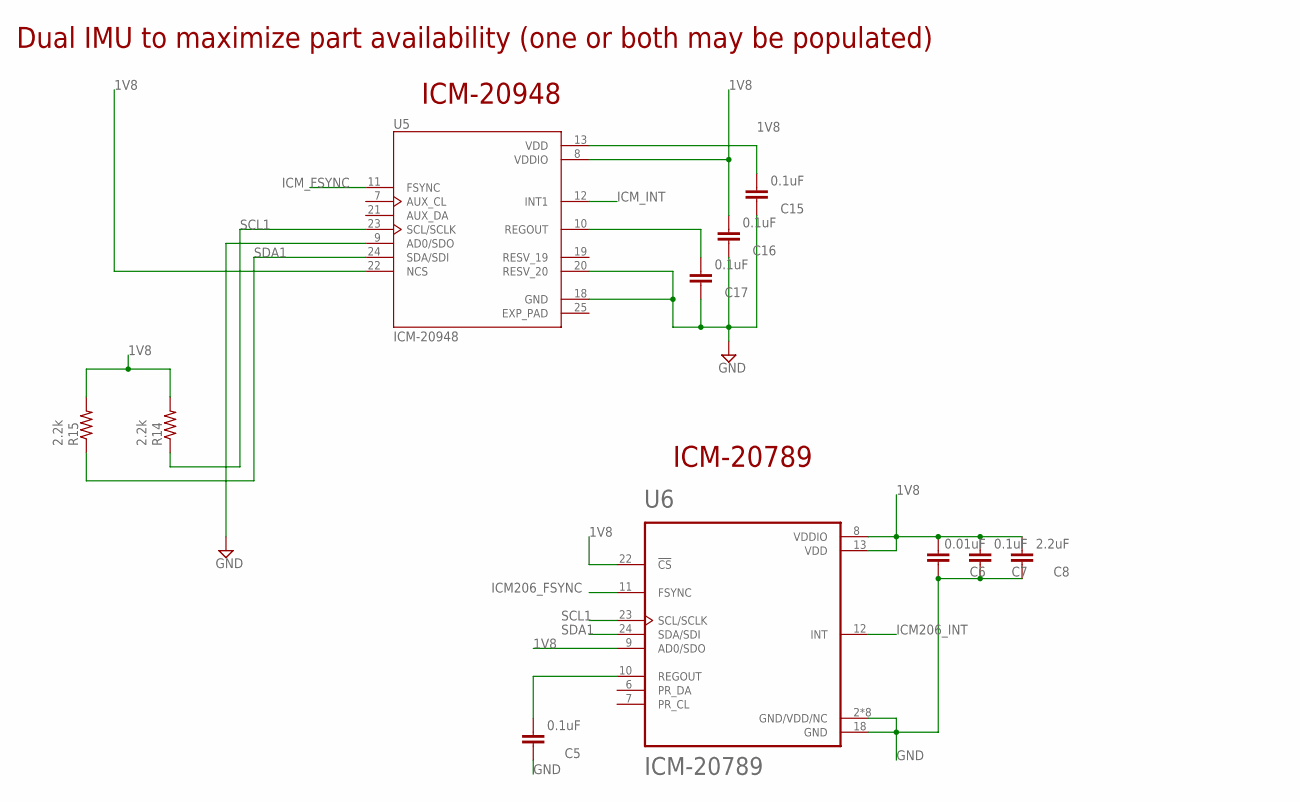
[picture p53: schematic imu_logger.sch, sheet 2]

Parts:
C5, C7, C15, C16, C17: 0.1uF; C0603
C6: 0.01uF; C0603
C8: 2.2uF; C0603
R14, R15: 2.2k; R0603
U5: ICM-20948; QFN40P300X300X105-25N
U6: ICM-20789; PQFN50P400X400X146-24N

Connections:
1V8: C6.2, C7.2, C8.2, C15.2, C16.2, R14.2, R15.2, U5.8 (VDDIO), U5.13 (VDD), U5.22 (NCS), U6.8 (VDDIO), U6.9 (AD0/SDO), U6.13 (VDD), U6.22 (!CS); also elsewhere on the board
EXP_PAD: U5.25 (EXP_PAD)
GND: C5.1, C6.1, C7.1, C8.1, C15.1, C16.1, C17.1, U5.9 (AD0/SDO), U5.18 (GND), U5.20 (RESV_20), U6.2 (GND/VDD/NC), U6.3 (GND/VDD/NC), U6.4 (GND/VDD/NC), U6.5 (GND/VDD/NC), U6.14 (GND/VDD/NC), U6.15 (GND/VDD/NC), U6.16 (GND/VDD/NC), U6.17 (GND/VDD/NC), U6.18 (GND); also elsewhere on the board
ICM206_FSYNC: U6.11 (FSYNC); also elsewhere on the board
ICM206_INT: U6.12 (INT); also elsewhere on the board
ICM_FSYNC: U5.11 (FSYNC); also elsewhere on the board
ICM_INT: U5.12 (INT1); also elsewhere on the board
unnamed: C5.2, U6.10 (REGOUT)
unnamed: C17.2, U5.10 (REGOUT)
SCL1: R14.1, U5.23 (SCL/SCLK), U6.23 (SCL/SCLK); also elsewhere on the board
SDA1: R15.1, U5.24 (SDA/SDI), U6.24 (SDA/SDI); also elsewhere on the board

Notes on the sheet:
Dual IMU to maximize part availability (one or both may be populated)
ICM-20948
ICM-20789

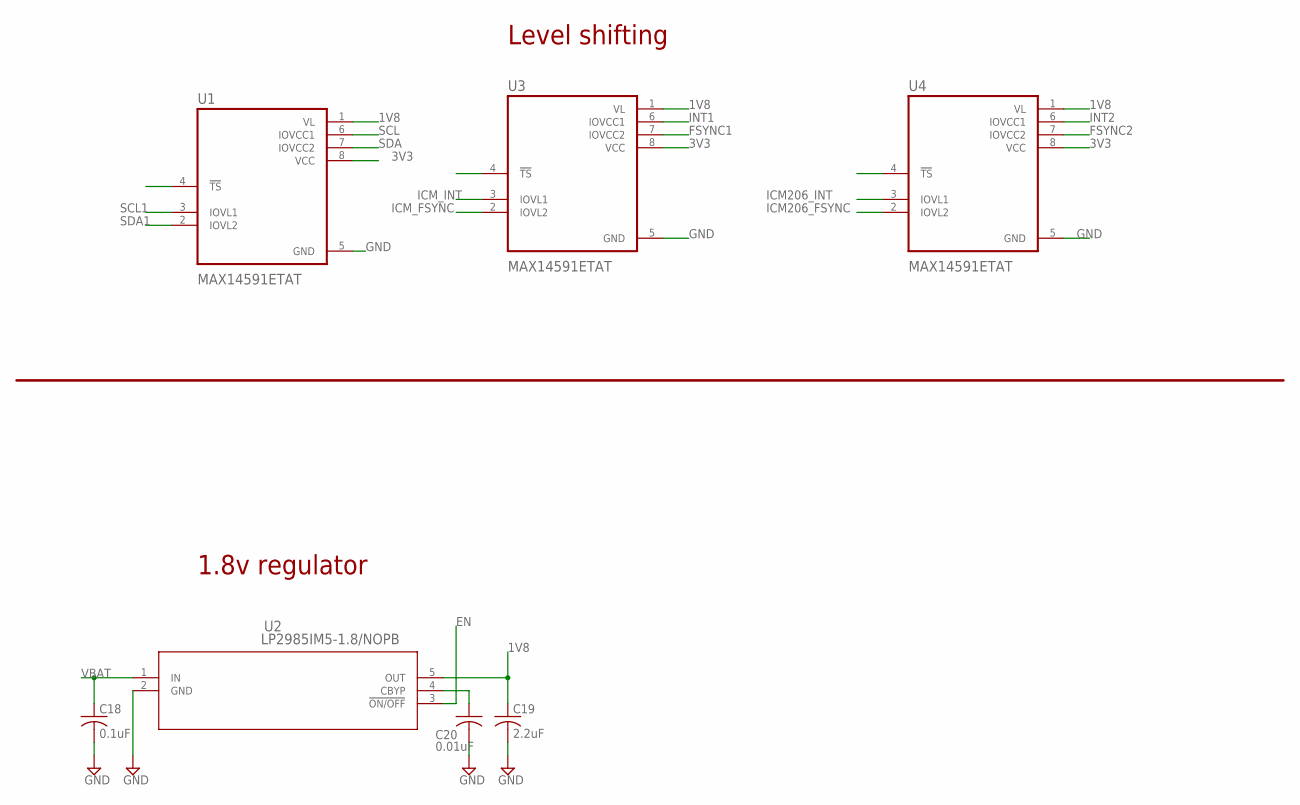
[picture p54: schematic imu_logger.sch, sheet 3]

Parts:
C18: 0.1uF; C0603
C19: 2.2uF; C0603
C20: 0.01uF; C0603
U1, U3, U4: MAX14591ETAT; SON50P200X200X80-8N
U2: LP2985IM5-1.8/NOPB; MF05A

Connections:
1V8: C19.1, U1.1 (VL), U2.5 (OUT), U3.1 (VL), U4.1 (VL); also elsewhere on the board
3V3: U1.8 (VCC), U3.8 (VCC), U4.8 (VCC); also elsewhere on the board
EN: U2.3 (!ON/OFF); also elsewhere on the board
FSYNC1: U3.7 (IOVCC2); also elsewhere on the board
FSYNC2: U4.7 (IOVCC2); also elsewhere on the board
GND: C18.2, C19.2, C20.2, U1.5 (GND), U2.2 (GND), U3.5 (GND), U4.5 (GND); also elsewhere on the board
ICM206_FSYNC: U4.2 (IOVL2); also elsewhere on the board
ICM206_INT: U4.3 (IOVL1); also elsewhere on the board
ICM_FSYNC: U3.2 (IOVL2); also elsewhere on the board
ICM_INT: U3.3 (IOVL1); also elsewhere on the board
INT1: U3.6 (IOVCC1); also elsewhere on the board
INT2: U4.6 (IOVCC1); also elsewhere on the board
unnamed: C20.1, U2.4 (CBYP)
SCL: U1.6 (IOVCC1); also elsewhere on the board
SCL1: U1.3 (IOVL1); also elsewhere on the board
SDA: U1.7 (IOVCC2); also elsewhere on the board
SDA1: U1.2 (IOVL2); also elsewhere on the board
VBAT: C18.1, U2.1 (IN); also elsewhere on the board

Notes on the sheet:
Level shifting
1.8v regulator

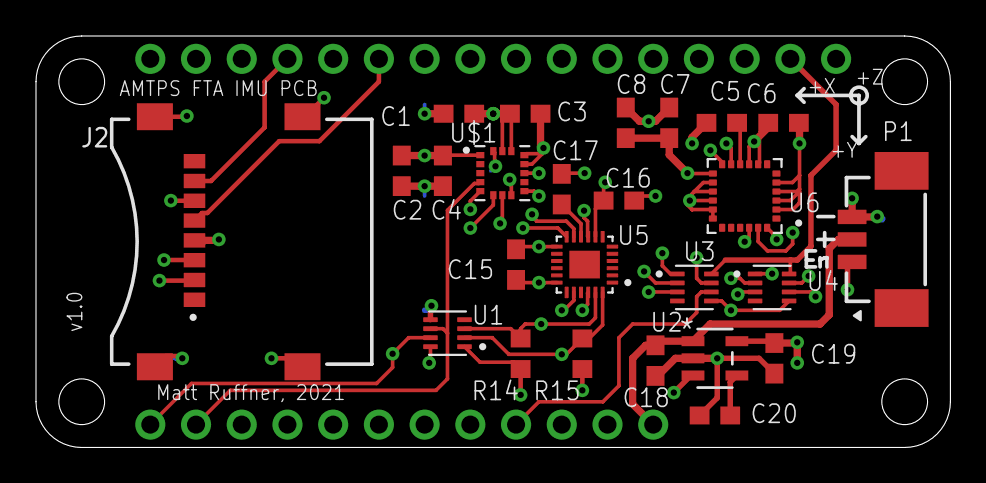
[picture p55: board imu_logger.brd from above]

Board: 4 copper layers, 50.8 x 22.9 mm, 27 parts (0 on the bottom side), 26 nets.

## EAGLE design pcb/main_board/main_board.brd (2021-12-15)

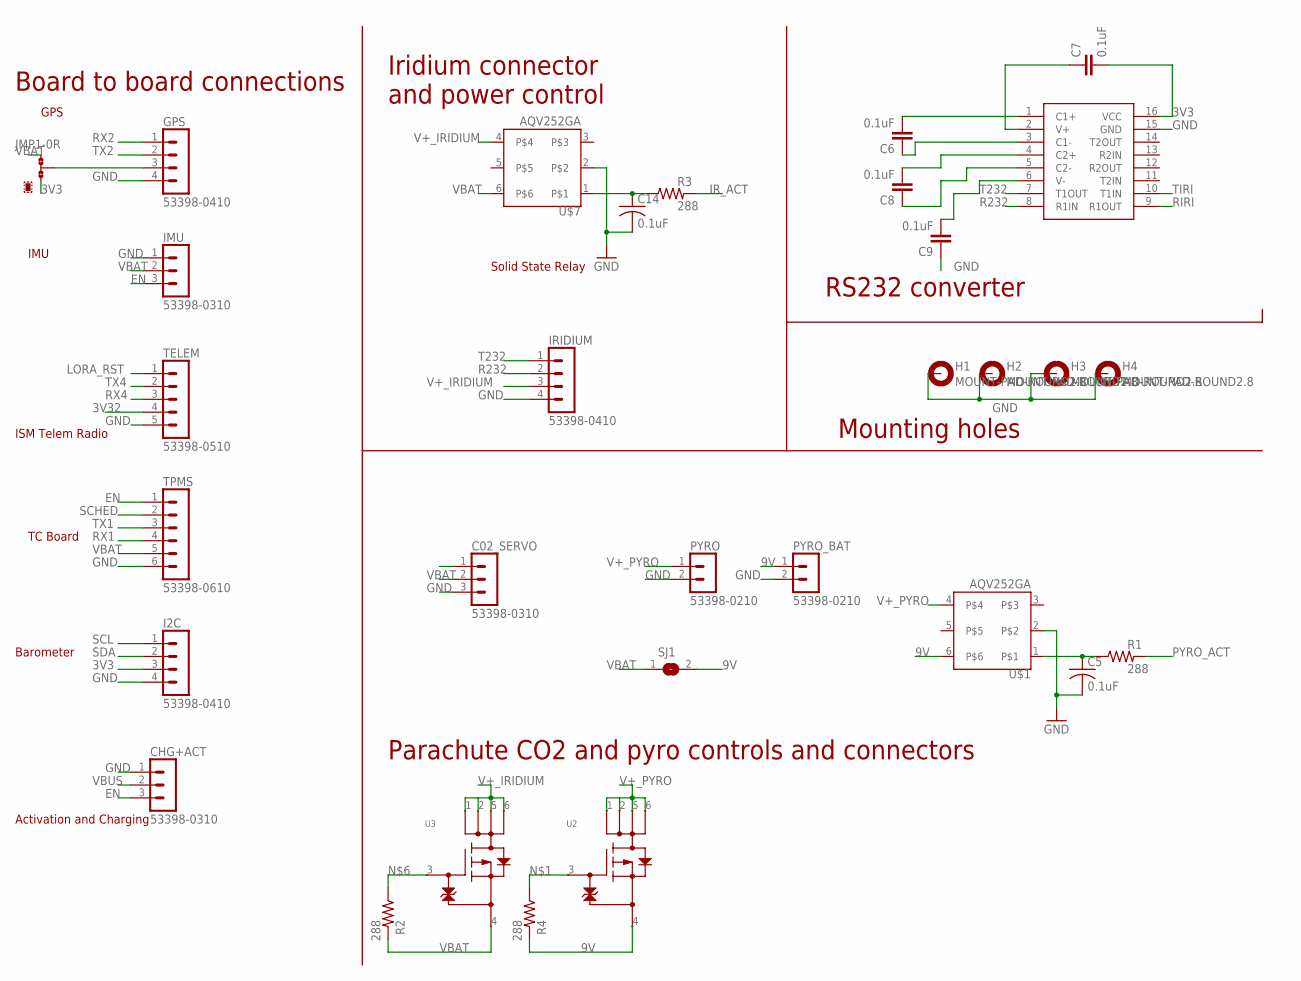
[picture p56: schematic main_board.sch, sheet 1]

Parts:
C02_SERVO: 53398-0310
C5, C6, C7, C8, C9, C14: 0.1uF; C0603
CHG+ACT: 53398-0310
GPS: 53398-0410
H1, H2, H3, H4: MOUNT-PAD-ROUND2.8; 2,8-PAD
I2C: 53398-0410
IMU: 53398-0310
IRIDIUM: 53398-0410
JMP1: 0R-JUMPA; A0R-JMP
PYRO: 53398-0210
PYRO_BAT: 53398-0210
R1, R2, R3, R4: 288; R0603
SJ1: SJ
TELEM: 53398-0510
TPMS: 53398-0610
U2, U3: SSM6J414TU; UF6_TOS
U$1, U$7: AQV252GA; DIP6
U$2: UM3232EEAE; RQ_16_ADI

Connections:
3V3: C7.2, I2C.3, JMP1.3, U$2.16 (VCC); also elsewhere on the board
3V32: TELEM.4; also elsewhere on the board
9V: PYRO_BAT.1, R4.2, SJ1.2, U2.4, U$1.6
CO2_SERVO: C02_SERVO.1; also elsewhere on the board
EN: CHG+ACT.3, IMU.3, TPMS.1; also elsewhere on the board
GND: C02_SERVO.3, C5.2, C9.1, C14.2, CHG+ACT.1, GPS.4, H1.B2,8, H2.B2,8, H3.B2,8, H4.B2,8, I2C.4, IMU.1, IRIDIUM.4, PYRO.2, PYRO_BAT.2, TELEM.5, TPMS.6, U$1.2, U$2.15 (GND), U$7.2; also elsewhere on the board
IR_ACT: R3.2; also elsewhere on the board
LORA_RST: TELEM.1; also elsewhere on the board
unnamed: C5.1, R1.1, R4.1, U2.3, U$1.1
unnamed: GPS.3, JMP1.2
unnamed: C6.2, U$2.1 (C1+)
unnamed: C14.1, R2.1, R3.1, U3.3, U$7.1
unnamed: C7.1, U$2.2 (V+)
unnamed: C6.1, U$2.3 (C1-)
unnamed: C8.2, U$2.4 (C2+)
unnamed: C8.1, U$2.5 (C2-)
unnamed: C9.2, U$2.6 (V-)
PYRO_ACT: R1.2; also elsewhere on the board
R232: IRIDIUM.2, U$2.8 (R1IN)
RIRI: U$2.9 (R1OUT); also elsewhere on the board
RX1: TPMS.4; also elsewhere on the board
RX2: GPS.1; also elsewhere on the board
RX4: TELEM.3; also elsewhere on the board
SCHED: TPMS.2; also elsewhere on the board
SCL: I2C.1; also elsewhere on the board
SDA: I2C.2; also elsewhere on the board
T232: IRIDIUM.1, U$2.7 (T1OUT)
TIRI: U$2.10 (T1IN); also elsewhere on the board
TX1: TPMS.3; also elsewhere on the board
TX2: GPS.2; also elsewhere on the board
TX4: TELEM.2; also elsewhere on the board
V+_IRIDIUM: IRIDIUM.3, U3.1, U3.2, U3.5, U3.6, U$7.4
V+_PYRO: PYRO.1, U2.1, U2.2, U2.5, U2.6, U$1.4
VBAT: C02_SERVO.2, IMU.2, JMP1.1, R2.2, SJ1.1, TPMS.5, U3.4, U$7.6; also elsewhere on the board
VBUS: CHG+ACT.2; also elsewhere on the board

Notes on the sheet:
GPS
TC Board
Solid State Relay
Board to board connections
IMU
ISM Telem Radio
Barometer
Activation and Charging
Iridium connector and power control
RS232 converter
Mounting holes
Parachute CO2 and pyro controls and connectors

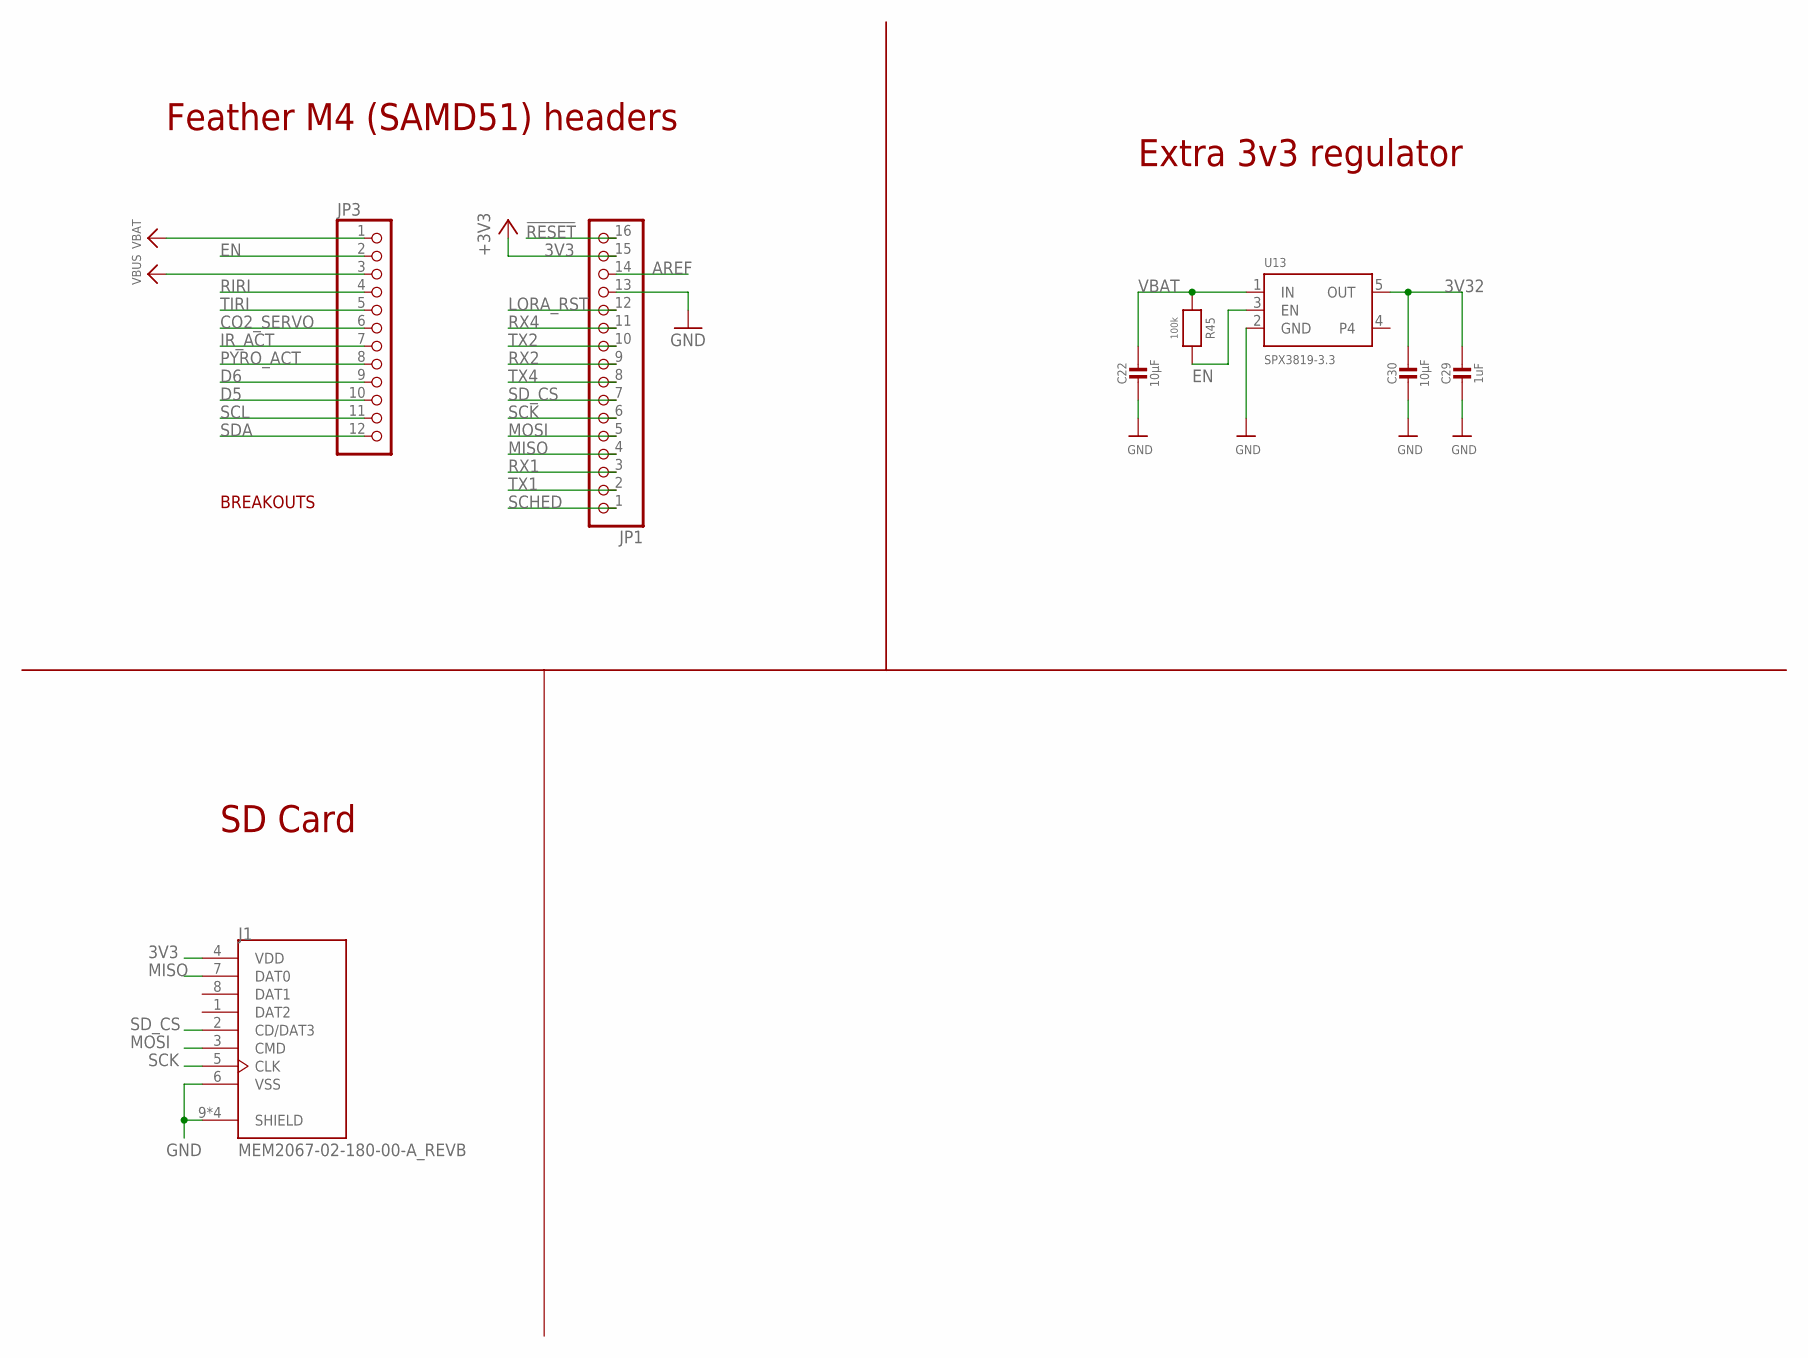
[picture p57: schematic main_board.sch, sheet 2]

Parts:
C22, C30: 10µF; 0805-NO
C29: 1uF; 0603-NO
J1: MEM2067-02-180-00-A_REVB; GCT_MEM2067-02-180-00-A_REVB
JP1: HEADER-1X16ROUND; 1X16_ROUND
JP3: HEADER-1X12; 1X12_ROUND
R45: 100k; 0603-NO
U13: SPX3819-3.3; SOT23-5

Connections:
3V3: J1.4 (VDD), JP1.15; also elsewhere on the board
3V32: C29.1, C30.1, U13.5 (OUT); also elsewhere on the board
!RESET: JP1.16
AREF: JP1.14
CO2_SERVO: JP3.6; also elsewhere on the board
D5: JP3.10
D6: JP3.9
EN: JP3.2, R45.2, U13.3 (EN); also elsewhere on the board
GND: C22.2, C29.2, C30.2, J1.6 (VSS), J1.9 (SHIELD), J1.10 (SHIELD), J1.11 (SHIELD), J1.12 (SHIELD), JP1.13, U13.2 (GND); also elsewhere on the board
IR_ACT: JP3.7; also elsewhere on the board
LORA_RST: JP1.12; also elsewhere on the board
MISO: J1.7 (DAT0), JP1.4
MOSI: J1.3 (CMD), JP1.5
PYRO_ACT: JP3.8; also elsewhere on the board
RIRI: JP3.4; also elsewhere on the board
RX1: JP1.3; also elsewhere on the board
RX2: JP1.9; also elsewhere on the board
RX4: JP1.11; also elsewhere on the board
SCHED: JP1.1; also elsewhere on the board
SCK: J1.5 (CLK), JP1.6
SCL: JP3.11; also elsewhere on the board
SDA: JP3.12; also elsewhere on the board
SD_CS: J1.2 (CD/DAT3), JP1.7
TIRI: JP3.5; also elsewhere on the board
TX1: JP1.2; also elsewhere on the board
TX2: JP1.10; also elsewhere on the board
TX4: JP1.8; also elsewhere on the board
VBAT: C22.1, JP3.1, R45.1, U13.1 (IN); also elsewhere on the board
VBUS: JP3.3; also elsewhere on the board

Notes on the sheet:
BREAKOUTS
Feather M4 (SAMD51) headers
Extra 3v3 regulator
SD Card

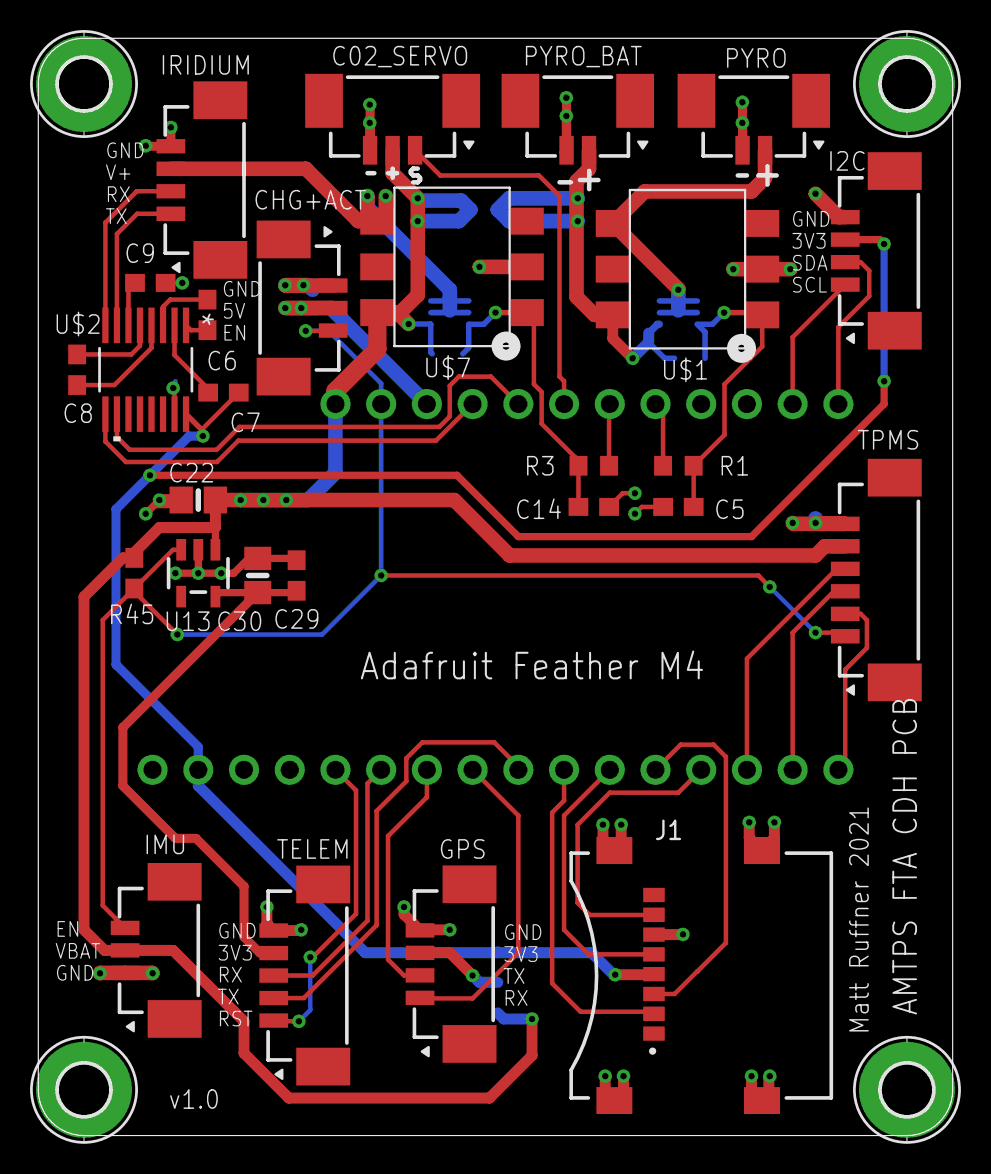
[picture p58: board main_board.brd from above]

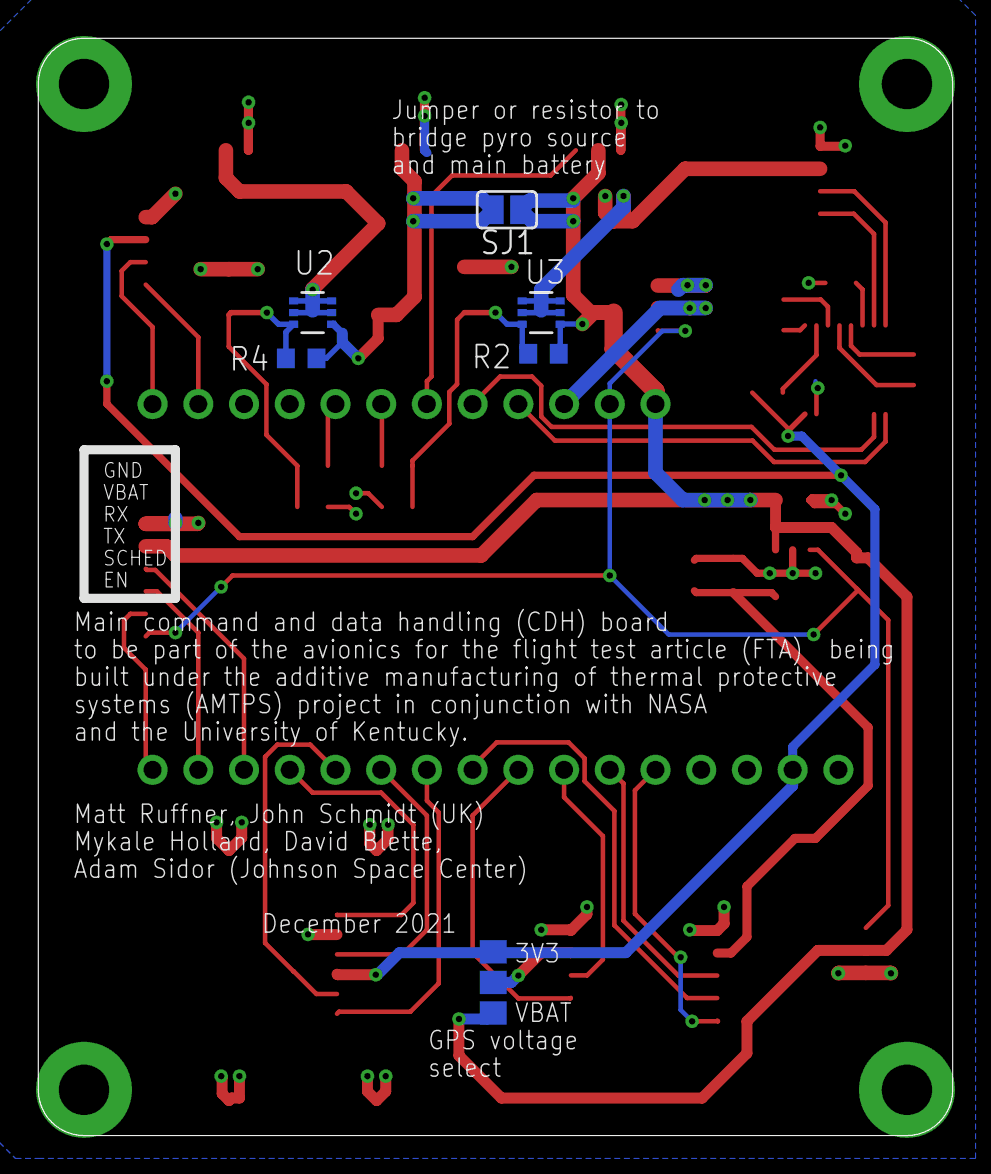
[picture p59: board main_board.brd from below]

Board: 4 copper layers, 50.8 x 61.0 mm, 39 parts (6 on the bottom side), 39 nets.

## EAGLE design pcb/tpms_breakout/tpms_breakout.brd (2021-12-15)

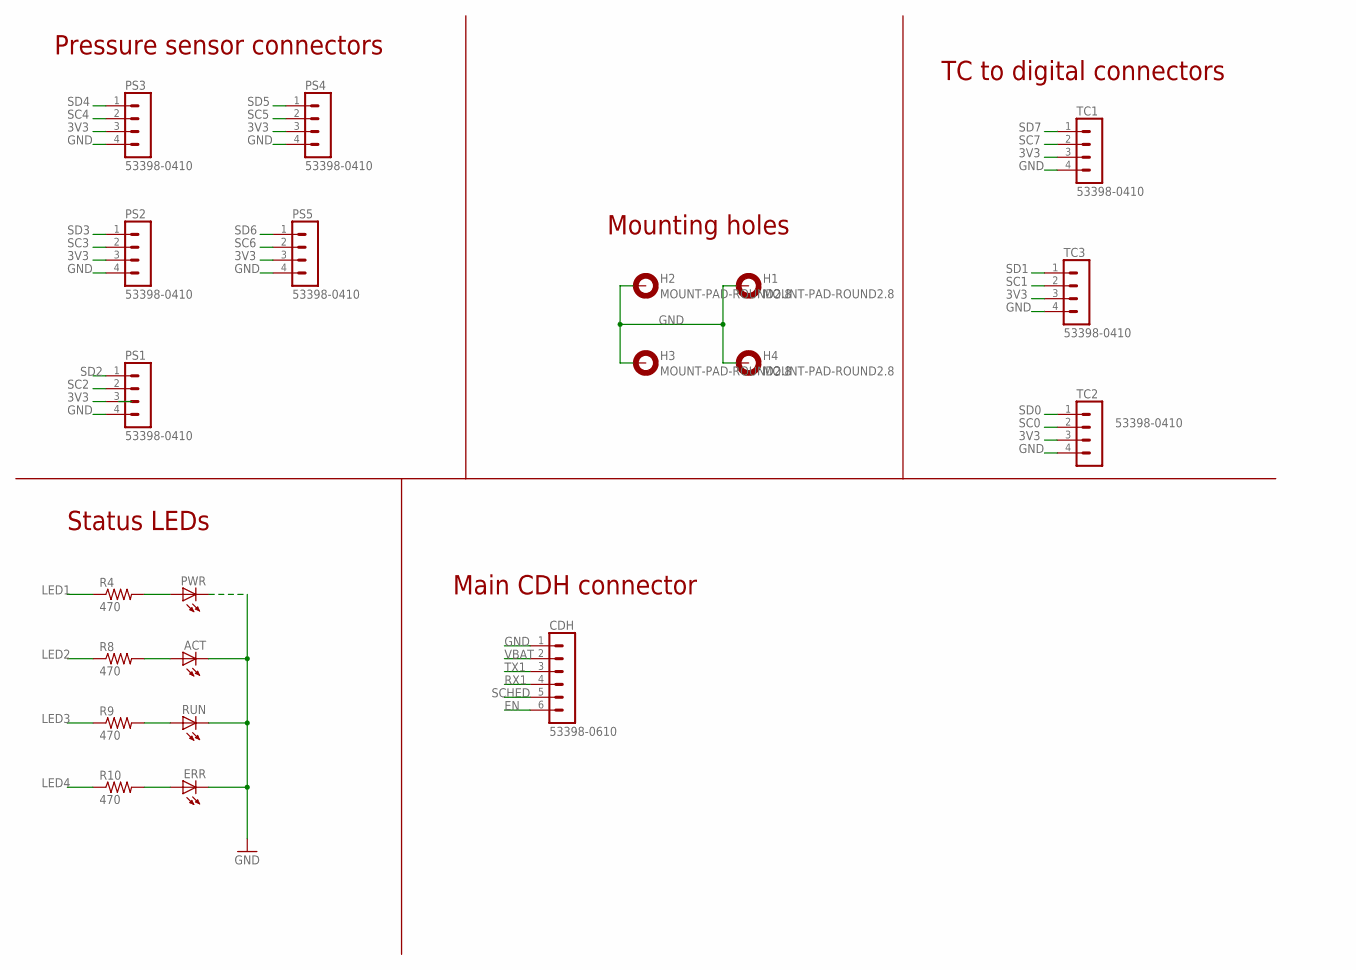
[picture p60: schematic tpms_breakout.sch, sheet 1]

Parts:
ACT: LEDCHIP-LED0603; CHIP-LED0603
CDH: 53398-0610
ERR: LEDCHIP-LED0603; CHIP-LED0603
H1, H2, H3, H4: MOUNT-PAD-ROUND2.8; 2,8-PAD
PS1, PS2, PS3, PS4, PS5: 53398-0410
PWR: LEDCHIP-LED0603; CHIP-LED0603
R4, R8, R9, R10: 470; R0603
RUN: LEDCHIP-LED0603; CHIP-LED0603
TC1, TC2, TC3: 53398-0410

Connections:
3V3: PS1.3, PS2.3, PS3.3, PS4.3, PS5.3, TC1.3, TC2.3, TC3.3; also elsewhere on the board
EN: CDH.6; also elsewhere on the board
GND: ACT.C, CDH.1, ERR.C, H1.B2,8, H2.B2,8, H3.B2,8, H4.B2,8, PS1.4, PS2.4, PS3.4, PS4.4, PS5.4, PWR.C, RUN.C, TC1.4, TC2.4, TC3.4; also elsewhere on the board
LED1: R4.1; also elsewhere on the board
LED2: R8.1; also elsewhere on the board
LED3: R9.1; also elsewhere on the board
LED4: R10.1; also elsewhere on the board
unnamed: PWR.A, R4.2
unnamed: ACT.A, R8.2
unnamed: R9.2, RUN.A
unnamed: ERR.A, R10.2
RX1: CDH.4; also elsewhere on the board
SC0: TC2.2; also elsewhere on the board
SC1: TC3.2; also elsewhere on the board
SC2: PS1.2; also elsewhere on the board
SC3: PS2.2; also elsewhere on the board
SC4: PS3.2; also elsewhere on the board
SC5: PS4.2; also elsewhere on the board
SC6: PS5.2; also elsewhere on the board
SC7: TC1.2; also elsewhere on the board
SCHED: CDH.5; also elsewhere on the board
SD0: TC2.1; also elsewhere on the board
SD1: TC3.1; also elsewhere on the board
SD2: PS1.1; also elsewhere on the board
SD3: PS2.1; also elsewhere on the board
SD4: PS3.1; also elsewhere on the board
SD5: PS4.1; also elsewhere on the board
SD6: PS5.1; also elsewhere on the board
SD7: TC1.1; also elsewhere on the board
TX1: CDH.3; also elsewhere on the board
VBAT: CDH.2; also elsewhere on the board

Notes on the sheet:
Pressure sensor connectors
Mounting holes
TC to digital connectors
Main CDH connector
Status LEDs

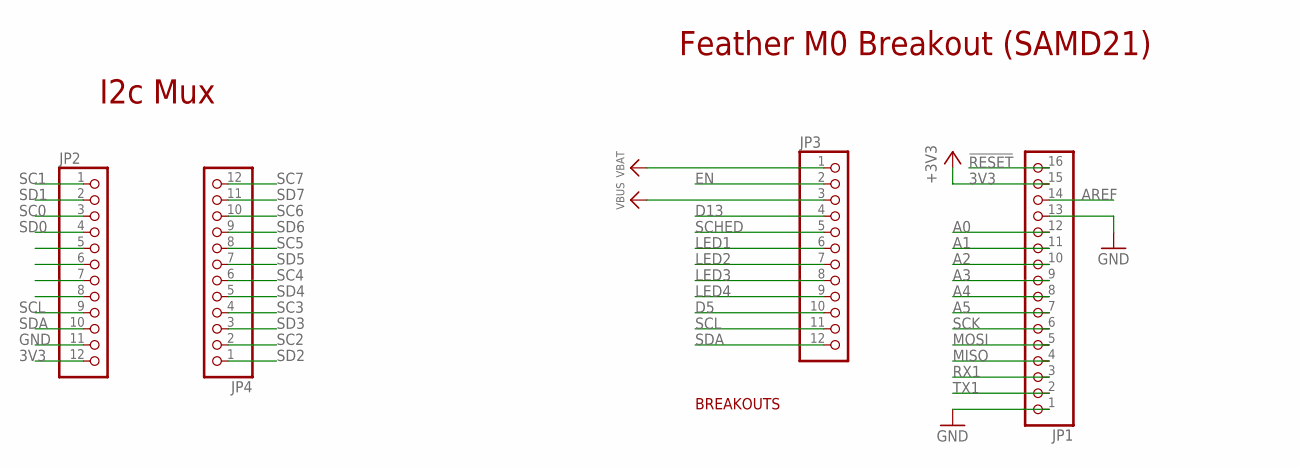
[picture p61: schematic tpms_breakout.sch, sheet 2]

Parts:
JP1: HEADER-1X16ROUND; 1X16_ROUND
JP2, JP3, JP4: HEADER-1X12; 1X12_ROUND

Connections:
3V3: JP1.15, JP2.12; also elsewhere on the board
!RESET: JP1.16
A0: JP1.12
A1: JP1.11
A2: JP1.10
A3: JP1.9
A4: JP1.8
A5: JP1.7
AREF: JP1.14
D5: JP3.10
D13: JP3.4
EN: JP3.2; also elsewhere on the board
GND: JP1.1, JP1.13, JP2.11; also elsewhere on the board
LED1: JP3.6; also elsewhere on the board
LED2: JP3.7; also elsewhere on the board
LED3: JP3.8; also elsewhere on the board
LED4: JP3.9; also elsewhere on the board
MISO: JP1.4
MOSI: JP1.5
RX1: JP1.3; also elsewhere on the board
SC0: JP2.3; also elsewhere on the board
SC1: JP2.1; also elsewhere on the board
SC2: JP4.2; also elsewhere on the board
SC3: JP4.4; also elsewhere on the board
SC4: JP4.6; also elsewhere on the board
SC5: JP4.8; also elsewhere on the board
SC6: JP4.10; also elsewhere on the board
SC7: JP4.12; also elsewhere on the board
SCHED: JP3.5; also elsewhere on the board
SCK: JP1.6
SCL: JP2.9, JP3.11
SD0: JP2.4; also elsewhere on the board
SD1: JP2.2; also elsewhere on the board
SD2: JP4.1; also elsewhere on the board
SD3: JP4.3; also elsewhere on the board
SD4: JP4.5; also elsewhere on the board
SD5: JP4.7; also elsewhere on the board
SD6: JP4.9; also elsewhere on the board
SD7: JP4.11; also elsewhere on the board
SDA: JP2.10, JP3.12
TX1: JP1.2; also elsewhere on the board
VBAT: JP3.1; also elsewhere on the board
VBUS: JP3.3

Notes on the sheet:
BREAKOUTS
I2c Mux
Feather M0 Breakout (SAMD21)

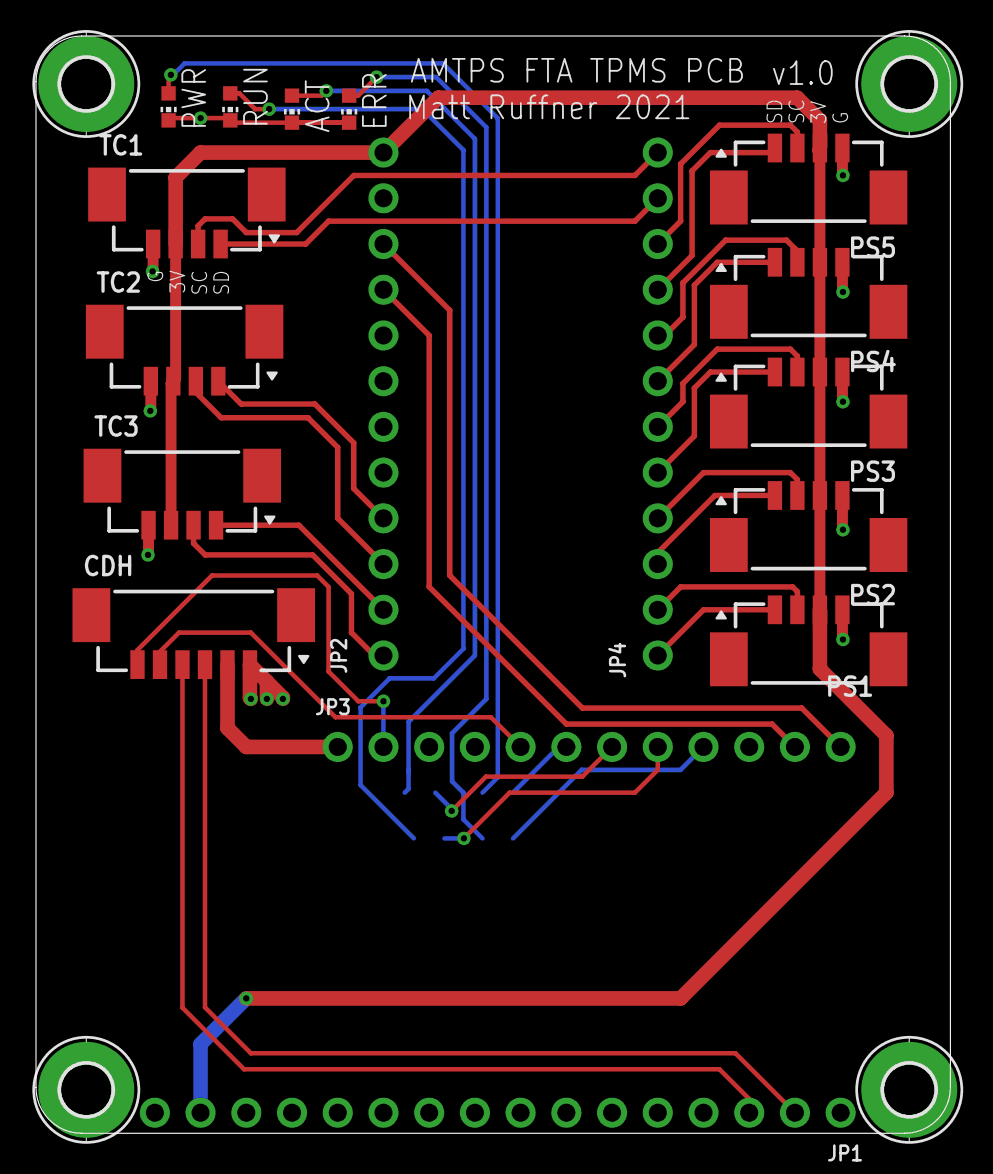
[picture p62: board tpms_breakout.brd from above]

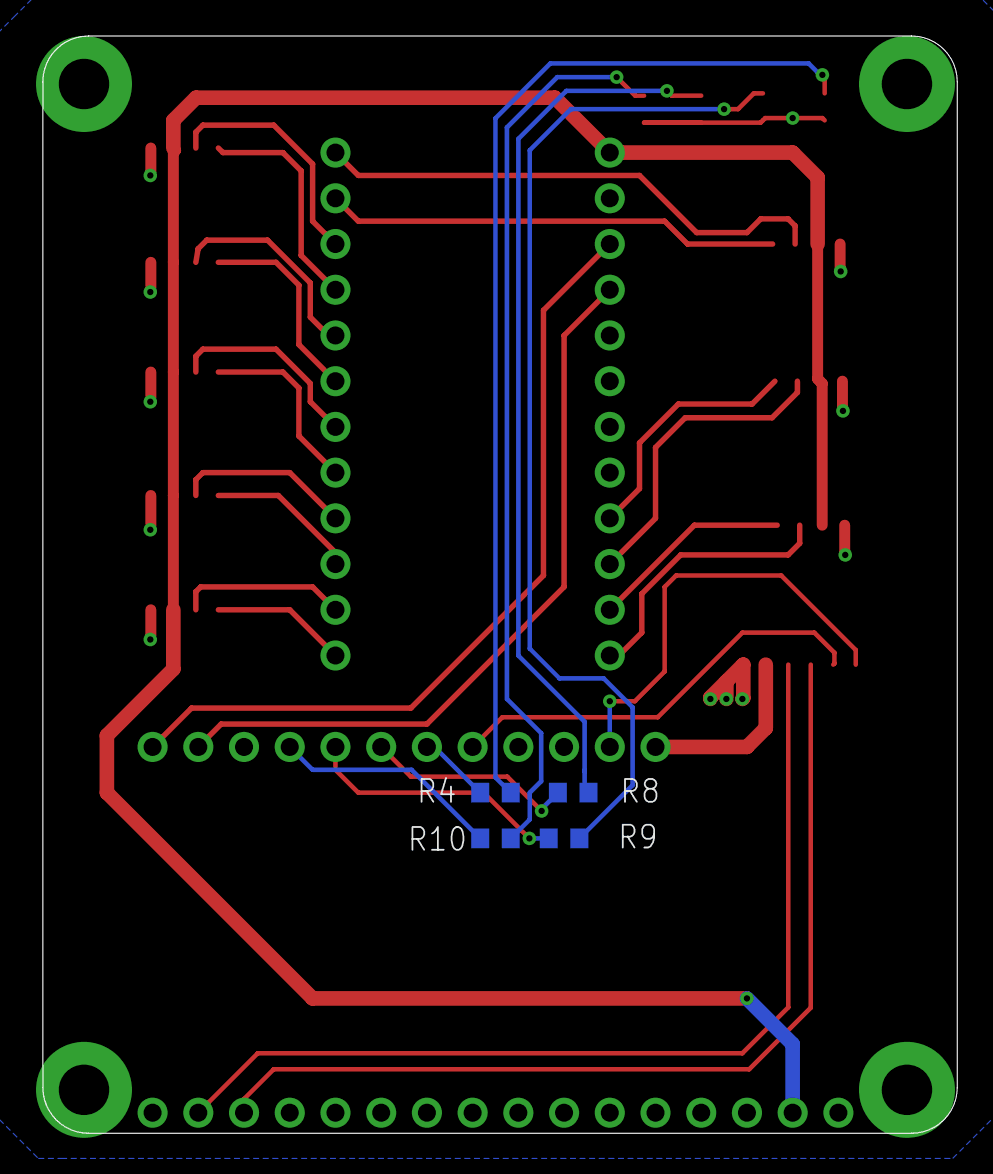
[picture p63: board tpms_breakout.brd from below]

Board: 2 copper layers, 50.8 x 61.0 mm, 25 parts (4 on the bottom side), 33 nets.

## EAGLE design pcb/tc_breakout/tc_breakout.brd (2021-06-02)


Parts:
C10, C11, C12, C13, C14, C15, C23, C24, C25, C26, C27, C28: 0.1uF; C0603
J1, J2, J3, J4, J5, J12: 282836-2; CONN_282836-2
R13, R14, R15, R16, R17, R18, R19, R20, R21, R22, R23, R24: 100; R0603
R25, R31, R35, R39: 10k; R0603
R26: 13k; R0603
R32: 7.5k; R0603
R36: 4.3k; R0603
R40: 2.2k; R0603
U4, U5, U7, U8, U9, U10: MCP96L00T-E/MX; QFN65P500X500X100-21N_MCP96L00T-E/MX

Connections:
3V3: C23.1, C24.1, C25.1, C26.1, C27.1, C28.1, R25.1, R31.1, R35.1, R39.1, U4.8 (VDD), U5.8 (VDD), U7.8 (VDD), U8.8 (VDD), U8.16 (ADDR), U9.8 (VDD), U10.8 (VDD); also elsewhere on the board
GND: C23.2, C24.2, C25.2, C26.2, C27.2, C28.2, R26.1, R32.1, R36.1, R40.1, U4.1 (GND), U4.3 (GND), U4.5 (GND), U4.6 (GND), U4.7 (GND), U4.9 (GND), U4.10 (GND), U4.13 (GND), U4.17 (GND), U4.18 (GND), U4.21 (EXP), U4.22 (EXP), U4.23 (EXP), U4.24 (EXP), U4.25 (EXP), U4.26 (EXP), U4.27 (EXP), U4.28 (EXP), U4.29 (EXP), U4.30 (EXP), U5.1 (GND), U5.3 (GND), U5.5 (GND), U5.6 (GND), U5.7 (GND), U5.9 (GND), U5.10 (GND), U5.13 (GND), U5.17 (GND), U5.18 (GND), U5.21 (EXP), U5.22 (EXP), U5.23 (EXP), U5.24 (EXP), U5.25 (EXP), U5.26 (EXP), U5.27 (EXP), U5.28 (EXP), U5.29 (EXP), U5.30 (EXP), U7.1 (GND), U7.3 (GND), U7.5 (GND), U7.6 (GND), U7.7 (GND), U7.9 (GND), U7.10 (GND), U7.13 (GND), U7.16 (ADDR), U7.17 (GND), U7.18 (GND), U7.21 (EXP), U7.22 (EXP), U7.23 (EXP), U7.24 (EXP), U7.25 (EXP), U7.26 (EXP), U7.27 (EXP), U7.28 (EXP), U7.29 (EXP), U7.30 (EXP), U8.1 (GND), U8.3 (GND), U8.5 (GND), U8.6 (GND), U8.7 (GND), U8.9 (GND), U8.10 (GND), U8.13 (GND), U8.17 (GND), U8.18 (GND), U8.21 (EXP), U8.22 (EXP), U8.23 (EXP), U8.24 (EXP), U8.25 (EXP), U8.26 (EXP), U8.27 (EXP), U8.28 (EXP), U8.29 (EXP), U8.30 (EXP), U9.1 (GND), U9.3 (GND), U9.5 (GND), U9.6 (GND), U9.7 (GND), U9.9 (GND), U9.10 (GND), U9.13 (GND), U9.17 (GND), U9.18 (GND), U9.21 (EXP), U9.22 (EXP), U9.23 (EXP), U9.24 (EXP), U9.25 (EXP), U9.26 (EXP), U9.27 (EXP), U9.28 (EXP), U9.29 (EXP), U9.30 (EXP), U10.1 (GND), U10.3 (GND), U10.5 (GND), U10.6 (GND), U10.7 (GND), U10.9 (GND), U10.10 (GND), U10.13 (GND), U10.17 (GND), U10.18 (GND), U10.21 (EXP), U10.22 (EXP), U10.23 (EXP), U10.24 (EXP), U10.25 (EXP), U10.26 (EXP), U10.27 (EXP), U10.28 (EXP), U10.29 (EXP), U10.30 (EXP); also elsewhere on the board
unnamed: J1.1, R13.1
unnamed: J1.2, R14.1
unnamed: J12.1, R23.1
unnamed: C10.1, R13.2, U4.2 (VIN+)
unnamed: C10.2, R14.2, U4.4 (VIN-)
unnamed: J2.1, R15.1
unnamed: J2.2, R16.1
unnamed: J3.1, R17.1
unnamed: J3.2, R18.1
unnamed: J4.2, R19.1
unnamed: J4.1, R20.1
unnamed: J5.2, R21.1
unnamed: J5.1, R22.1
unnamed: J12.2, R24.1
unnamed: C12.1, R20.2, U7.2 (VIN+)
unnamed: C12.2, R19.2, U7.4 (VIN-)
unnamed: C15.1, R23.2, U8.2 (VIN+)
unnamed: C14.2, R21.2, U10.4 (VIN-)
unnamed: C15.2, R24.2, U8.4 (VIN-)
unnamed: C14.1, R22.2, U10.2 (VIN+)
unnamed: C13.1, R17.2, U9.2 (VIN+)
unnamed: C13.2, R18.2, U9.4 (VIN-)
unnamed: C11.1, R15.2, U5.2 (VIN+)
unnamed: C11.2, R16.2, U5.4 (VIN-)
unnamed: R25.2, R26.2, U5.16 (ADDR)
unnamed: R31.2, R32.2, U9.16 (ADDR)
unnamed: R35.2, R36.2, U4.16 (ADDR)
unnamed: R39.2, R40.2, U10.16 (ADDR)
SCL1: U4.19 (SCL), U5.19 (SCL), U7.19 (SCL), U8.19 (SCL), U9.19 (SCL), U10.19 (SCL); also elsewhere on the board
SDA1: U4.20 (SDA), U5.20 (SDA), U7.20 (SDA), U8.20 (SDA), U9.20 (SDA), U10.20 (SDA); also elsewhere on the board

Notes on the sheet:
TC to Digital ADDR=0x60
TC to Digital ADDR=0x61
TC to Digital ADDR=0x62
TC to Digital ADDR=0x67
TC to Digital ADDR=0x63
TC to Digital ADDR=0x64
amtpsfta-tc-breakout-01


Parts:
C22, C30: 10µF; 0805-NO
C29: 1uF; 0603-NO
H1, H2, H3, H4: MOUNT-PAD-ROUND3.0; 3,0-PAD
P2: 53398-0510
P3: 53398-0410
R45: 100k; 0603-NO
U13: SPX3819-3.3; SOT23-5

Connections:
3V3: C29.1, C30.1, P3.3, U13.5 (OUT); also elsewhere on the board
EN: P2.4, R45.2, U13.3 (EN)
GND: C22.2, C29.2, C30.2, H1.B3,0, H2.B3,0, H3.B3,0, H4.B3,0, P2.1, P3.4, U13.2 (GND); also elsewhere on the board
SCL1: P2.2, P3.1; also elsewhere on the board
SDA1: P2.3, P3.2; also elsewhere on the board
VBAT: C22.1, P2.5, R45.1, U13.1 (IN)

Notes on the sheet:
Mounting Holes
Voltage in and enable
Downstream I2C connections
Voltage regulation and filtering
amtpsfta-tc-breakout-01



Board: 2 copper layers, 55.9 x 34.0 mm, 55 parts (6 on the bottom side), 34 nets.

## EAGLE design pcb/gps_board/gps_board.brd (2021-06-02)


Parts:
ANT: U.FL-R-SMT-1(10); CONN_R-SMT-1(10)
C1: 10uF; C0603
C2: 1uF; C0603
C3: 0.1uF; C0603
CON1: 53398-0810
H1, H2, H3, H4: MOUNT-PAD-ROUND3.0; 3,0-PAD
L1: BLM15HB121SN1; 0402
U$1: RXM-GPS-FM

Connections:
3V3: C1.1, C2.1, C3.1, CON1.7, U$1.P$10 (VCC)
GND: ANT.2, ANT.3, C1.2, C2.2, C3.2, CON1.8, H1.B3,0, H2.B3,0, H3.B3,0, H4.B3,0, U$1.P$5 (GND), U$1.P$14 (GND), U$1.P$17 (GND), U$1.P$22 (GND)
LCK: CON1.4, U$1.P$7 (LCKIND)
unnamed: L1.1, U$1.P$16 (VOUT)
PPS: CON1.1, U$1.P$2 (1PPS)
RF: ANT.1, L1.2, U$1.P$18 (RFIN)
RST: CON1.5, U$1.P$8 (!RESET)
RX: CON1.3, U$1.P$4 (RX)
TX: CON1.2, U$1.P$3 (TX)


Board: 2 copper layers, 44.4 x 36.9 mm, 11 parts (0 on the bottom side), 9 nets.

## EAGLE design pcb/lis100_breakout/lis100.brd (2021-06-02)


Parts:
C1, C4: 0.1uF; C0603
C2, C3: 1uF; C0603
H1, H2, H3, H4: MOUNT-PAD-ROUND3.0; 3,0-PAD
P3: 53398-0410
U$1: H3LIS100DL; XDCR_LIS3DHTR

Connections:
3V3: C1.1, C2.1, C3.1, C4.1, P3.3, U$1.1, U$1.8, U$1.14, U$1.15
GND: C1.2, C2.2, C3.2, C4.2, H1.B3,0, H2.B3,0, H3.B3,0, H4.B3,0, P3.4, U$1.5, U$1.7, U$1.12, U$1.13, U$1.16
SCL1: P3.1, U$1.4
SDA1: P3.2, U$1.6


Board: 2 copper layers, 31.8 x 22.9 mm, 10 parts (0 on the bottom side), 4 nets.

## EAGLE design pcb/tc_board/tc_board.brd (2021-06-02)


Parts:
C1, C29: 1uF; 0603-NO
C2, C4: 22pF; 0603-NO
C22, C30: 10µF; 0805-NO
D1: MBR120; SOD-123
H1, H2, H3, H4: MOUNT-PAD-ROUND3.0; 3,0-PAD
P2: 53398-0510
PAD1, PAD2, PAD3, PAD4: SMD2; SMD1,27-2,54
R37, R38, R46, R47: 10k; 0603-NO
R45: 100k; 0603-NO
U13: SPX3819-3.3; SOT23-5
U$4: ATSAMD21G18_QFN; TQFN48_7MM
X2: 32.768; XTAL3215
X3: microUSB; 4UCONN_20329_V2

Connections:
3V3: C29.1, C30.1, R37.1, R38.1, R46.1, R47.1, U13.5 (OUT), U$4.6 (VDDA), U$4.17 (VDDIO), U$4.36 (VDDIO), U$4.44 (VDDIN); also elsewhere on the board
!RESET: PAD2.1, U$4.40 (/RESET)
A0: U$4.3 (PA02/EINT2/AIN0/Y0/VOUT)
A1: U$4.7 (PB08/I8/AIN2/SERCOM4.0)
A2: U$4.8 (PB09/I9/AIN3/SERCOM4.1)
A3: U$4.9 (PA04/EINT4/VREFB/AIN4/SERCOM0.0)
A4: U$4.10 (PA05/EINT5/AIN5/SERCOM0.1)
A5: U$4.47 (PB02/I2/AIN10/SERCOM5.0)
AREF: U$4.4 (PA03/EINT3/VREFA/AIN1)
D2: U$4.23 (PA14/I14/SERCOM2+4.2)
D3: U$4.14 (PA09/I2C/I9/AIN17/SERCOM0+2.1/I2SMC)
D4: U$4.13 (PA08/I2C/AIN16/SERCOM0+2.0/I2SD1)
D5: U$4.24 (PA15/I15/SERCOM3+4.3)
D6: U$4.29 (PA20/I4/SERCOM3+5.2/I2SSC)
D7: U$4.30 (PA21/I5/SERCOM3+5.3/I2SFS0)
D8: U$4.11 (PA06/EINT6/AIN6/SERCOM0.2)
D9: U$4.12 (PA07/I7/AIN7/SERCOM0.3/I2SD0)
D10: U$4.27 (PA18/I2/SERCOM1+3.2)
D12: U$4.28 (PA19/I3/SERCOM1+3.3/I2SD0)
D+: U$4.34 (PA25/I13/SERCOM3+5.3/D+), X3.D+
D-: U$4.33 (PA24/I12/SERCOM3+5.2/D-), X3.D-
EN: P2.4, R45.2, U13.3 (EN)
GND: C1.2, C2.2, C4.2, C22.2, C29.2, C30.2, H1.B3,0, H2.B3,0, H3.B3,0, H4.B3,0, P2.1, PAD1.1, U13.2 (GND), U$4.5 (GNDA), U$4.18 (GND), U$4.35 (GND), U$4.42 (GND), U$4.THERMAL (GND), X3.BASE@1 (GND), X3.BASE@2 (GND), X3.GND, X3.SPRT@1 (GND), X3.SPRT@2 (GND), X3.SPRT@3 (GND), X3.SPRT@4 (GND); also elsewhere on the board
MISO: U$4.21 (PA12/I12/I2C/SERCOM2+4.0)
MOSI: U$4.19 (PB10/I10/SERCOM4.2/I2SMC)
unnamed: C2.1, U$4.1 (PA00/EINT0/SERCOM1.0), X2.P$1
unnamed: C4.1, U$4.2 (PA01/EINT1/SERCOM1.1), X2.P$2
RX: P2.3, U$4.16 (PA11/I11/AIN19/SERCOM0+2.3/I2SF0)
SCK: U$4.20 (PB11/I11/SERCOM4.3/I2SCL)
SCL1: R38.2, U$4.32 (PA23/I2C/I7/SERCOM3+5.1/SOF); also elsewhere on the board
SCL2: R47.2, U$4.26 (PA17/I2C/I1/SERCOM1+3.1); also elsewhere on the board
SDA1: R37.2, U$4.31 (PA22/I2C/I6/SERCOM3+5.0); also elsewhere on the board
SDA2: R46.2, U$4.25 (PA16/I2C/I0/SERCOM1+3.0); also elsewhere on the board
SWCLK: PAD3.1, U$4.45 (PA30/I10/SECOM1.2/SWCLK)
SWDIO: PAD4.1, U$4.46 (PA31/I11/SECOM1.3/SWDIO)
TX: P2.2, U$4.15 (PA10/I10/AIN18/SERCOM0+2.2/I2SCK)
VBAT: D1.A, P2.5
VBUS: C22.1, D1.C, R45.1, U13.1 (IN), X3.VBUS
VDDCORE: C1.1, U$4.43 (VDDCORE)

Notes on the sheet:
N/C
TXLED
USBHOSTEN
RXLED
TXD
RXD


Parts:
C3, C5, C6, C7, C8, C9, C16, C17, C18, C19, C20, C21: 0.1uF; C0603
J6, J7, J8, J9, J10, J11: 282836-2; CONN_282836-2
R1, R2, R3, R4, R5, R6, R7, R8, R9, R10, R11, R12: 100; R0603
R27, R29, R33, R41, R43: 10k; R0603
R28: 4.3k; R0603
R30: 2.2k; R0603
R34, R44: 22k; R0603
R42: 12.7k; R0603
U1, U2, U3, U6, U11, U12: MCP96L00T-E/MX; QFN65P500X500X100-21N_MCP96L00T-E/MX

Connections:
3V3: C16.1, C17.1, C18.1, C19.1, C20.1, C21.1, R27.1, R29.1, R33.1, R41.1, R43.1, U1.8 (VDD), U2.8 (VDD), U3.8 (VDD), U6.8 (VDD), U11.8 (VDD), U12.8 (VDD); also elsewhere on the board
GND: C16.2, C17.2, C18.2, C19.2, C20.2, C21.2, R28.1, R30.1, R34.1, R42.1, R44.1, U1.1 (GND), U1.3 (GND), U1.5 (GND), U1.6 (GND), U1.7 (GND), U1.9 (GND), U1.10 (GND), U1.13 (GND), U1.16 (ADDR), U1.17 (GND), U1.18 (GND), U1.21 (EXP), U1.22 (EXP), U1.23 (EXP), U1.24 (EXP), U1.25 (EXP), U1.26 (EXP), U1.27 (EXP), U1.28 (EXP), U1.29 (EXP), U1.30 (EXP), U2.1 (GND), U2.3 (GND), U2.5 (GND), U2.6 (GND), U2.7 (GND), U2.9 (GND), U2.10 (GND), U2.13 (GND), U2.17 (GND), U2.18 (GND), U2.21 (EXP), U2.22 (EXP), U2.23 (EXP), U2.24 (EXP), U2.25 (EXP), U2.26 (EXP), U2.27 (EXP), U2.28 (EXP), U2.29 (EXP), U2.30 (EXP), U3.1 (GND), U3.3 (GND), U3.5 (GND), U3.6 (GND), U3.7 (GND), U3.9 (GND), U3.10 (GND), U3.13 (GND), U3.17 (GND), U3.18 (GND), U3.21 (EXP), U3.22 (EXP), U3.23 (EXP), U3.24 (EXP), U3.25 (EXP), U3.26 (EXP), U3.27 (EXP), U3.28 (EXP), U3.29 (EXP), U3.30 (EXP), U6.1 (GND), U6.3 (GND), U6.5 (GND), U6.6 (GND), U6.7 (GND), U6.9 (GND), U6.10 (GND), U6.13 (GND), U6.17 (GND), U6.18 (GND), U6.21 (EXP), U6.22 (EXP), U6.23 (EXP), U6.24 (EXP), U6.25 (EXP), U6.26 (EXP), U6.27 (EXP), U6.28 (EXP), U6.29 (EXP), U6.30 (EXP), U11.1 (GND), U11.3 (GND), U11.5 (GND), U11.6 (GND), U11.7 (GND), U11.9 (GND), U11.10 (GND), U11.13 (GND), U11.17 (GND), U11.18 (GND), U11.21 (EXP), U11.22 (EXP), U11.23 (EXP), U11.24 (EXP), U11.25 (EXP), U11.26 (EXP), U11.27 (EXP), U11.28 (EXP), U11.29 (EXP), U11.30 (EXP), U12.1 (GND), U12.3 (GND), U12.5 (GND), U12.6 (GND), U12.7 (GND), U12.9 (GND), U12.10 (GND), U12.13 (GND), U12.17 (GND), U12.18 (GND), U12.21 (EXP), U12.22 (EXP), U12.23 (EXP), U12.24 (EXP), U12.25 (EXP), U12.26 (EXP), U12.27 (EXP), U12.28 (EXP), U12.29 (EXP), U12.30 (EXP); also elsewhere on the board
unnamed: J6.1, R1.1
unnamed: J6.2, R2.1
unnamed: J9.1, R3.1
unnamed: J9.2, R4.1
unnamed: J10.1, R5.1
unnamed: J10.2, R6.1
unnamed: J11.1, R7.1
unnamed: J11.2, R8.1
unnamed: J8.1, R9.1
unnamed: J8.2, R10.1
unnamed: J7.2, R11.1
unnamed: J7.1, R12.1
unnamed: C6.1, R12.2, U3.2 (VIN+)
unnamed: C6.2, R11.2, U3.4 (VIN-)
unnamed: C3.2, R2.2, U1.4 (VIN-)
unnamed: C3.1, R1.2, U1.2 (VIN+)
unnamed: C5.1, R3.2, U2.2 (VIN+)
unnamed: C5.2, R4.2, U2.4 (VIN-)
unnamed: C8.1, R5.2, U6.2 (VIN+)
unnamed: C8.2, R6.2, U6.4 (VIN-)
unnamed: C9.1, R7.2, U12.2 (VIN+)
unnamed: C9.2, R8.2, U12.4 (VIN-)
unnamed: C7.2, R10.2, U11.4 (VIN-)
unnamed: C7.1, R9.2, U11.2 (VIN+)
unnamed: R27.2, R28.2, U3.16 (ADDR)
unnamed: R29.2, R30.2, U2.16 (ADDR)
unnamed: R33.2, R34.2, U6.16 (ADDR)
unnamed: R41.2, R42.2, U11.16 (ADDR)
unnamed: R43.2, R44.2, U12.16 (ADDR)
SCL1: U1.19 (SCL), U2.19 (SCL), U3.19 (SCL), U6.19 (SCL); also elsewhere on the board
SCL2: U11.19 (SCL), U12.19 (SCL); also elsewhere on the board
SDA1: U1.20 (SDA), U2.20 (SDA), U3.20 (SDA), U6.20 (SDA); also elsewhere on the board
SDA2: U11.20 (SDA), U12.20 (SDA); also elsewhere on the board

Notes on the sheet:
Address = 0 (0x60)
Address = 1 (0x61)
Address = 2 (0x62)
Address = 3 (0x63)


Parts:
C10, C11, C12, C13, C14, C15, C23, C24, C25, C26, C27, C28: 0.1uF; C0603
J1, J2, J3, J4, J5, J12: 282836-2; CONN_282836-2
R13, R14, R15, R16, R17, R18, R19, R20, R21, R22, R23, R24: 100; R0603
R25, R31, R35, R39: 10k; R0603
R26: 12.7k; R0603
R32: 4.3k; R0603
R36, R40: 7.87k; R0603
U4, U5, U7, U8, U9, U10: MCP96L00T-E/MX; QFN65P500X500X100-21N_MCP96L00T-E/MX

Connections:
3V3: C23.1, C24.1, C25.1, C26.1, C27.1, C28.1, R25.1, R31.1, R35.1, R39.1, U4.8 (VDD), U5.8 (VDD), U7.8 (VDD), U8.8 (VDD), U8.16 (ADDR), U9.8 (VDD), U10.8 (VDD); also elsewhere on the board
GND: C23.2, C24.2, C25.2, C26.2, C27.2, C28.2, R26.1, R32.1, R36.1, R40.1, U4.1 (GND), U4.3 (GND), U4.5 (GND), U4.6 (GND), U4.7 (GND), U4.9 (GND), U4.10 (GND), U4.13 (GND), U4.17 (GND), U4.18 (GND), U4.21 (EXP), U4.22 (EXP), U4.23 (EXP), U4.24 (EXP), U4.25 (EXP), U4.26 (EXP), U4.27 (EXP), U4.28 (EXP), U4.29 (EXP), U4.30 (EXP), U5.1 (GND), U5.3 (GND), U5.5 (GND), U5.6 (GND), U5.7 (GND), U5.9 (GND), U5.10 (GND), U5.13 (GND), U5.17 (GND), U5.18 (GND), U5.21 (EXP), U5.22 (EXP), U5.23 (EXP), U5.24 (EXP), U5.25 (EXP), U5.26 (EXP), U5.27 (EXP), U5.28 (EXP), U5.29 (EXP), U5.30 (EXP), U7.1 (GND), U7.3 (GND), U7.5 (GND), U7.6 (GND), U7.7 (GND), U7.9 (GND), U7.10 (GND), U7.13 (GND), U7.16 (ADDR), U7.17 (GND), U7.18 (GND), U7.21 (EXP), U7.22 (EXP), U7.23 (EXP), U7.24 (EXP), U7.25 (EXP), U7.26 (EXP), U7.27 (EXP), U7.28 (EXP), U7.29 (EXP), U7.30 (EXP), U8.1 (GND), U8.3 (GND), U8.5 (GND), U8.6 (GND), U8.7 (GND), U8.9 (GND), U8.10 (GND), U8.13 (GND), U8.17 (GND), U8.18 (GND), U8.21 (EXP), U8.22 (EXP), U8.23 (EXP), U8.24 (EXP), U8.25 (EXP), U8.26 (EXP), U8.27 (EXP), U8.28 (EXP), U8.29 (EXP), U8.30 (EXP), U9.1 (GND), U9.3 (GND), U9.5 (GND), U9.6 (GND), U9.7 (GND), U9.9 (GND), U9.10 (GND), U9.13 (GND), U9.17 (GND), U9.18 (GND), U9.21 (EXP), U9.22 (EXP), U9.23 (EXP), U9.24 (EXP), U9.25 (EXP), U9.26 (EXP), U9.27 (EXP), U9.28 (EXP), U9.29 (EXP), U9.30 (EXP), U10.1 (GND), U10.3 (GND), U10.5 (GND), U10.6 (GND), U10.7 (GND), U10.9 (GND), U10.10 (GND), U10.13 (GND), U10.17 (GND), U10.18 (GND), U10.21 (EXP), U10.22 (EXP), U10.23 (EXP), U10.24 (EXP), U10.25 (EXP), U10.26 (EXP), U10.27 (EXP), U10.28 (EXP), U10.29 (EXP), U10.30 (EXP); also elsewhere on the board
unnamed: J1.1, R13.1
unnamed: J1.2, R14.1
unnamed: J12.1, R23.1
unnamed: C10.1, R13.2, U4.2 (VIN+)
unnamed: C10.2, R14.2, U4.4 (VIN-)
unnamed: J2.1, R15.1
unnamed: J2.2, R16.1
unnamed: J3.1, R17.1
unnamed: J3.2, R18.1
unnamed: J4.2, R19.1
unnamed: J4.1, R20.1
unnamed: J5.2, R21.1
unnamed: J5.1, R22.1
unnamed: J12.2, R24.1
unnamed: C12.1, R20.2, U7.2 (VIN+)
unnamed: C12.2, R19.2, U7.4 (VIN-)
unnamed: C15.1, R23.2, U8.2 (VIN+)
unnamed: C14.2, R21.2, U10.4 (VIN-)
unnamed: C15.2, R24.2, U8.4 (VIN-)
unnamed: C14.1, R22.2, U10.2 (VIN+)
unnamed: C13.1, R17.2, U9.2 (VIN+)
unnamed: C13.2, R18.2, U9.4 (VIN-)
unnamed: C11.1, R15.2, U5.2 (VIN+)
unnamed: C11.2, R16.2, U5.4 (VIN-)
unnamed: R25.2, R26.2, U5.16 (ADDR)
unnamed: R31.2, R32.2, U9.16 (ADDR)
unnamed: R35.2, R36.2, U4.16 (ADDR)
unnamed: R39.2, R40.2, U10.16 (ADDR)
SCL1: U4.19 (SCL), U5.19 (SCL); also elsewhere on the board
SCL2: U7.19 (SCL), U8.19 (SCL), U9.19 (SCL), U10.19 (SCL); also elsewhere on the board
SDA1: U4.20 (SDA), U5.20 (SDA); also elsewhere on the board
SDA2: U7.20 (SDA), U8.20 (SDA), U9.20 (SDA), U10.20 (SDA); also elsewhere on the board

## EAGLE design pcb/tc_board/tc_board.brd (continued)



Board: 2 copper layers, 72.4 x 72.4 mm, 115 parts (4 on the bottom side), 76 nets.

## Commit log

2021-06-02 first rev of sensor evaluation and documentation
    [282836-2.stp, 475890001.stp, 532610871.stp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]
2021-06-02 add project schedule
    [tvac-20210602.csv]
2021-06-09 update resistor vals
2021-09-02 added new board models
    [Processor 1.step, Processor 2.step, gps_antenna.stp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]
2021-09-02 add more component cad
    [SD adapter.stp, iridium_antenna.stp, iridium_modem.stp]
2021-10-19 moved to feather wing design
    [main_board.brd, main_board.sch]
2021-10-19 add imu logger
    [imu_logger.brd, imu_logger.sch]
2021-10-19 add tpms breakout and libraries
    [tpms_breakout.brd, tpms_breakout.sch]
2021-10-19 initial versions of imu logger, cdh, and tpms pcb
    [imu_logger.brd, main_board.brd, main_board.sch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]
2021-12-15 finished TPMS board and other updates
    [imu_logger.brd, imu_logger.sch, main_board.brd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]
2021-12-15 updated main board to have new rs232 transceiver and optional mosfets for pyro and iridium power control
    [main_board.brd, main_board.sch]
2021-12-15 updated silkscreen and exported cam files for main board
    [main_board.brd, main_board.sch]
2021-12-15 add imu board cam files and replace sd card holder
    [imu_logger.brd, imu_logger.sch]
2022-02-02 add gimp of v1 board montage

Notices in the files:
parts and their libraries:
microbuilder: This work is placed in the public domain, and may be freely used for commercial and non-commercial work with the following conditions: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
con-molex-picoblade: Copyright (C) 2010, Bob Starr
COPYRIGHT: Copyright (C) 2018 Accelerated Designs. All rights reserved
